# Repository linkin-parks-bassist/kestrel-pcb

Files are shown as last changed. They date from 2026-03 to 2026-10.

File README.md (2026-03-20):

# Kestrel PCB
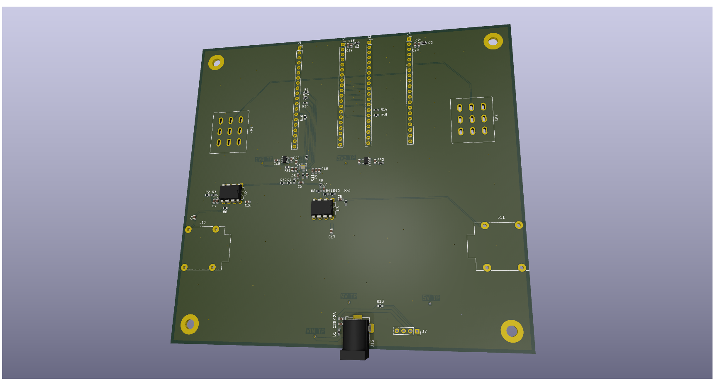
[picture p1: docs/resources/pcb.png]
KiCad


## Overview

This repository contains the KiCad design files for the main PCB used in Kestrel. The board integrates power distribution, audio I/O, and connectors for the Kestrel Core DSP module, Kestrel Interface control module, and a 5" LCD interface.

The PCB serves as the main carrier board for the system, providing regulated power rails, audio input/output stages, and interconnects between the DSP core, UI processor, and display.

## Dependencies

The board is designed to be used with the following additional components:

- Sipeed Tang Nano 20K (FPGA DSP core)
- Waveshare ESP32-P4-Pico (UI / control processor)
- Waveshare DSI-TOUCH-5A (5" MIPI-DSI display, connected to the ESP32-P4)
- Adafruit MPM3610 5V buck converter breakout

Note: the 5 V rail is currently generated using an external MPM3610 buck module. The PCB is designed so this can be replaced by an integrated regulator in a future revision.

## Power

The board is powered from a standard ***Center negative*** **9 V pedal supply**. The external buck module generates a 5V rail, from which the remaining rails are derived:

- 5 V (buck converter)
- 3.3 V 
- 1.8 V

## Project status

Prototype / Rev A. The design has not yet been manufactured and may change significantly.

## Files

This repository contains:

- KiCad schematic and PCB layout
- fabrication outputs (Gerbers, drill files) *to be added*
- board renders and screenshots

## Related projects

This board is part of Kestrel. Other repos in this project include

- [Main repo](https://github.com/linkin-parks-bassist/kestrel)
- [MCU repo](https://github.com/linkin-parks-bassist/kestrel-interface)
- [FPGA repo](https://github.com/linkin-parks-bassist/kestrel-core)

## License

GNU GPL 3.0

## Contact

I'd love to hear from you.  
email: davidjfarrell96@gmail.com

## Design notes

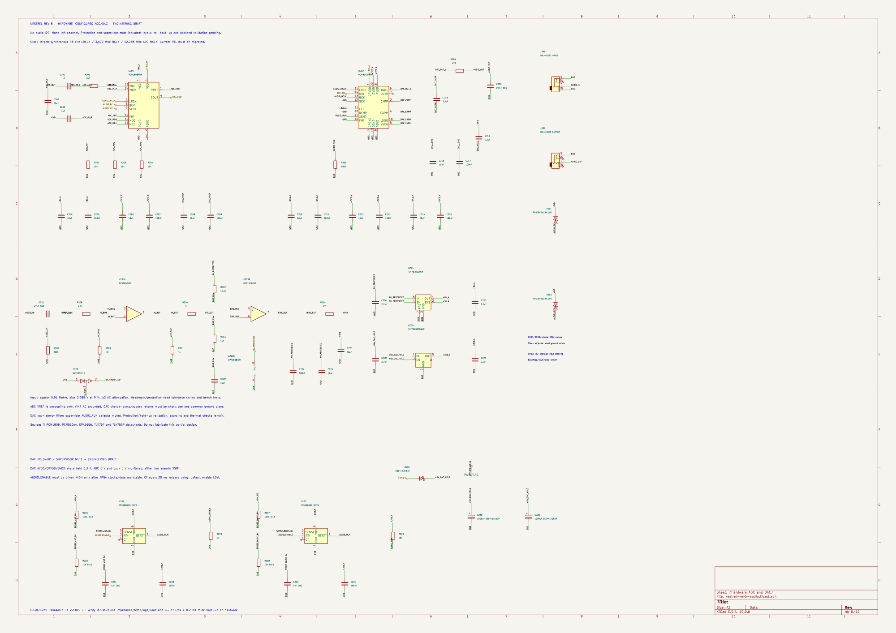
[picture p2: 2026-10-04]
rev-b/generated/review/kestrel-revb-Hardware ADC and DAC.png

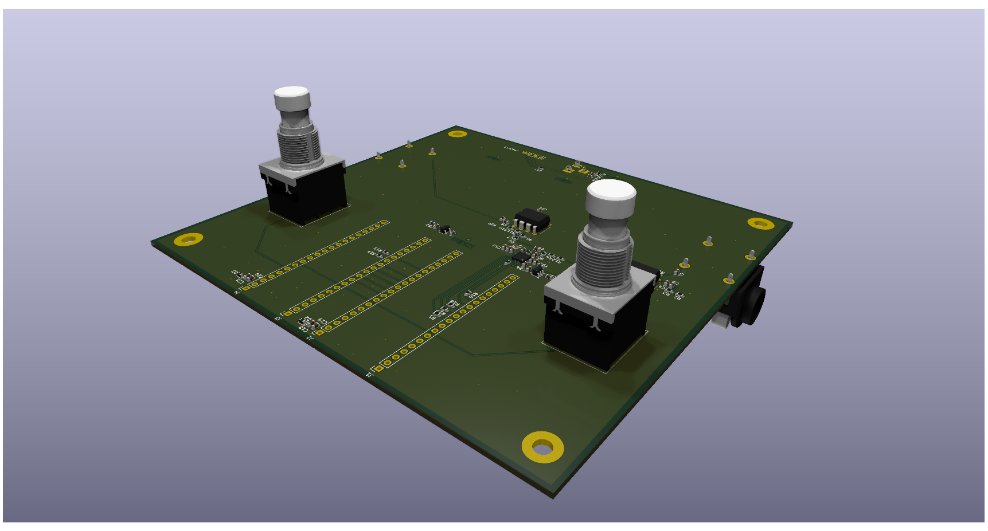
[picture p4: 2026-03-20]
docs/resources/kestrel_pcb_top.png

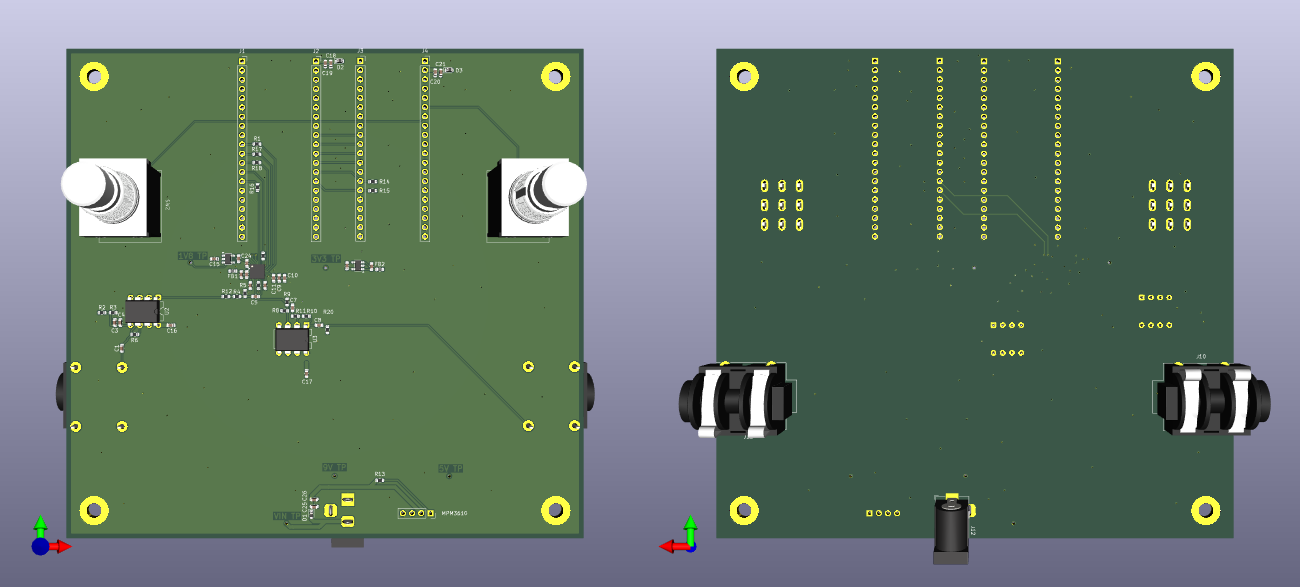
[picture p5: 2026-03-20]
docs/resources/kestrel_pcb_direct.png

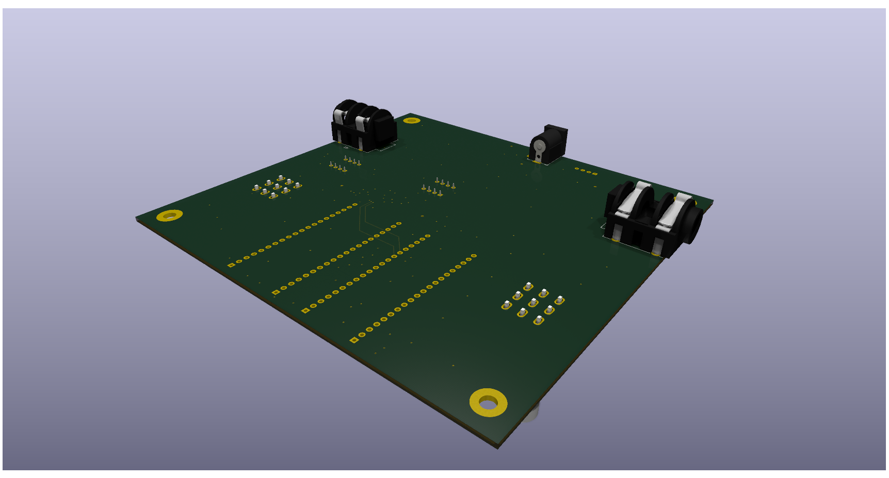
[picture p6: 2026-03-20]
docs/resources/kestrel_pcb_bot.png

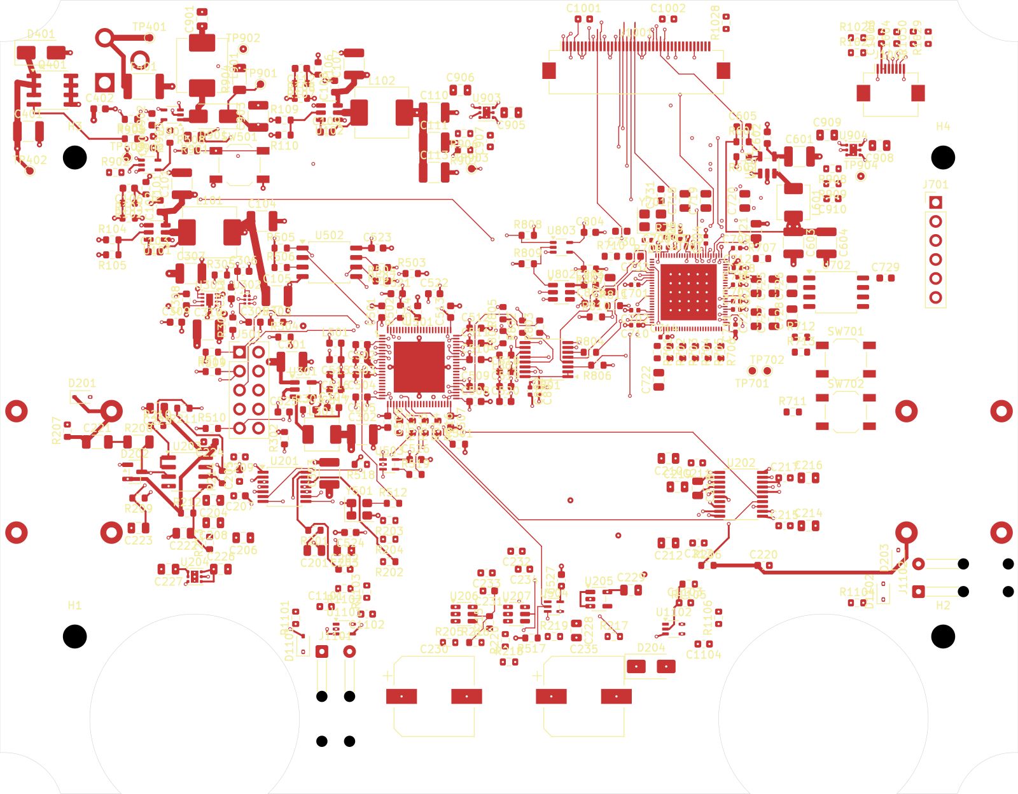
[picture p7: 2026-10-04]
rev-b/generated/pcb-hp-controls.png

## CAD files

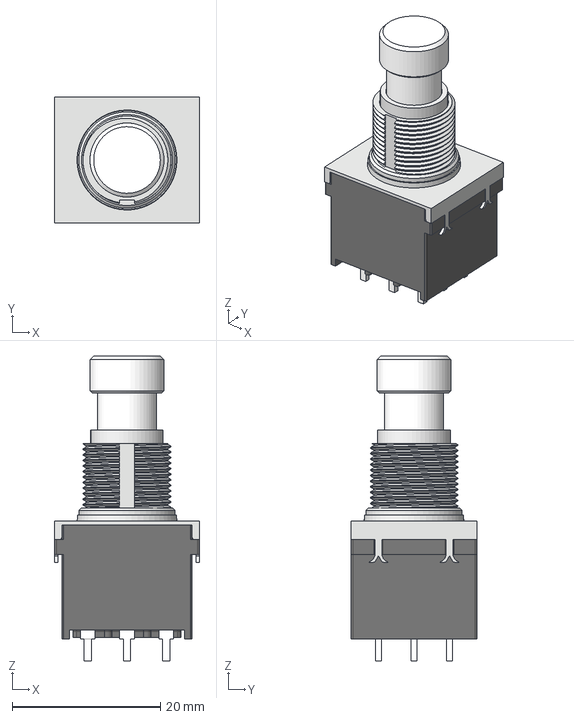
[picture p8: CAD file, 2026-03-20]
3dmodels/3pdt-footswitch/3PDT_Footswitch.step
19.6 x 17.0 x 41.2 mm

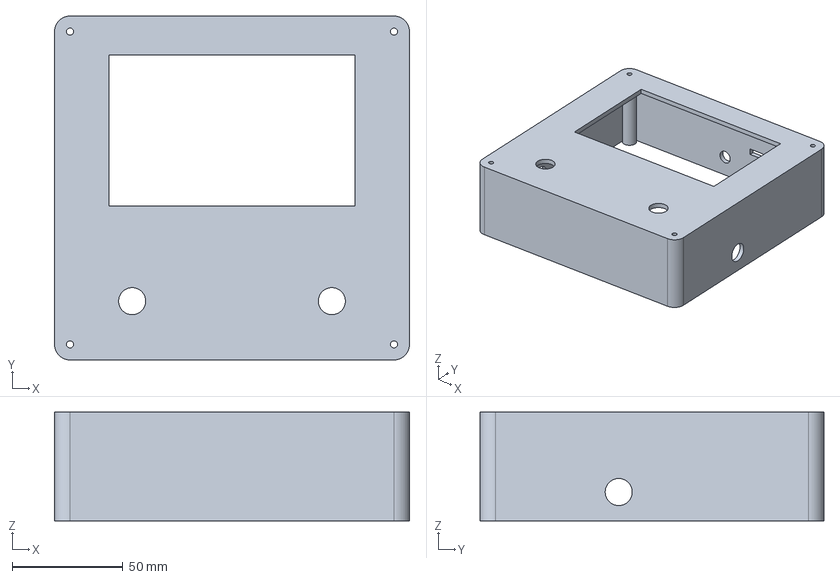
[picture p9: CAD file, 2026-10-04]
rev-b/generated/upper-shell.step
160.0 x 155.0 x 49.0 mm

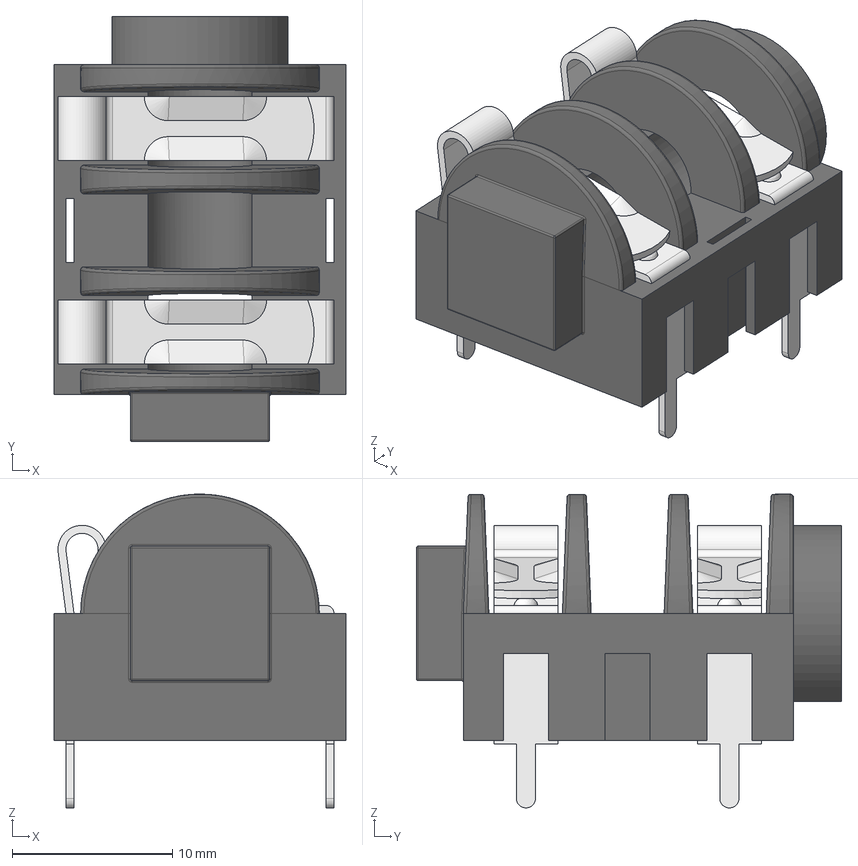
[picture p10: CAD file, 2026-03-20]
3dmodels/neutrik-nmj4hcd2/NMJ4HCD2.step
18.2 x 26.5 x 19.6 mm

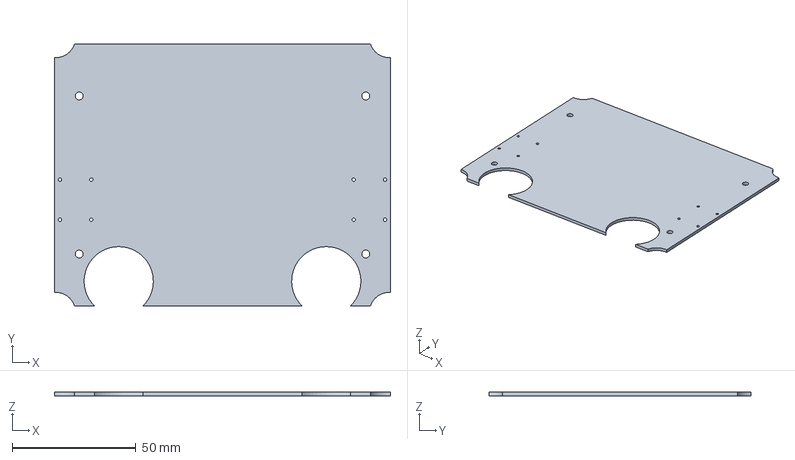
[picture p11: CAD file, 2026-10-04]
rev-b/generated/1590xx-pcb-candidate.step
136.0 x 106.0 x 1.60 mm

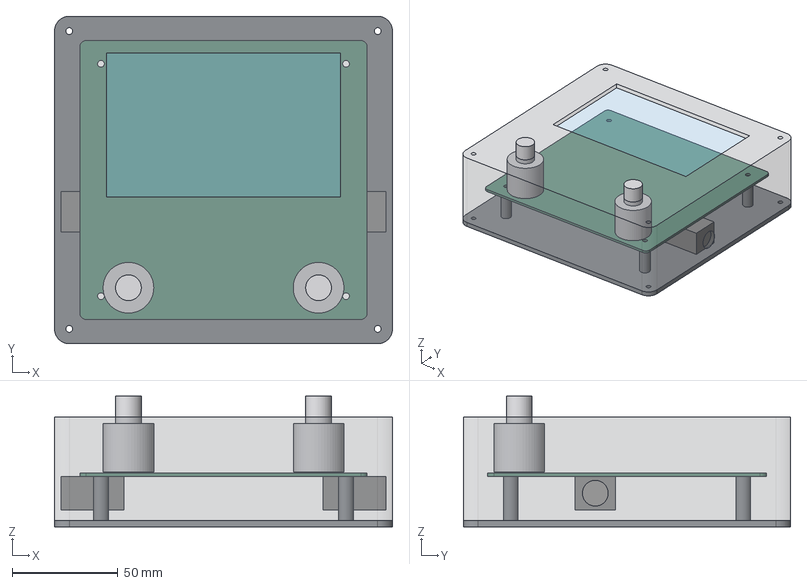
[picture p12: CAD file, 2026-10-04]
rev-b/generated/packaging-study.step
160.0 x 155.0 x 62.0 mm
upper_shell
removable_base
PCB_boundary_only
display_envelope_REFERENCE
switch_1_envelope_UNSELECTED
switch_2_envelope_UNSELECTED
input_jack_envelope_UNVERIFIED
output_jack_envelope_UNVERIFIED

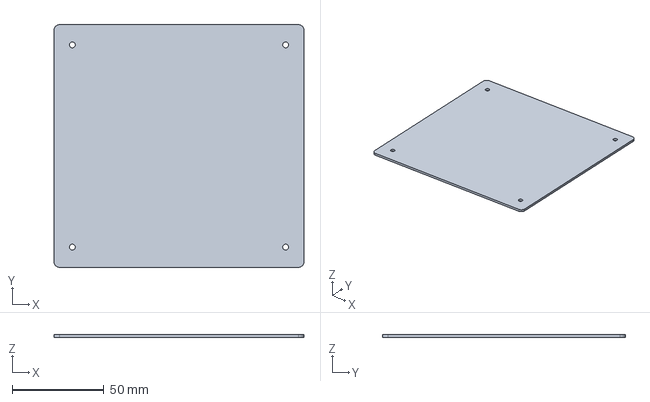
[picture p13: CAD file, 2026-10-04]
rev-b/generated/pcb-boundary.step
136.0 x 132.0 x 1.60 mm

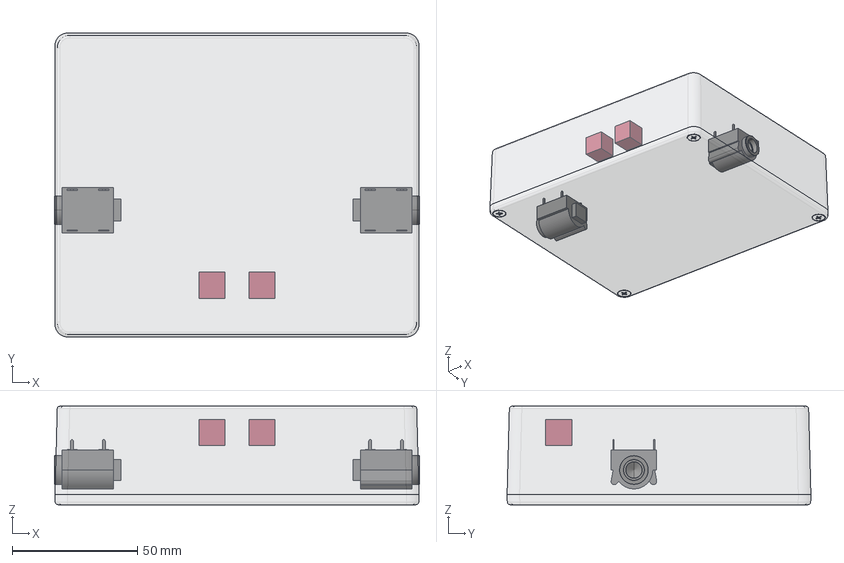
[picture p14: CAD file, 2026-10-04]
rev-b/generated/1590xx-reference-fit.step
145.6 x 121.2 x 39.3 mm
casting
lid
screw_1
screw_2
screw_3
screw_4
reference_display
switch_1_conservative_envelope
switch_2_conservative_envelope
candidate_notched_pcb
input_vendor_jack_body
output_vendor_jack_body
C230_maximum_body_envelope
C235_maximum_body_envelope

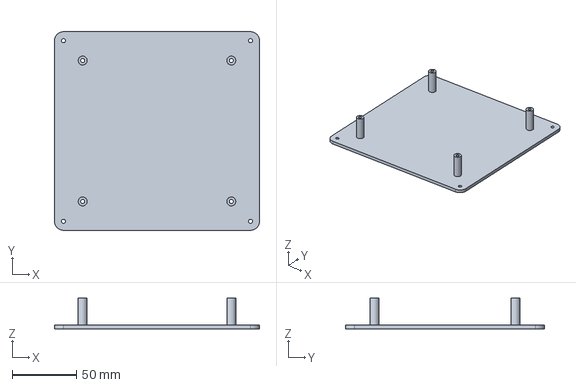
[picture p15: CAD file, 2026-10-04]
rev-b/generated/base.step
160.0 x 155.0 x 24.0 mm

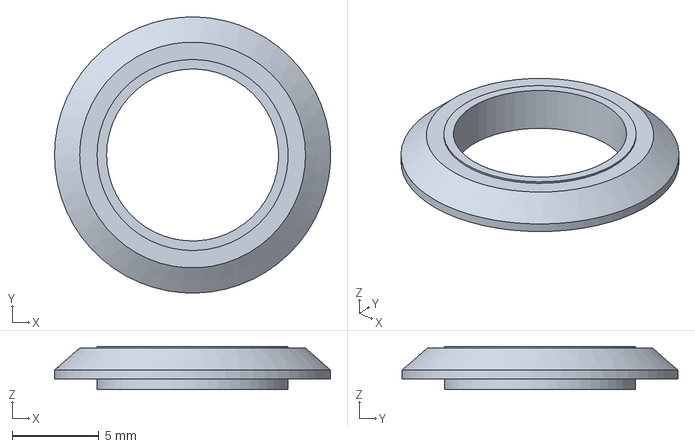
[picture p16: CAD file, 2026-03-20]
3dmodels/neutrik-nmj4hcd2/NMJ nut washer.step
15.9 x 15.9 x 2.50 mm

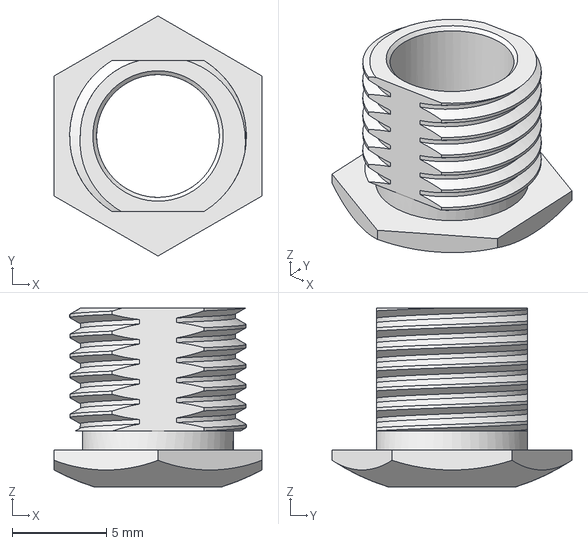
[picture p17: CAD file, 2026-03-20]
3dmodels/neutrik-nmj4hcd2/NMJ nut.step
11.0 x 12.7 x 9.45 mm

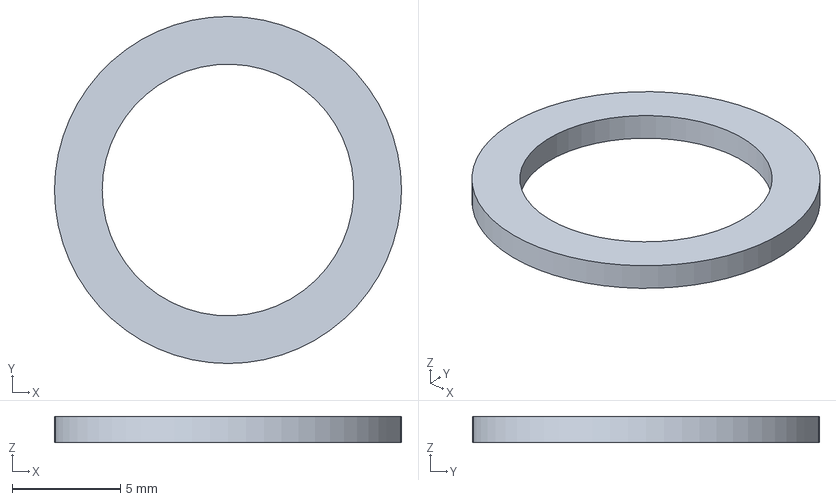
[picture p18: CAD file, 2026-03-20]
3dmodels/neutrik-nmj4hcd2/NMJ washer.step
16.0 x 16.0 x 1.20 mm

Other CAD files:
3dmodels/neutrik-nmj4hcd2/NMJ nut washer.f3d
3dmodels/neutrik-nmj4hcd2/NMJ nut.f3d
3dmodels/neutrik-nmj4hcd2/NMJ washer.f3d
3dmodels/neutrik-nmj4hcd2/NMJ4HCD2.f3d
rev-b/generated/base.stl
rev-b/generated/pcb-boundary.stl
rev-b/generated/upper-shell.stl

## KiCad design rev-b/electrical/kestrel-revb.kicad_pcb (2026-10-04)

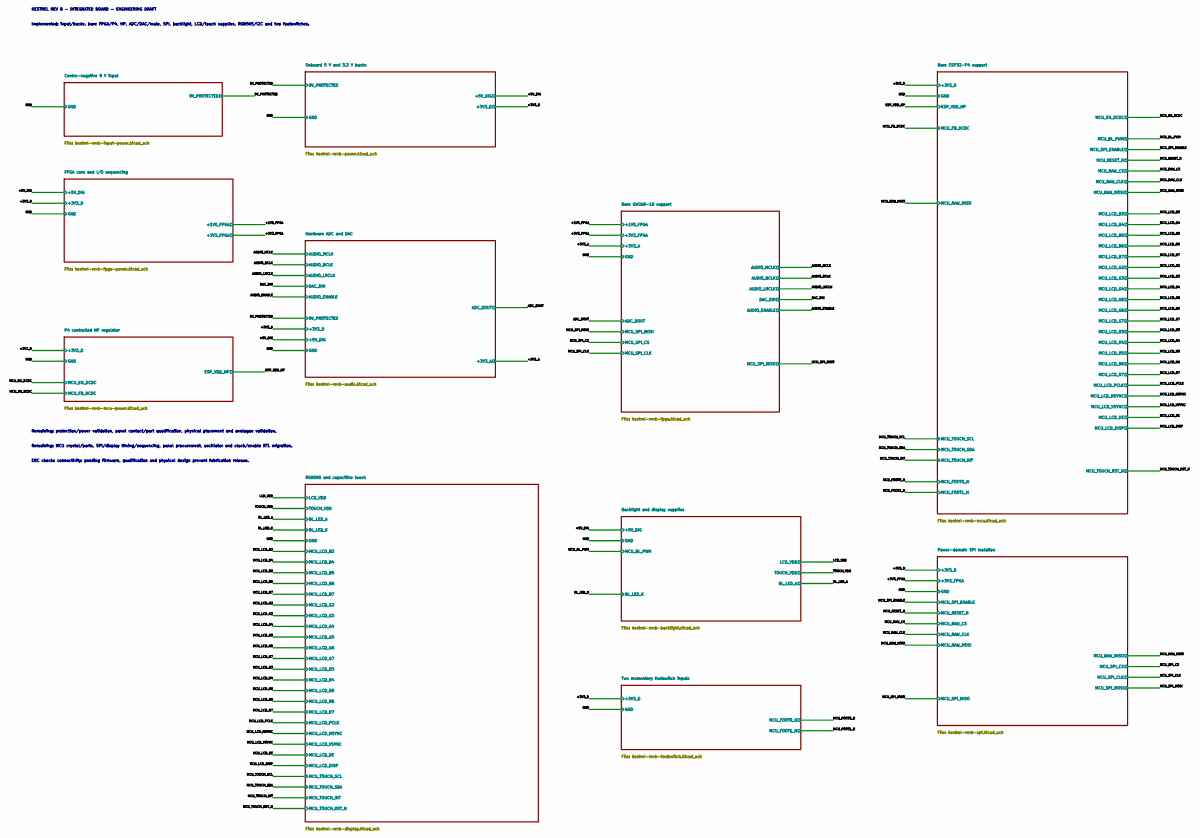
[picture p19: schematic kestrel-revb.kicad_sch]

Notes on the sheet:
KESTREL REV B - INTEGRATED BOARD - ENGINEERING DRAFT
Implemented: input/bucks, bare FPGA/P4, HP, ADC/DAC/mute, SPI, backlight, LCD/touch supplies, RGB565/I2C and two footswitches.
Remaining: protection/power validation, panel contact/part qualification, physical placement and analogue validation.
Remaining: MCU crystal/parts, SPI/display timing/sequencing, panel procurement, oscillator and clock/enable RTL migration.
ERC checks connectivity; pending firmware, qualification and physical design prevent fabrication release.

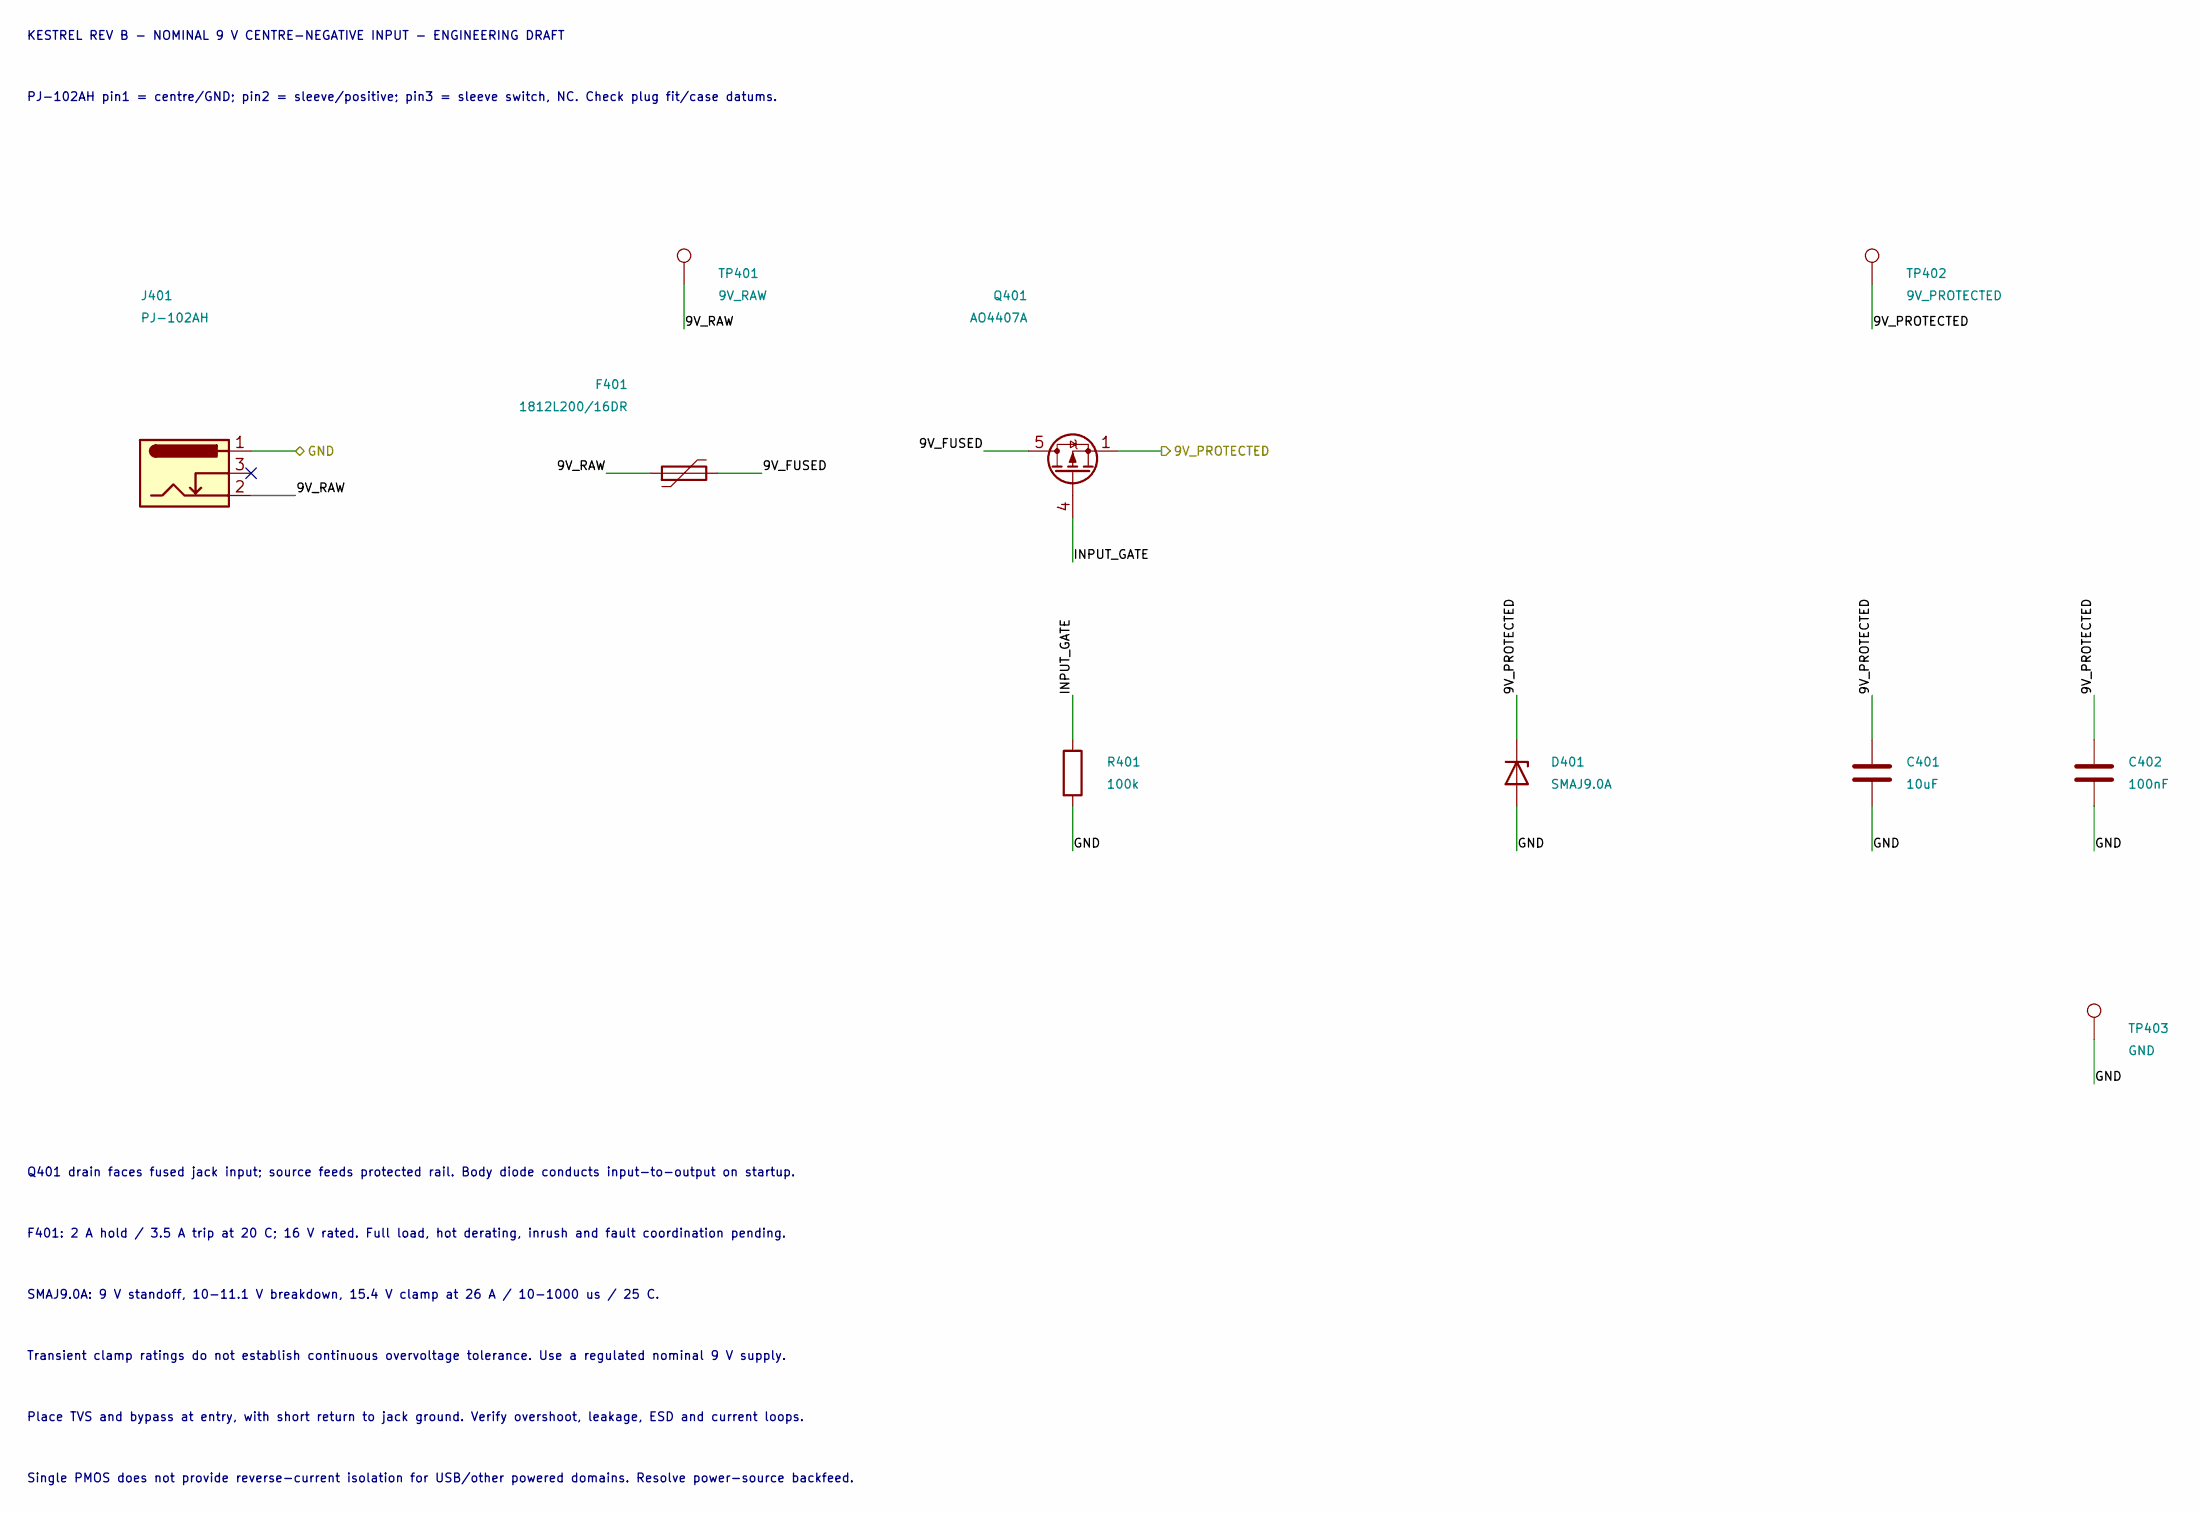
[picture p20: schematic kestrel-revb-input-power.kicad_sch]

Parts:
C401: 10uF; C_1210_3225Metric; Rating 10uF / 35V X7R
C402: 100nF; C_0603_1608Metric; Rating 100nF / 50V X7R
D401: SMAJ9.0A; D_SMA
F401: 1812L200/16DR; Fuse_1812_4532Metric
J401: PJ-102AH; BarrelJack_CUI_PJ-102AH_Horizontal
Q401: AO4407A; SOIC-8_3.9x4.9mm_P1.27mm
R401: 100k; R_0603_1608Metric; Rating 100k / 1%
TP401: 9V_RAW; TestPoint_Pad_D1.0mm
TP402: 9V_PROTECTED; TestPoint_Pad_D1.0mm
TP403: GND; TestPoint_Pad_D1.0mm

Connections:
/9V_PROTECTED: C401.1, C402.1, D401.1 (K), Q401.1 (S), Q401.2 (S), Q401.3 (S), TP402.1; also elsewhere on the board
/Centre-negative 9 V input/9V_FUSED: F401.2, Q401.5 (D), Q401.6 (D), Q401.7 (D), Q401.8 (D)
/Centre-negative 9 V input/9V_RAW: F401.1, J401.2, TP401.1
/Centre-negative 9 V input/INPUT_GATE: Q401.4 (G), R401.1
/GND: C401.2, C402.2, D401.2 (A), J401.1, R401.2, TP403.1; also elsewhere on the board

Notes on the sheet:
KESTREL REV B - NOMINAL 9 V CENTRE-NEGATIVE INPUT - ENGINEERING DRAFT
PJ-102AH pin1 = centre/GND; pin2 = sleeve/positive; pin3 = sleeve switch, NC. Check plug fit/case datums.
Q401 drain faces fused jack input; source feeds protected rail. Body diode conducts input-to-output on startup.
F401: 2 A hold / 3.5 A trip at 20 C; 16 V rated. Full load, hot derating, inrush and fault coordination pending.
SMAJ9.0A: 9 V standoff, 10-11.1 V breakdown, 15.4 V clamp at 26 A / 10-1000 us / 25 C.
Transient clamp ratings do not establish continuous overvoltage tolerance. Use a regulated nominal 9 V supply.
Place TVS and bypass at entry, with short return to jack ground. Verify overshoot, leakage, ESD and current loops.
Single PMOS does not provide reverse-current isolation for USB/other powered domains. Resolve power-source backfeed.

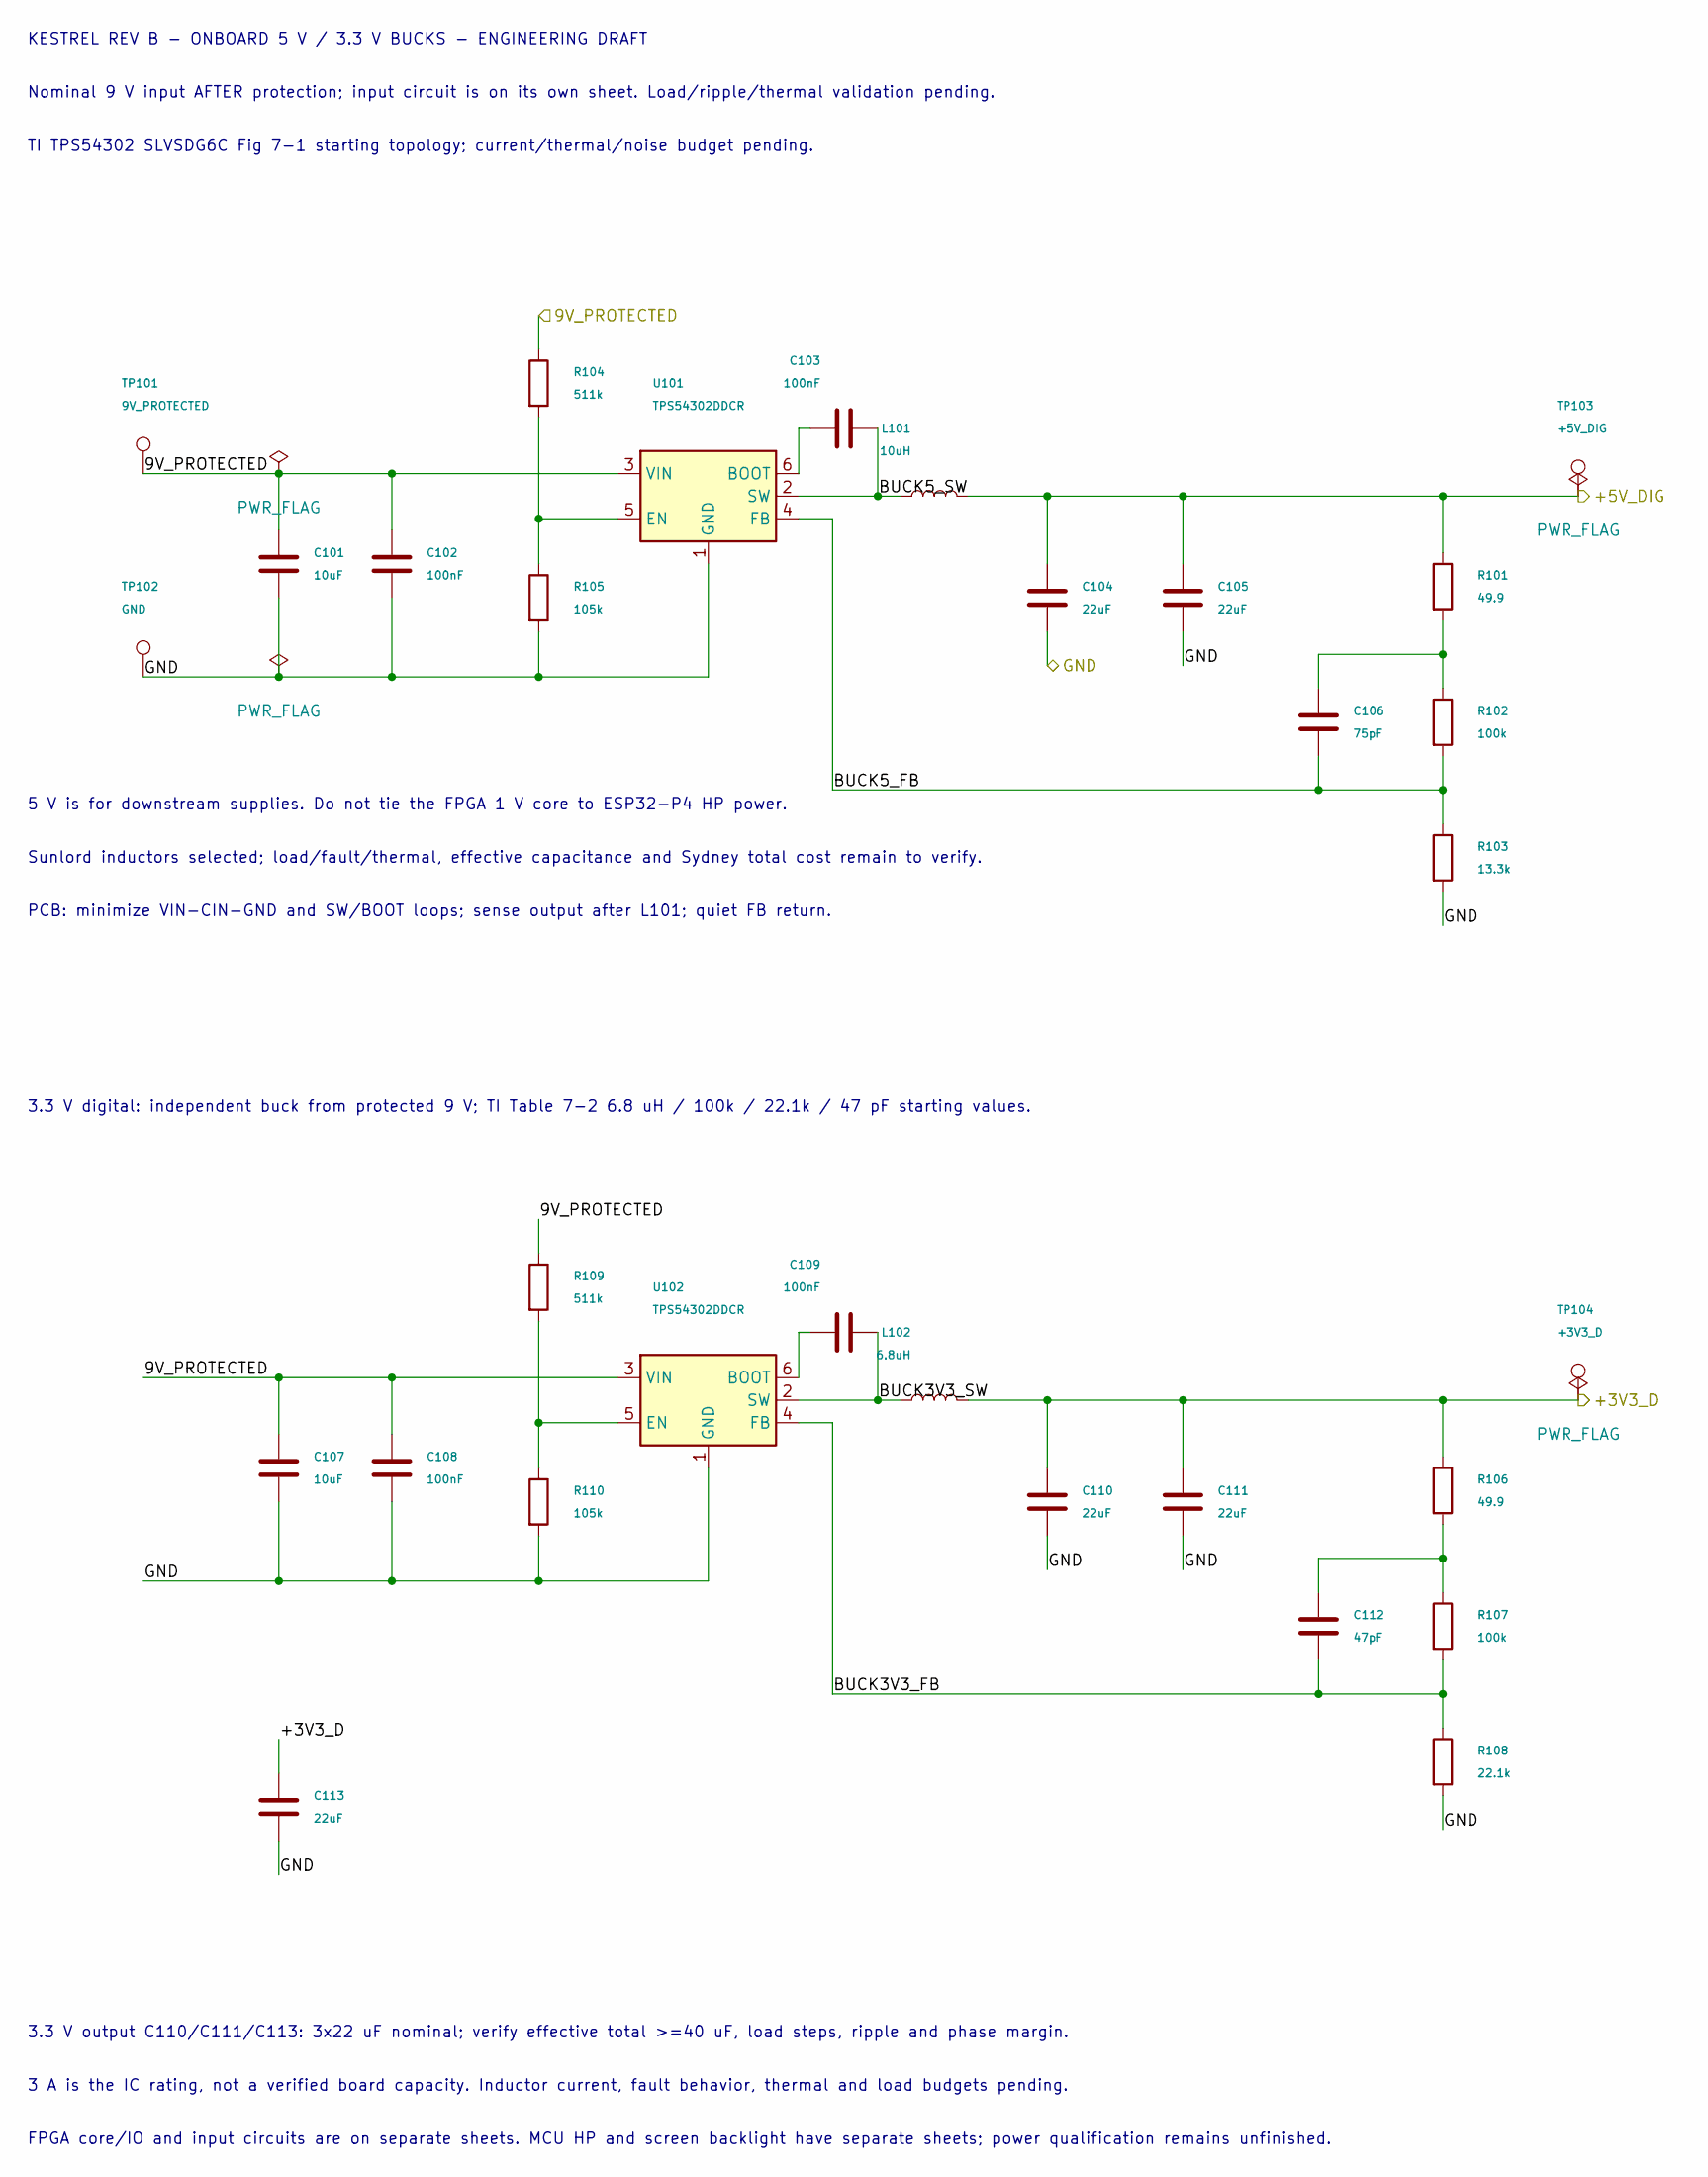
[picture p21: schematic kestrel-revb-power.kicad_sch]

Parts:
C101, C107: 10uF; C_1210_3225Metric; Rating 10uF / 35V X7R
C102, C103, C108, C109: 100nF; C_0603_1608Metric; Rating 100nF / 25V
C104, C105, C110, C111, C113: 22uF; C_1210_3225Metric; Rating 22uF / 25V X7R
C106: 75pF; C_0603_1608Metric; Rating 75pF / C0G
C112: 47pF; C_0603_1608Metric; Rating 47pF / C0G
L101: 10uH; L_Sunlord_MWSA0603S; Rating 10uH / Isat >= 4.3A / shielded; MPN MWSA0603S-100MT; LCSC C132141
L102: 6.8uH; L_Sunlord_MWSA0603S; Rating 6.8uH / Isat >= 4.3A / shielded; MPN MWSA0603S-6R8MT; LCSC C408449
R101, R106: 49.9; R_0603_1608Metric; Rating 49.9 / 1%
R102: 100k; R_0603_1608Metric; Rating 100k / 1%
R103: 13.3k; R_0603_1608Metric; Rating 13.3k / 1%
R104, R109: 511k; R_0603_1608Metric; Rating 511k / 1%
R105, R110: 105k; R_0603_1608Metric; Rating 105k / 1%
R107: 100k; R_0603_1608Metric; Rating 100k / 0.1%
R108: 22.1k; R_0603_1608Metric; Rating 22.1k / 0.1%
TP101: 9V_PROTECTED; TestPoint_Pad_D1.0mm
TP102: GND; TestPoint_Pad_D1.0mm
TP103: +5V_DIG; TestPoint_Pad_D1.0mm
TP104: +3V3_D; TestPoint_Pad_D1.0mm
U101, U102: TPS54302DDCR; SOT-23-6

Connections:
/9V_PROTECTED: C101.1, C102.1, C107.1, C108.1, R104.1, R109.1, TP101.1, U101.3 (VIN), U102.3 (VIN); also elsewhere on the board
/+3V3_D: C110.1, C111.1, C113.1, L102.2, R106.1, TP104.1; also elsewhere on the board
/+5V_DIG: C104.1, C105.1, L101.2, R101.1, TP103.1; also elsewhere on the board
/GND: C101.2, C102.2, C104.2, C105.2, C107.2, C108.2, C110.2, C111.2, C113.2, R103.2, R105.2, R108.2, R110.2, TP102.1, U101.1 (GND), U102.1 (GND); also elsewhere on the board
/Onboard 5 V and 3.3 V bucks/BUCK3V3_FB: C112.2, R107.2, R108.1, U102.4 (FB)
/Onboard 5 V and 3.3 V bucks/BUCK3V3_SW: C109.2, L102.1, U102.2 (SW)
/Onboard 5 V and 3.3 V bucks/BUCK5_FB: C106.2, R102.2, R103.1, U101.4 (FB)
/Onboard 5 V and 3.3 V bucks/BUCK5_SW: C103.2, L101.1, U101.2 (SW)
unnamed: C106.1, R101.2, R102.1
unnamed: C112.1, R106.2, R107.1
unnamed: C103.1, U101.6 (BOOT)
unnamed: R104.2, R105.1, U101.5 (EN)
unnamed: C109.1, U102.6 (BOOT)
unnamed: R109.2, R110.1, U102.5 (EN)

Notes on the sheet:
KESTREL REV B - ONBOARD 5 V / 3.3 V BUCKS - ENGINEERING DRAFT
Nominal 9 V input AFTER protection; input circuit is on its own sheet. Load/ripple/thermal validation pending.
TI TPS54302 SLVSDG6C Fig 7-1 starting topology; current/thermal/noise budget pending.
5 V is for downstream supplies. Do not tie the FPGA 1 V core to ESP32-P4 HP power.
Sunlord inductors selected; load/fault/thermal, effective capacitance and Sydney total cost remain to verify.
PCB: minimize VIN-CIN-GND and SW/BOOT loops; sense output after L101; quiet FB return.
3.3 V digital: independent buck from protected 9 V; TI Table 7-2 6.8 uH / 100k / 22.1k / 47 pF starting values.
3.3 V output C110/C111/C113: 3x22 uF nominal; verify effective total >=40 uF, load steps, ripple and phase margin.
3 A is the IC rating, not a verified board capacity. Inductor current, fault behavior, thermal and load budgets pending.
FPGA core/IO and input circuits are on separate sheets. MCU HP and screen backlight have separate sheets; power qualification remains unfinished.

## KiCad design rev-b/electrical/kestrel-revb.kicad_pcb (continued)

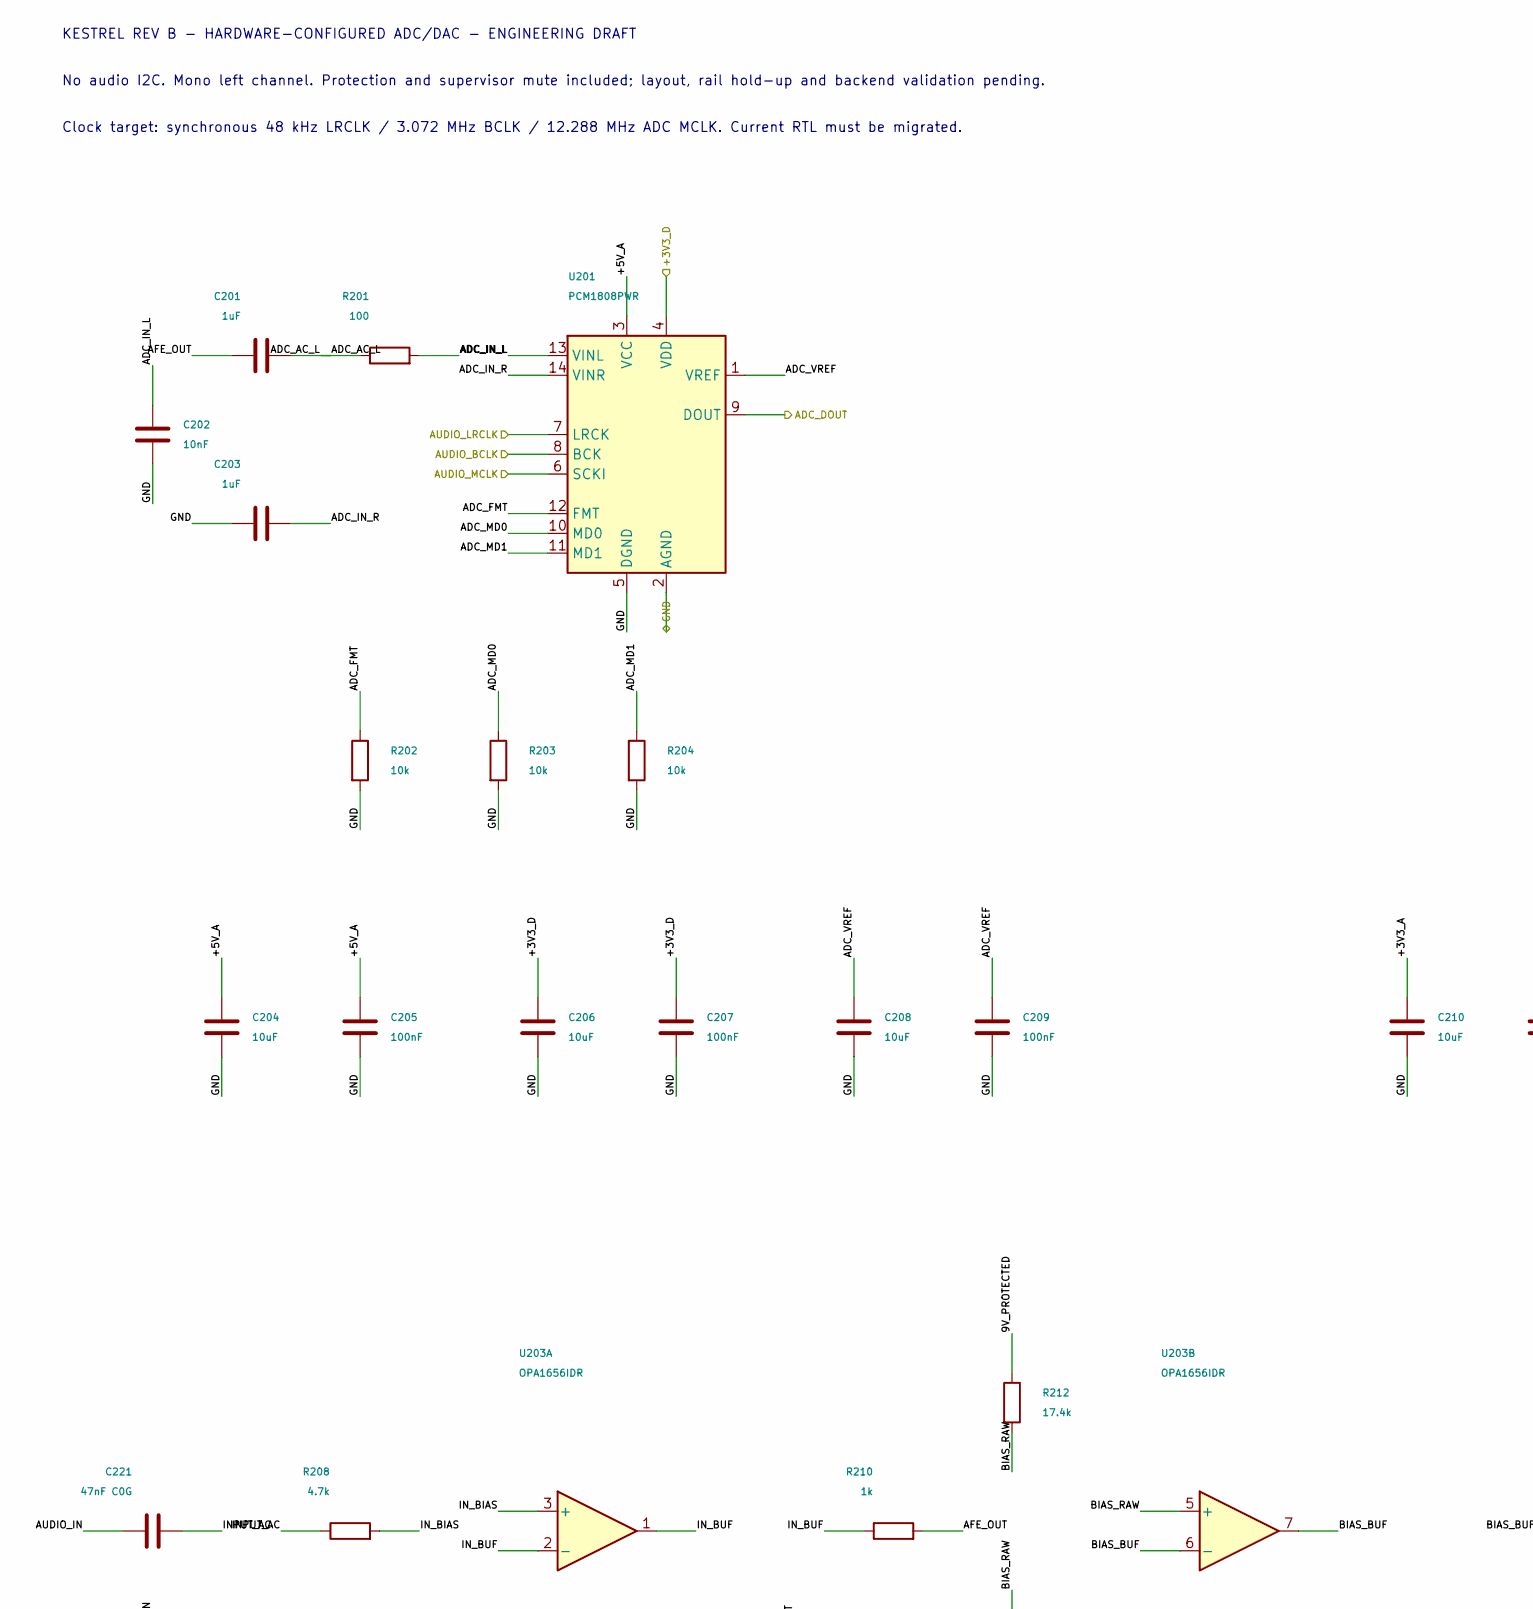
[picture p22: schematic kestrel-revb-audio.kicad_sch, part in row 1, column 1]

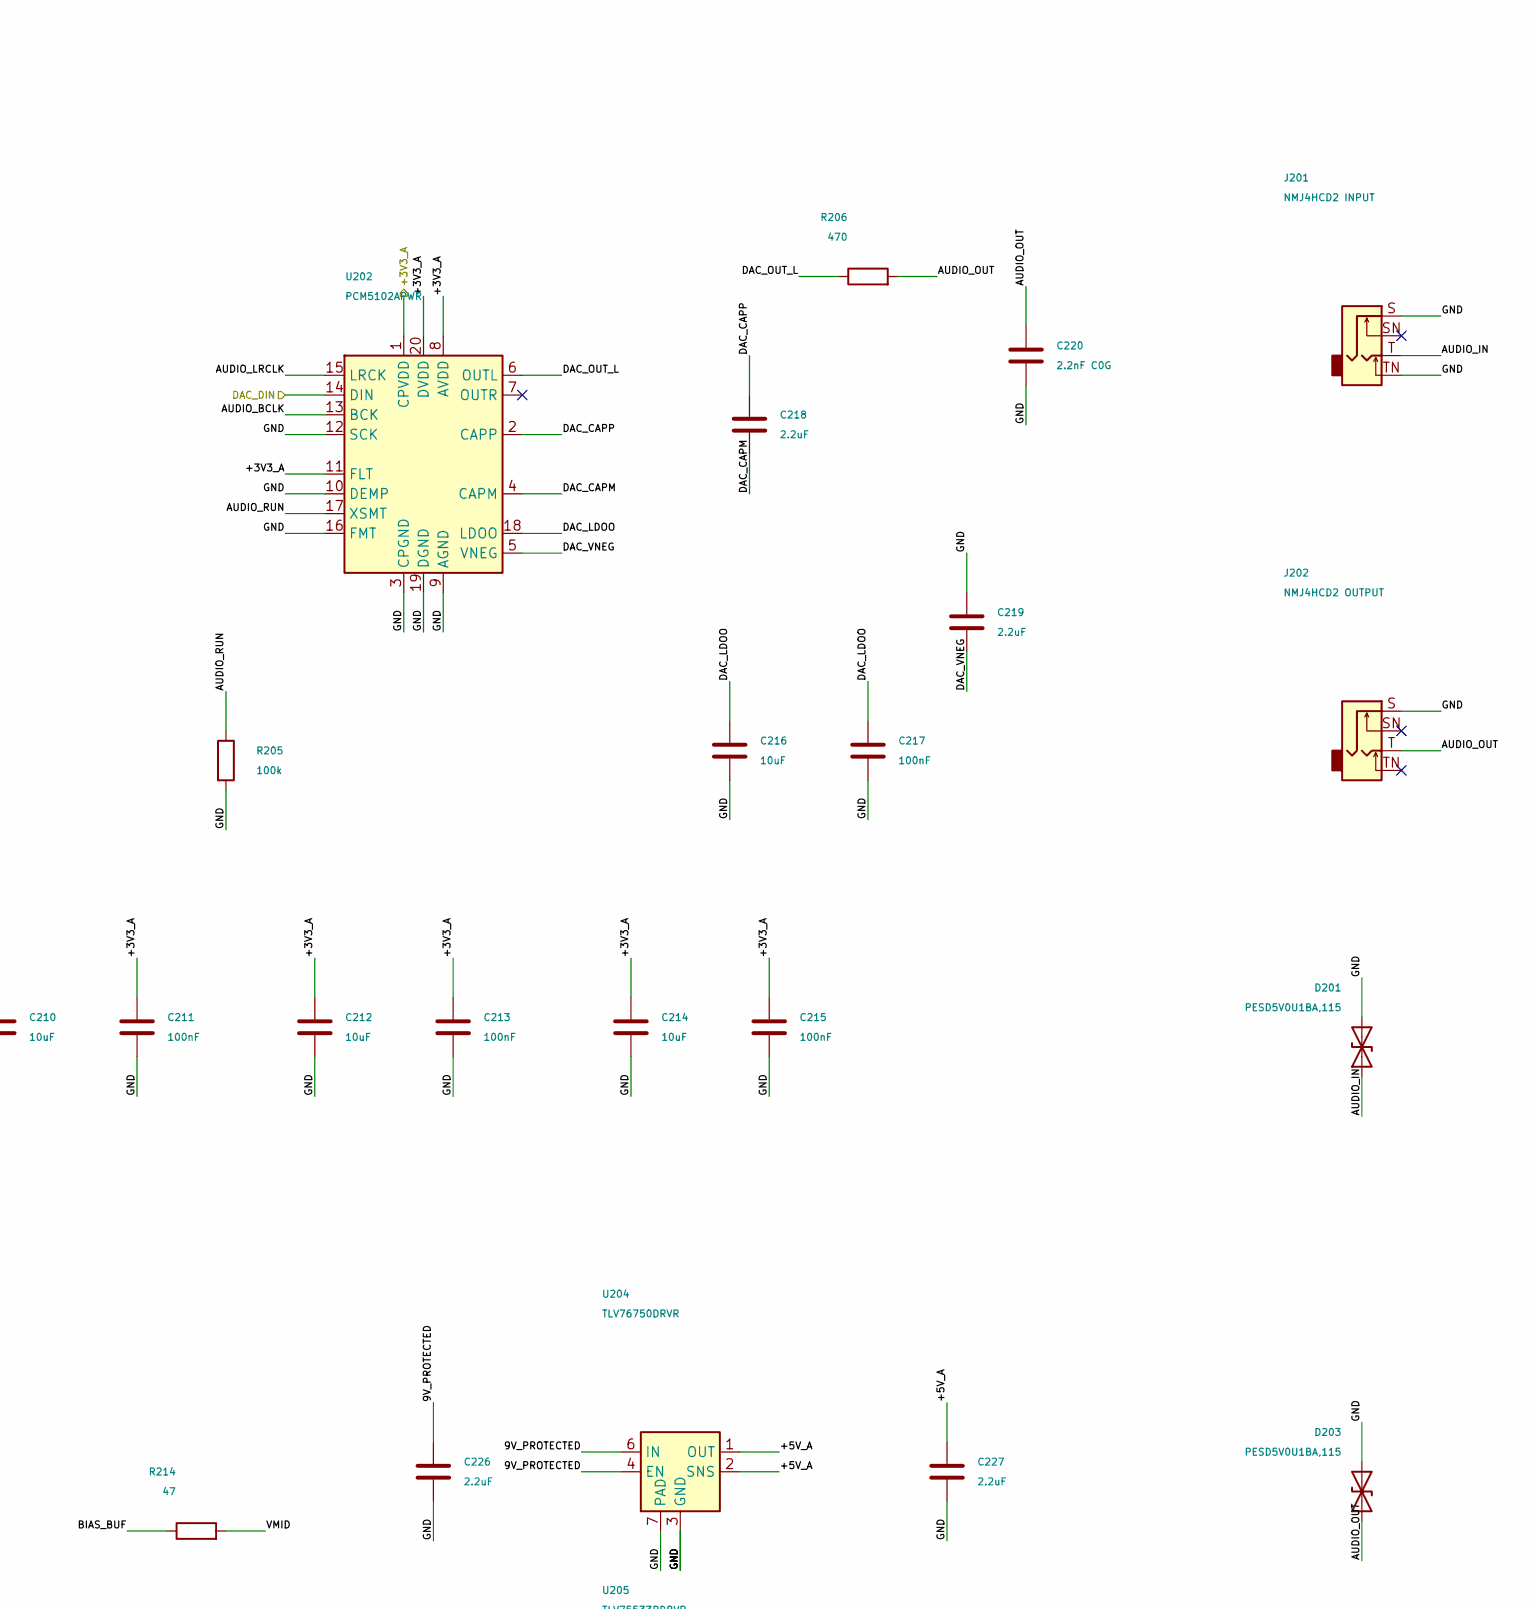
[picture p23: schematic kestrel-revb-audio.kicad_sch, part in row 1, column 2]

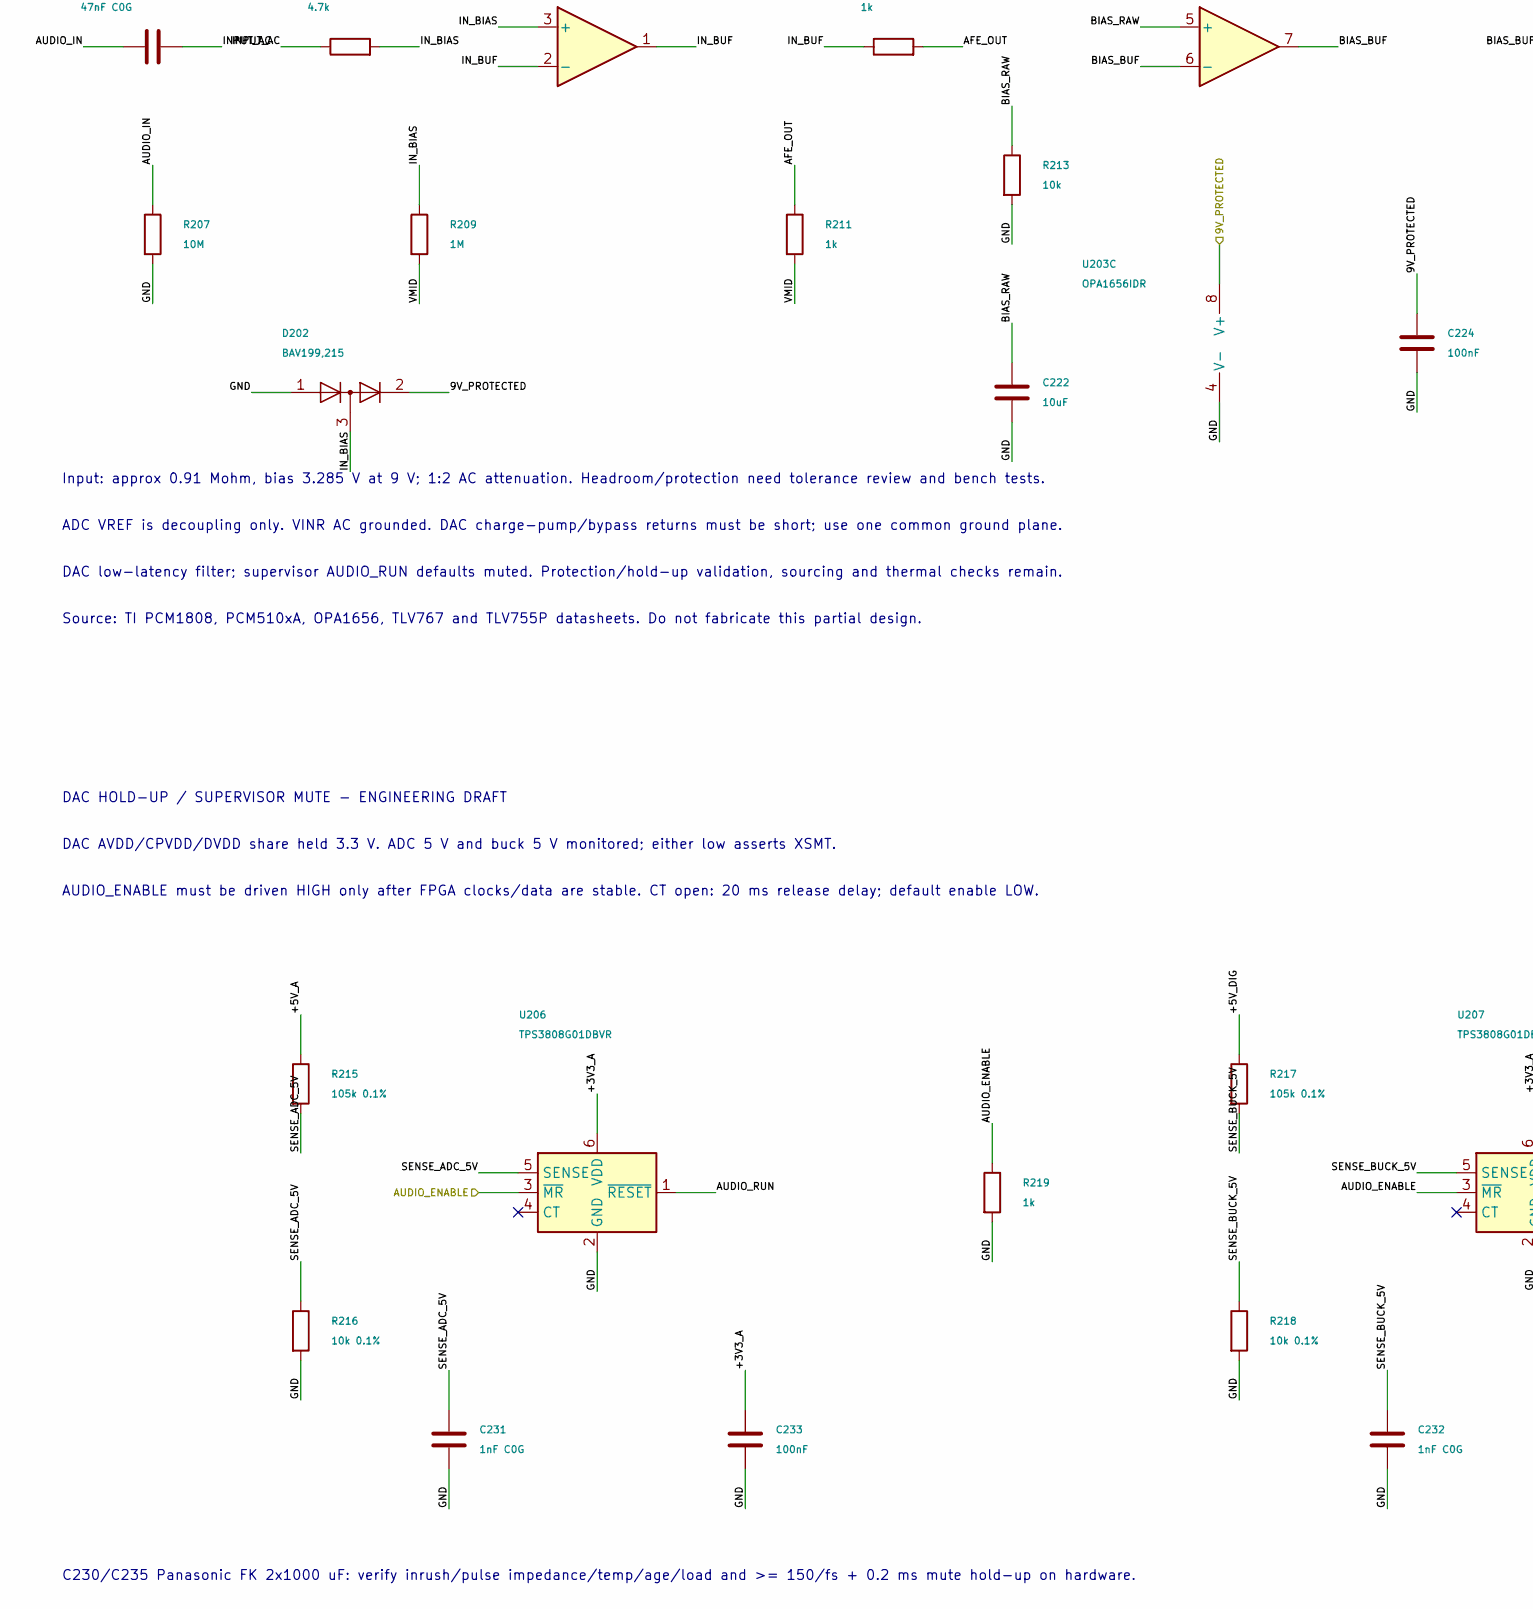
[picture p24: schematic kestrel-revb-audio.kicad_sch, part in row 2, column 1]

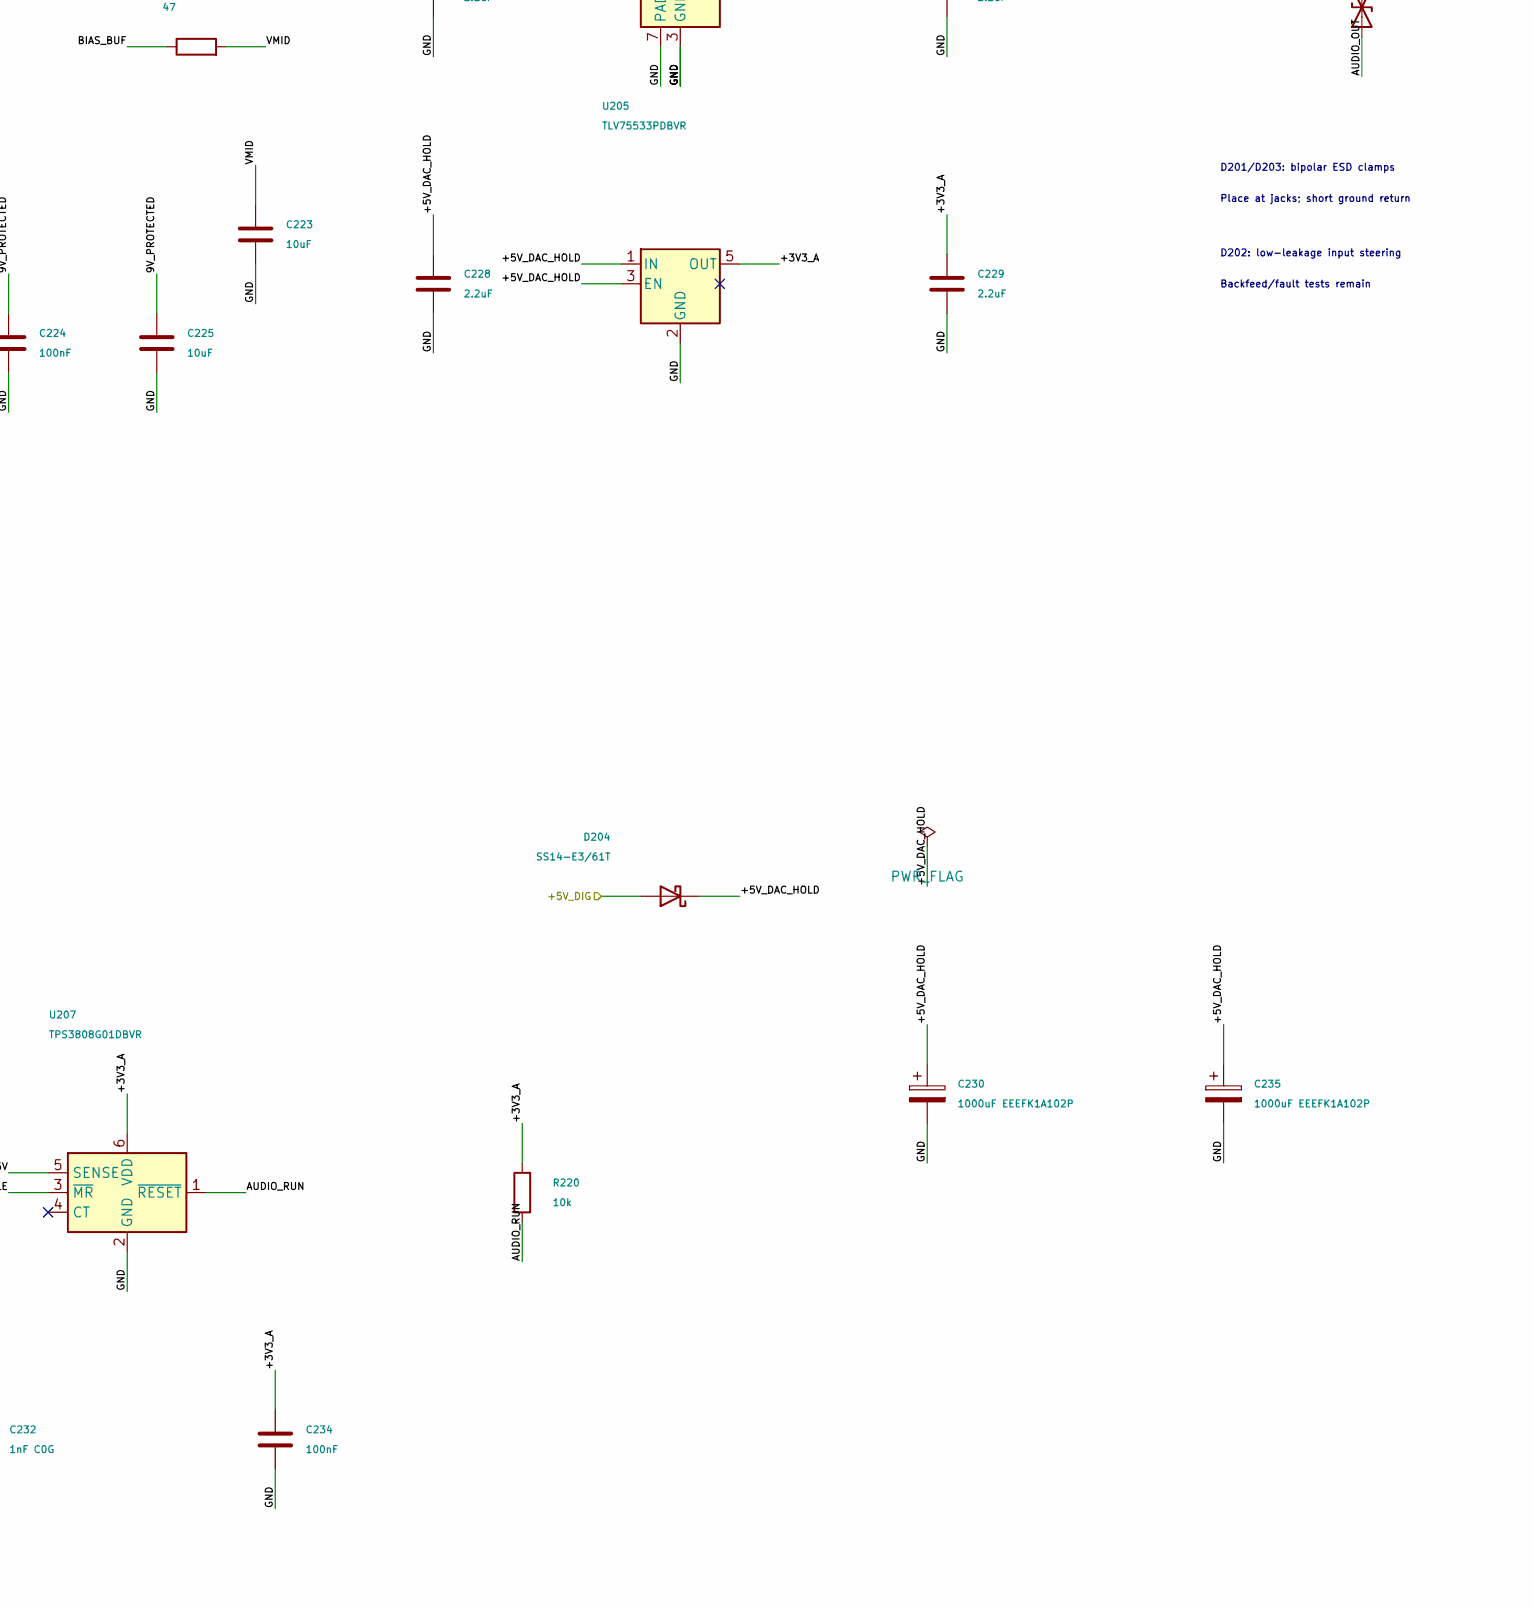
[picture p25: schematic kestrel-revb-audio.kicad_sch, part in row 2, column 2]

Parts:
C201, C203: 1uF; C_0805_2012Metric; Rating 16 V minimum; bulk effective capacitanc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
C202: 10nF; C_0603_1608Metric; Rating 16 V minimum; bulk effective capacitanc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
C204, C206, C208, C210, C212, C214, C216, C222, C223, C225: 10uF; C_0805_2012Metric; Rating 16 V minimum; bulk effective capacitanc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
C205, C207, C209, C211, C213, C215, C217, C224, C233, C234: 100nF; C_0603_1608Metric; Rating 16 V minimum; bulk effective capacitanc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
C218, C219, C226, C227, C228, C229: 2.2uF; C_0805_2012Metric; Rating 16 V minimum; bulk effective capacitanc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
C220: 2.2nF C0G; C_0603_1608Metric; Rating 16 V minimum; bulk effective capacitanc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
C221: 47nF C0G; C_1206_3216Metric; Rating 50 V C0G; input transient barrier
C230, C235: 1000uF EEEFK1A102P; CP_Elec_Panasonic_FK_G_10x10.2; Rating 10 V; +/-20 percent at 20 C; 2000 h at 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; MPN EEEFK1A102P; LCSC C278397
C231, C232: 1nF C0G; C_0603_1608Metric; Rating 16 V minimum; bulk effective capacitanc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
D201, D203: PESD5V0U1BA,115; D_SOD-323
D202: BAV199,215; SOT-23
D204: SS14-E3/61T; D_SMA
J201: NMJ4HCD2 INPUT; Jack_6.35mm_Neutrik_NMJ4HCD2_Horizontal
J202: NMJ4HCD2 OUTPUT; Jack_6.35mm_Neutrik_NMJ4HCD2_Horizontal
R201: 100; R_0603_1608Metric
R202, R203, R204, R213, R220: 10k; R_0603_1608Metric
R205: 100k; R_0603_1608Metric
R206: 470; R_0603_1608Metric
R207: 10M; R_0603_1608Metric
R208: 4.7k; R_1206_3216Metric; Rating 1 percent; 0.25 W minimum; pulse rating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
R209: 1M; R_0603_1608Metric
R210, R211, R219: 1k; R_0603_1608Metric
R212: 17.4k; R_0603_1608Metric
R214: 47; R_0603_1608Metric
R215, R217: 105k 0.1%; R_0603_1608Metric
R216, R218: 10k 0.1%; R_0603_1608Metric
U201: PCM1808PWR; TSSOP-14_4.4x5mm_P0.65mm
U202: PCM5102APWR; TSSOP-20_4.4x6.5mm_P0.65mm
U203: OPA1656IDR; SOIC-8_3.9x4.9mm_P1.27mm
U204: TLV76750DRVR; WSON-6-1EP_2x2mm_P0.65mm_EP1x1.6mm_ThermalVias
U205: TLV75533PDBVR; SOT-23-5
U206, U207: TPS3808G01DBVR; SOT-23-6

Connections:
/9V_PROTECTED: C224.1, C225.1, C226.1, D202.2 (K2), R212.1, U203.8 (V+), U204.4 (EN), U204.6 (IN); also elsewhere on the board
/+3V3_A: C210.1, C211.1, C212.1, C213.1, C214.1, C215.1, C229.1, C233.1, C234.1, R220.1, U202.1 (CPVDD), U202.8 (AVDD), U202.11 (FLT), U202.20 (DVDD), U205.5 (OUT), U206.6 (VDD), U207.6 (VDD); also elsewhere on the board
/+3V3_D: C206.1, C207.1, U201.4 (VDD); also elsewhere on the board
/+5V_DIG: D204.2 (A), R217.1; also elsewhere on the board
/ADC_DOUT: U201.9 (DOUT); also elsewhere on the board
/AUDIO_BCLK: U201.8 (BCK), U202.13 (BCK); also elsewhere on the board
/AUDIO_ENABLE: R219.1, U206.3 (~MR), U207.3 (~MR); also elsewhere on the board
/AUDIO_LRCLK: U201.7 (LRCK), U202.15 (LRCK); also elsewhere on the board
/AUDIO_MCLK: U201.6 (SCKI); also elsewhere on the board
/DAC_DIN: U202.14 (DIN); also elsewhere on the board
/GND: C202.2, C203.1, C204.2, C205.2, C206.2, C207.2, C208.2, C209.2, C210.2, C211.2, C212.2, C213.2, C214.2, C215.2, C216.2, C217.2, C219.1, C220.2, C222.2, C223.2, C224.2, C225.2, C226.2, C227.2, C228.2, C229.2, C230.2, C231.2, C232.2, C233.2, C234.2, C235.2, D201.2 (A2), D202.1 (A1), D203.2 (A2), J201.S, J201.TN, J202.S, R202.2, R203.2, R204.2, R205.2, R207.2, R213.2, R216.2, R218.2, R219.2, U201.2 (AGND), U201.5 (DGND), U202.3 (CPGND), U202.9 (AGND), U202.10 (DEMP), U202.12 (SCK), U202.16 (FMT), U202.19 (DGND), U203.4 (V-), U204.3 (GND), U204.5 (GND), U204.7 (PAD), U205.2 (GND), U206.2 (GND), U207.2 (GND); also elsewhere on the board
/Hardware ADC and DAC/+5V_A: C204.1, C205.1, C227.1, R215.1, U201.3 (VCC), U204.1 (OUT), U204.2 (SNS)
/Hardware ADC and DAC/+5V_DAC_HOLD: C228.1, C230.1, C235.1, D204.1 (K), U205.1 (IN), U205.3 (EN)
/Hardware ADC and DAC/ADC_AC_L: C201.2, R201.1
/Hardware ADC and DAC/ADC_FMT: R202.1, U201.12 (FMT)
/Hardware ADC and DAC/ADC_IN_L: C202.1, R201.2, U201.13 (VINL)
/Hardware ADC and DAC/ADC_IN_R: C203.2, U201.14 (VINR)
/Hardware ADC and DAC/ADC_MD0: R203.1, U201.10 (MD0)
/Hardware ADC and DAC/ADC_MD1: R204.1, U201.11 (MD1)
/Hardware ADC and DAC/ADC_VREF: C208.1, C209.1, U201.1 (VREF)
/Hardware ADC and DAC/AFE_OUT: C201.1, R210.2, R211.1
/Hardware ADC and DAC/AUDIO_IN: C221.1, D201.1 (A1), J201.T, R207.1
/Hardware ADC and DAC/AUDIO_OUT: C220.1, D203.1 (A1), J202.T, R206.2
/Hardware ADC and DAC/AUDIO_RUN: R205.1, R220.2, U202.17 (XSMT), U206.1 (~RESET), U207.1 (~RESET)
/Hardware ADC and DAC/BIAS_BUF: R214.1, U203.6 (-), U203.7
/Hardware ADC and DAC/BIAS_RAW: C222.1, R212.2, R213.1, U203.5 (+)
/Hardware ADC and DAC/DAC_CAPM: C218.2, U202.4 (CAPM)
/Hardware ADC and DAC/DAC_CAPP: C218.1, U202.2 (CAPP)
/Hardware ADC and DAC/DAC_LDOO: C216.1, C217.1, U202.18 (LDOO)
/Hardware ADC and DAC/DAC_OUT_L: R206.1, U202.6 (OUTL)
/Hardware ADC and DAC/DAC_VNEG: C219.2, U202.5 (VNEG)
/Hardware ADC and DAC/INPUT_AC: C221.2, R208.1
/Hardware ADC and DAC/IN_BIAS: D202.3 (K1/A2), R208.2, R209.1, U203.3 (+)
/Hardware ADC and DAC/IN_BUF: R210.1, U203.1, U203.2 (-)
/Hardware ADC and DAC/SENSE_ADC_5V: C231.1, R215.2, R216.1, U206.5 (SENSE)
/Hardware ADC and DAC/SENSE_BUCK_5V: C232.1, R217.2, R218.1, U207.5 (SENSE)
/Hardware ADC and DAC/VMID: C223.1, R209.2, R211.2, R214.2

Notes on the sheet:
KESTREL REV B - HARDWARE-CONFIGURED ADC/DAC - ENGINEERING DRAFT
No audio I2C. Mono left channel. Protection and supervisor mute included; layout, rail hold-up and backend validation pending.
Clock target: synchronous 48 kHz LRCLK / 3.072 MHz BCLK / 12.288 MHz ADC MCLK. Current RTL must be migrated.
Input: approx 0.91 Mohm, bias 3.285 V at 9 V; 1:2 AC attenuation. Headroom/protection need tolerance review and bench tests.
ADC VREF is decoupling only. VINR AC grounded. DAC charge-pump/bypass returns must be short; use one common ground plane.
DAC low-latency filter; supervisor AUDIO_RUN defaults muted. Protection/hold-up validation, sourcing and thermal checks remain.
Source: TI PCM1808, PCM510xA, OPA1656, TLV767 and TLV755P datasheets. Do not fabricate this partial design.
D201/D203: bipolar ESD clamps
Place at jacks; short ground return
D202: low-leakage input steering
Backfeed/fault tests remain
DAC HOLD-UP / SUPERVISOR MUTE - ENGINEERING DRAFT
DAC AVDD/CPVDD/DVDD share held 3.3 V. ADC 5 V and buck 5 V monitored; either low asserts XSMT.
AUDIO_ENABLE must be driven HIGH only after FPGA clocks/data are stable. CT open: 20 ms release delay; default enable LOW.
C230/C235 Panasonic FK 2x1000 uF: verify inrush/pulse impedance/temp/age/load and >= 150/fs + 0.2 ms mute hold-up on hardware.

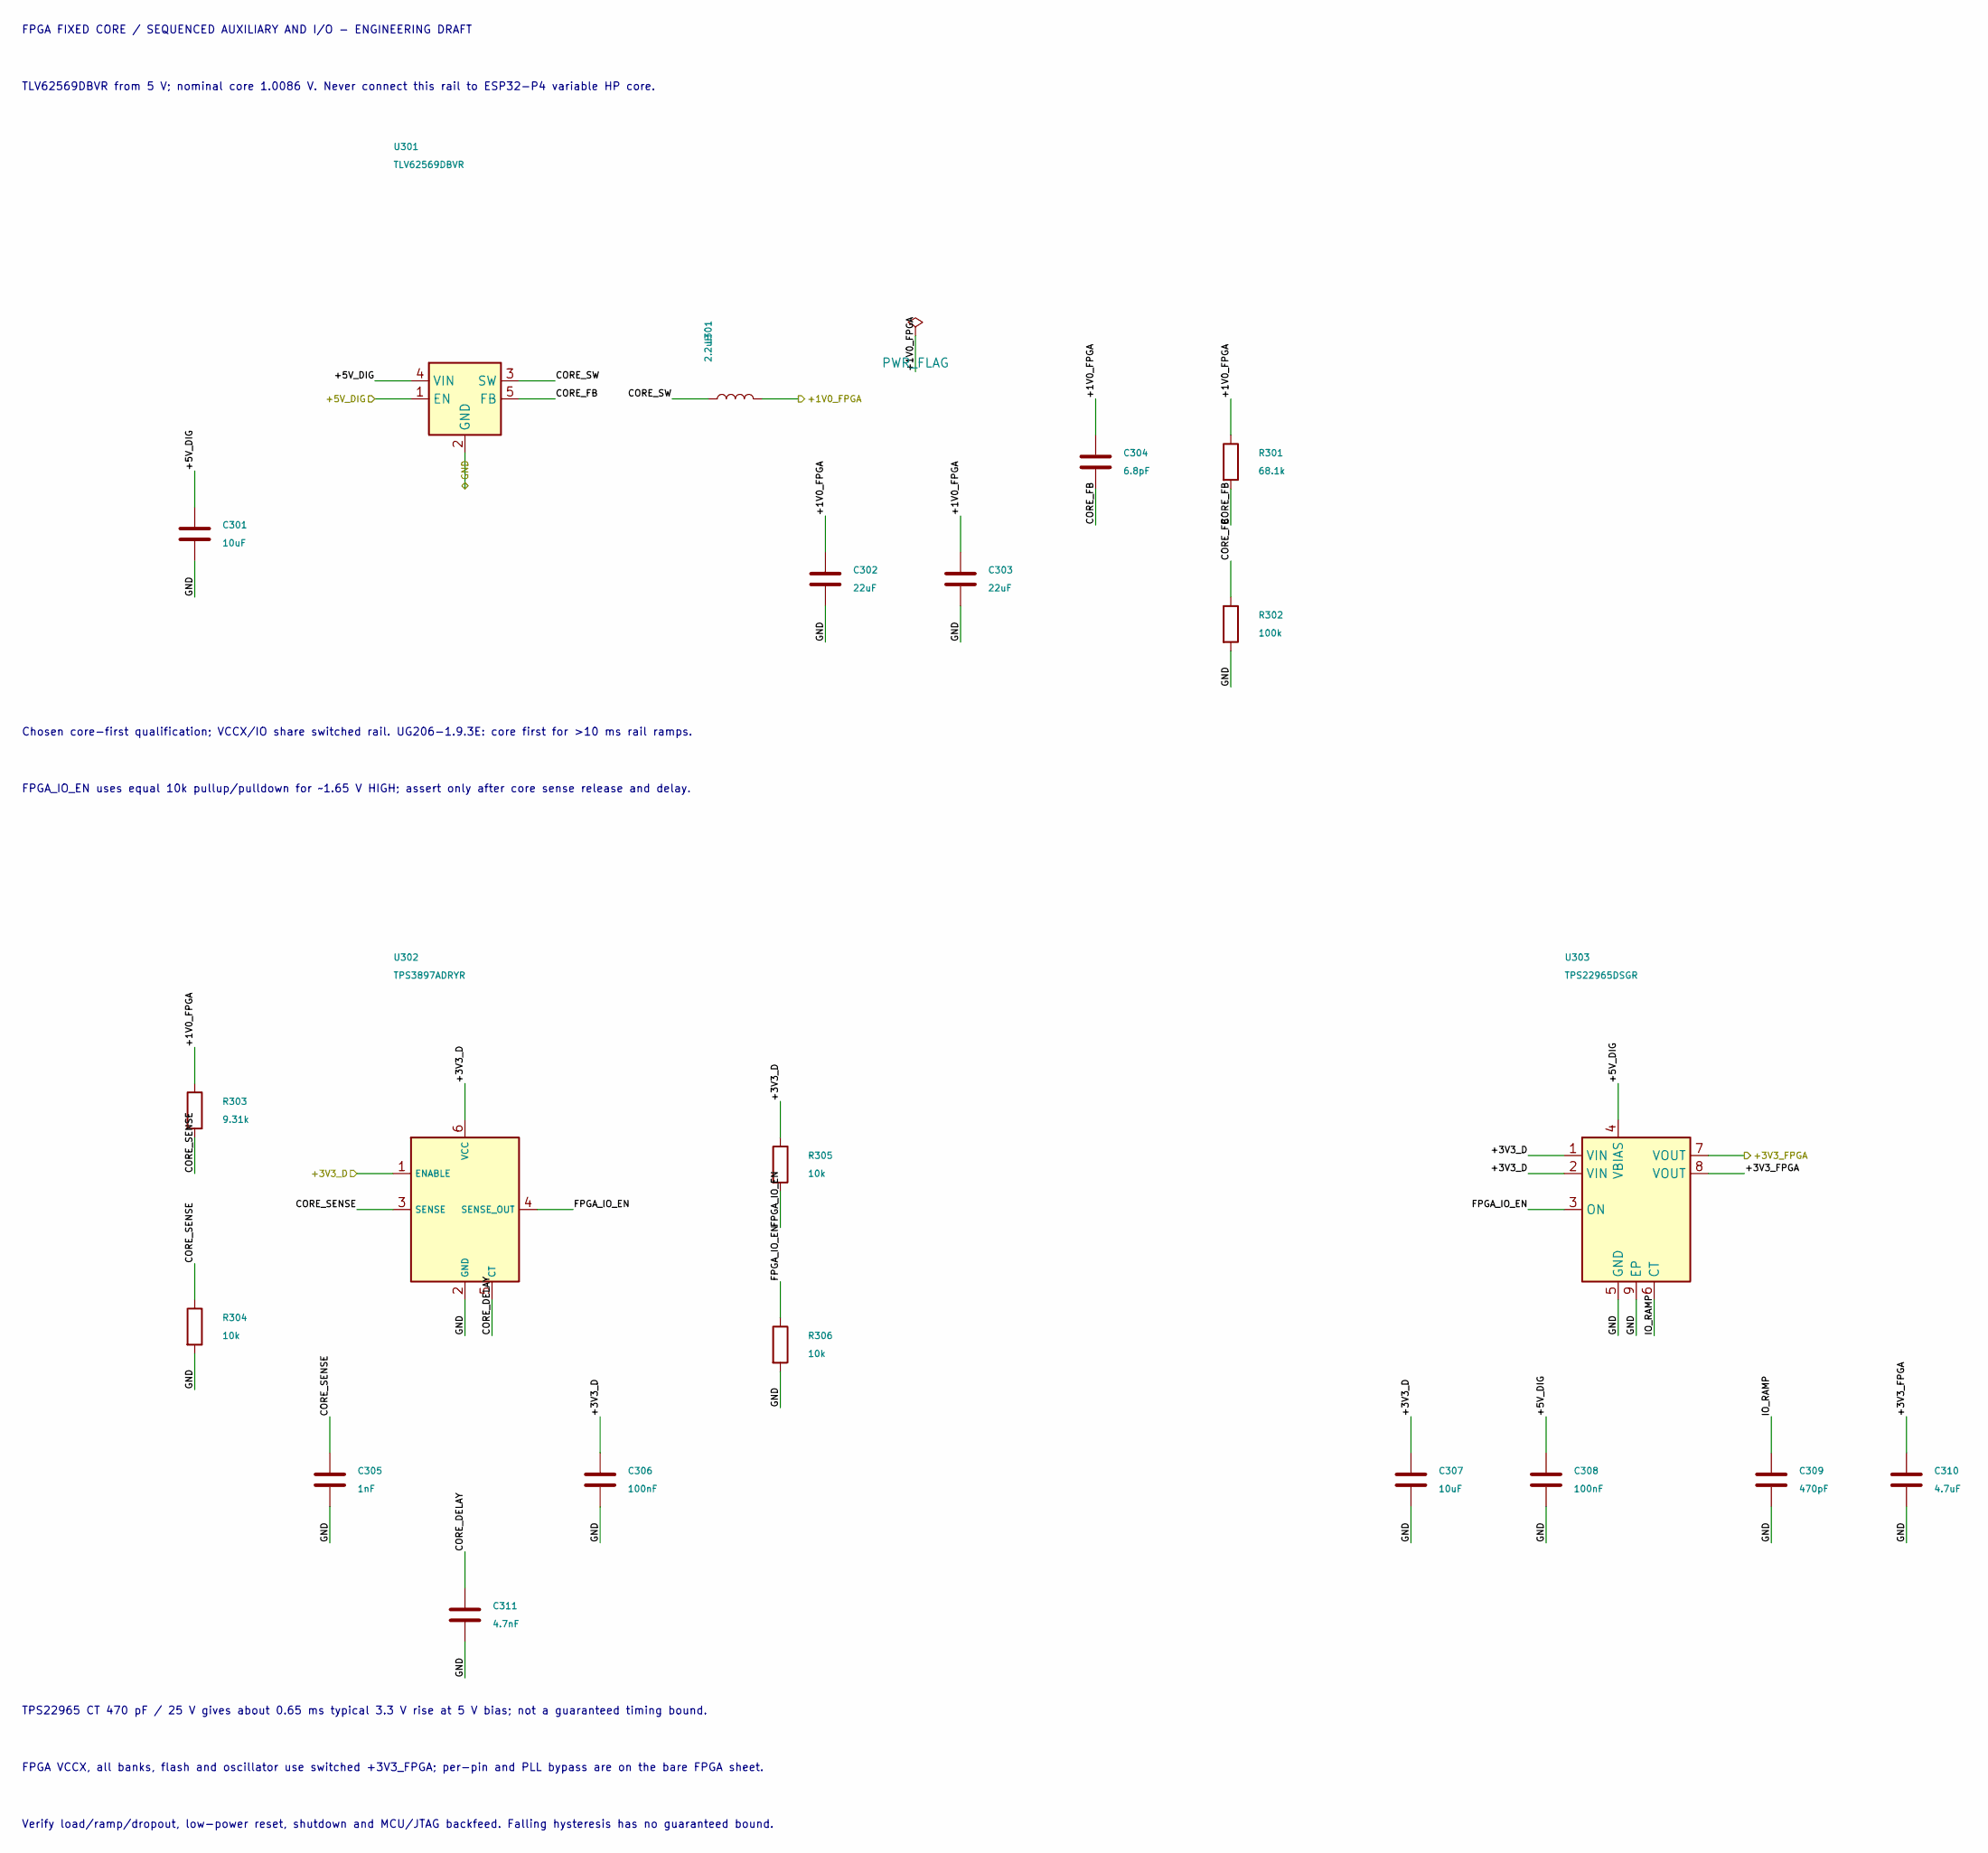
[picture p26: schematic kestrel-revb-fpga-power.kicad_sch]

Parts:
C301, C307: 10uF; C_1210_3225Metric; Rating 10uF / 16V X7R
C302, C303: 22uF; C_1210_3225Metric; Rating 22uF / 16V X7R
C304: 6.8pF; C_0603_1608Metric; Rating 6.8pF / C0G
C305: 1nF; C_0603_1608Metric; Rating 1nF / C0G
C306, C308: 100nF; C_0603_1608Metric; Rating 100nF / 16V
C309: 470pF; C_0603_1608Metric; Rating 470pF / 25V C0G
C310: 4.7uF; C_1210_3225Metric; Rating 4.7uF / 16V X7R
C311: 4.7nF; C_0603_1608Metric; Rating 4.7nF / 5% / 25V C0G
L301: 2.2uH; L_Sunlord_MWSA0402S; Rating 2.2uH / shielded / Isat >=3.5A; MPN MWSA0402S-2R2MT; LCSC C408335
R301: 68.1k; R_0603_1608Metric; Rating 68.1k / 0.1%
R302: 100k; R_0603_1608Metric; Rating 100k / 0.1%
R303: 9.31k; R_0603_1608Metric; Rating 9.31k / 0.1%
R304: 10k; R_0603_1608Metric; Rating 10k / 0.1%
R305, R306: 10k; R_0603_1608Metric; Rating 10k / 1%
U301: TLV62569DBVR; SOT-23-5
U302: TPS3897ADRYR; Texas_USON-6_1x1.45mm_P0.5mm_SMD
U303: TPS22965DSGR; TPS22965_DSG8_2x2

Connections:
/+1V0_FPGA: C302.1, C303.1, C304.1, L301.2, R301.1, R303.1; also elsewhere on the board
/+3V3_D: C306.1, C307.1, R305.1, U302.1 (ENABLE), U302.6 (VCC), U303.1 (VIN), U303.2 (VIN); also elsewhere on the board
/+3V3_FPGA: C310.1, U303.7 (VOUT), U303.8 (VOUT); also elsewhere on the board
/+5V_DIG: C301.1, C308.1, U301.1 (EN), U301.4 (VIN), U303.4 (VBIAS); also elsewhere on the board
/FPGA core and I/O sequencing/CORE_DELAY: C311.1, U302.5 (CT)
/FPGA core and I/O sequencing/CORE_FB: C304.2, R301.2, R302.1, U301.5 (FB)
/FPGA core and I/O sequencing/CORE_SENSE: C305.1, R303.2, R304.1, U302.3 (SENSE)
/FPGA core and I/O sequencing/CORE_SW: L301.1, U301.3 (SW)
/FPGA core and I/O sequencing/FPGA_IO_EN: R305.2, R306.1, U302.4 (SENSE_OUT), U303.3 (ON)
/FPGA core and I/O sequencing/IO_RAMP: C309.1, U303.6 (CT)
/GND: C301.2, C302.2, C303.2, C305.2, C306.2, C307.2, C308.2, C309.2, C310.2, C311.2, R302.2, R304.2, R306.2, U301.2 (GND), U302.2 (GND), U303.5 (GND), U303.9 (EP); also elsewhere on the board

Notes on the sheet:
FPGA FIXED CORE / SEQUENCED AUXILIARY AND I/O - ENGINEERING DRAFT
TLV62569DBVR from 5 V; nominal core 1.0086 V. Never connect this rail to ESP32-P4 variable HP core.
Chosen core-first qualification; VCCX/IO share switched rail. UG206-1.9.3E: core first for >10 ms rail ramps.
FPGA_IO_EN uses equal 10k pullup/pulldown for ~1.65 V HIGH; assert only after core sense release and delay.
TPS22965 CT 470 pF / 25 V gives about 0.65 ms typical 3.3 V rise at 5 V bias; not a guaranteed timing bound.
FPGA VCCX, all banks, flash and oscillator use switched +3V3_FPGA; per-pin and PLL bypass are on the bare FPGA sheet.
Verify load/ramp/dropout, low-power reset, shutdown and MCU/JTAG backfeed. Falling hysteresis has no guaranteed bound.

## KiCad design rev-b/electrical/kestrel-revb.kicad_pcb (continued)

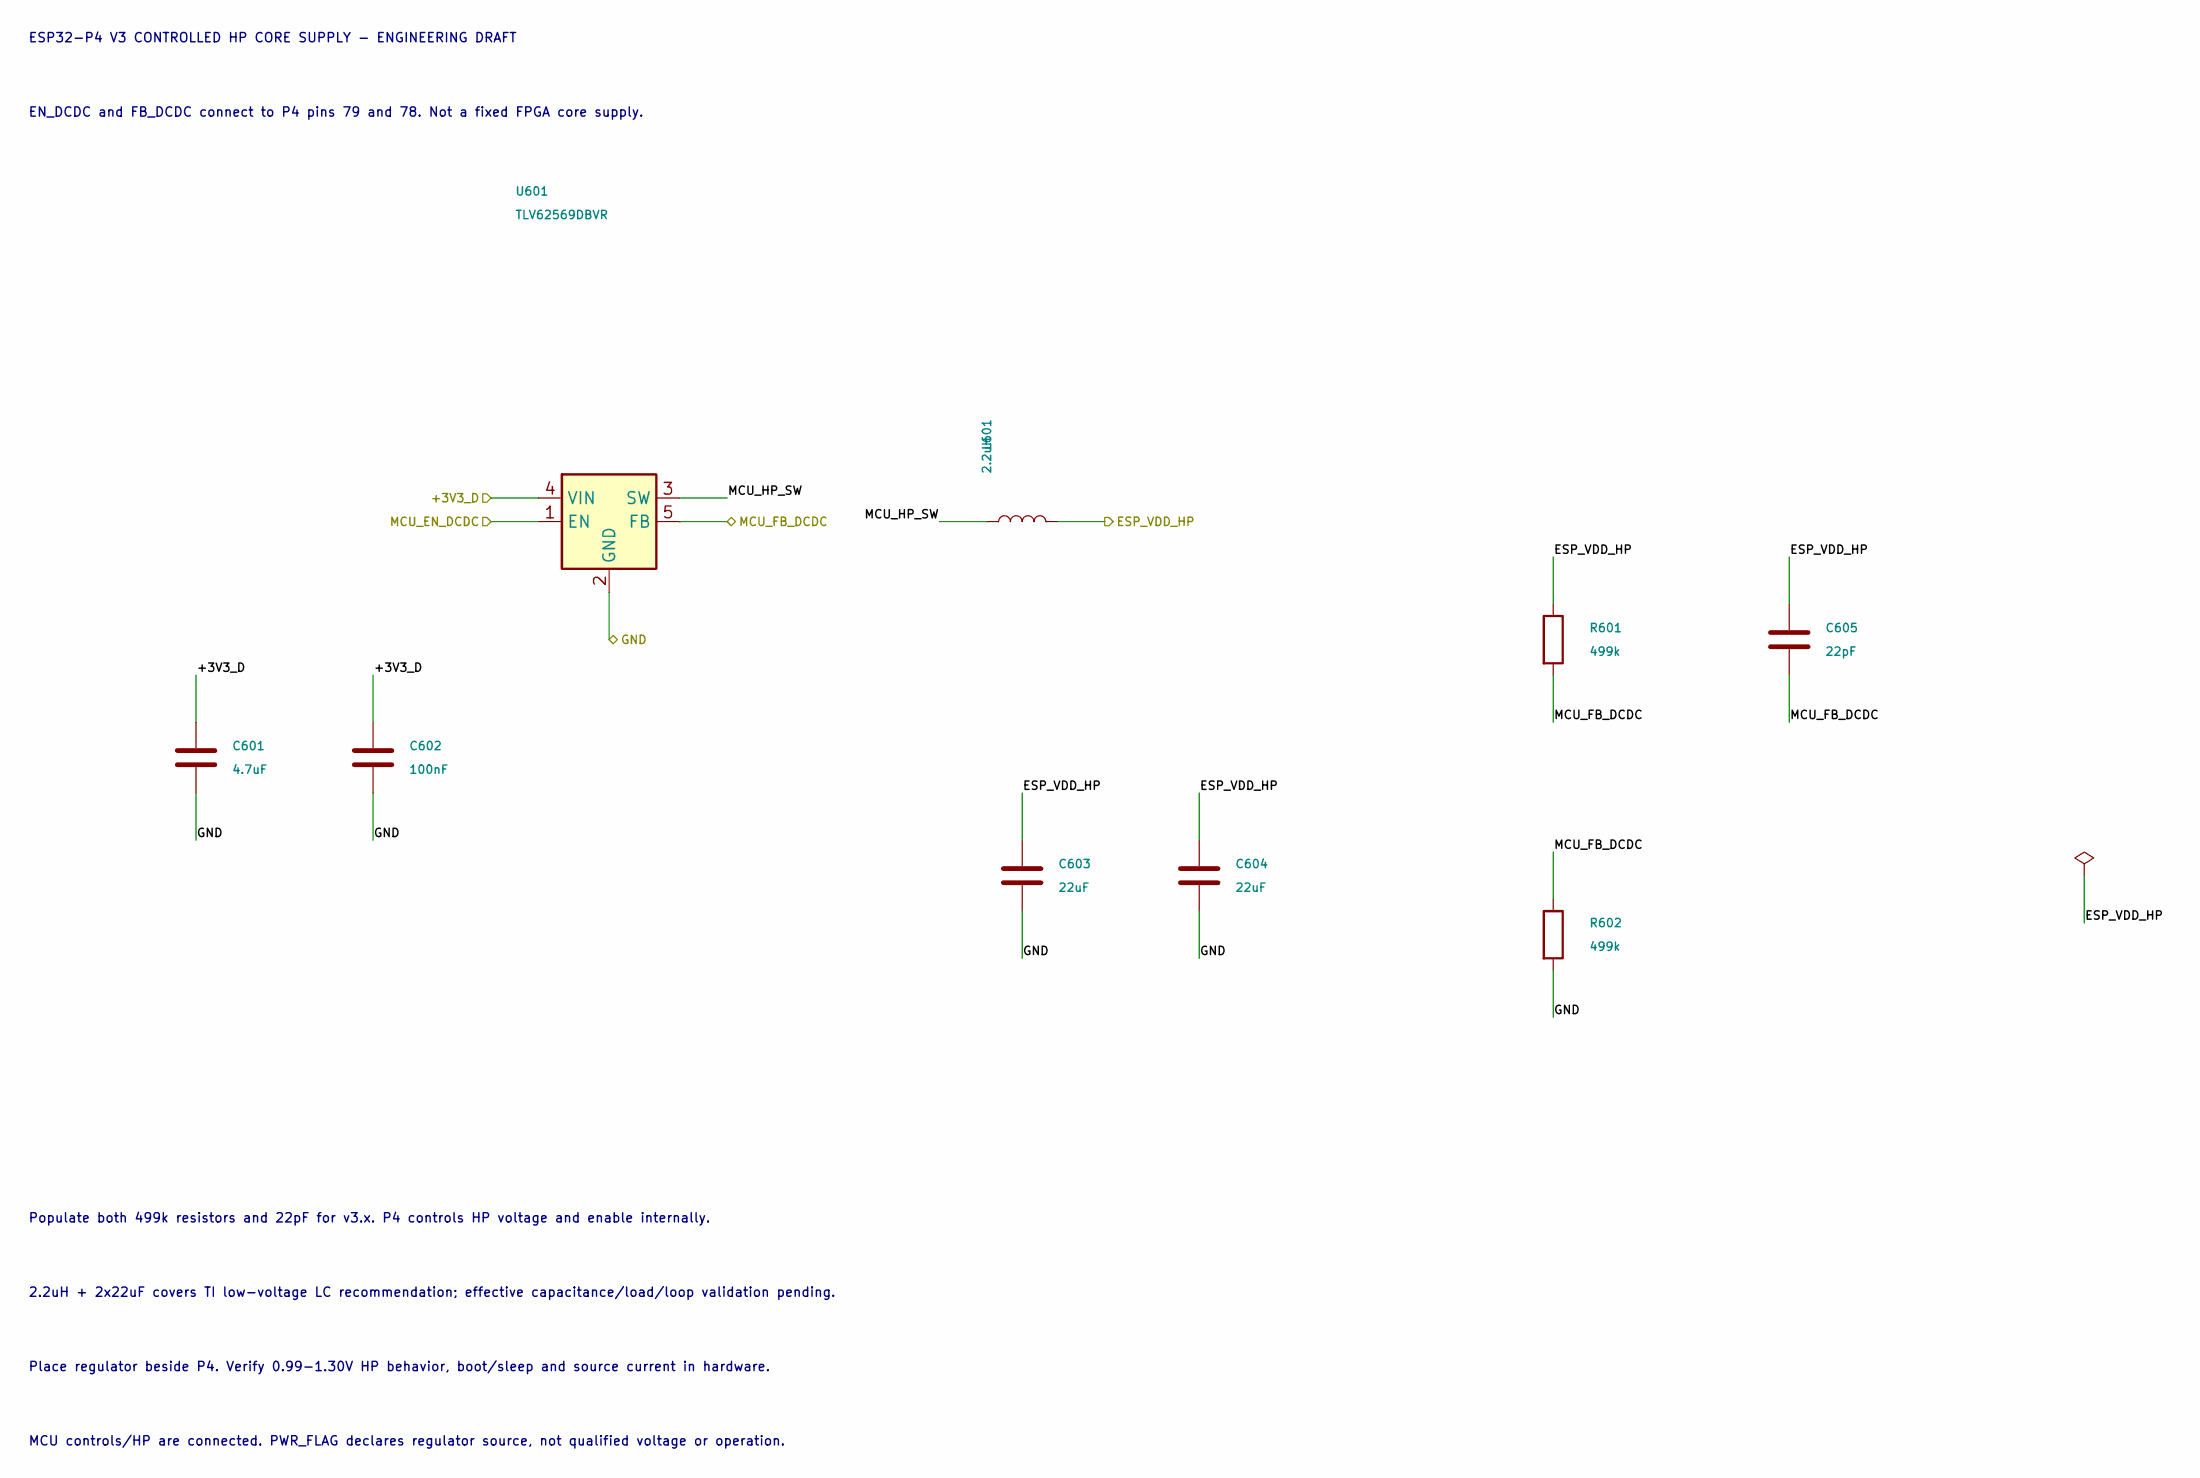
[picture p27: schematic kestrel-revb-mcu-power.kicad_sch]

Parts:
C601: 4.7uF; C_1210_3225Metric; Rating 4.7uF / 16V X7R
C602: 100nF; C_0603_1608Metric; Rating 100nF / 16V X7R
C603, C604: 22uF; C_1210_3225Metric; Rating 22uF / 16V X7R
C605: 22pF; C_0603_1608Metric; Rating 22pF / 25V C0G
L601: 2.2uH; L_Sunlord_MWSA0402S; Rating 2.2uH / shielded / Isat >=3.5A; MPN MWSA0402S-2R2MT; LCSC C408335
R601, R602: 499k; R_0603_1608Metric; Rating 499k / 1%
U601: TLV62569DBVR; SOT-23-5

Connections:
/+3V3_D: C601.1, C602.1, U601.4 (VIN); also elsewhere on the board
/ESP_VDD_HP: C603.1, C604.1, C605.1, L601.2, R601.1; also elsewhere on the board
/GND: C601.2, C602.2, C603.2, C604.2, R602.2, U601.2 (GND); also elsewhere on the board
/MCU_EN_DCDC: U601.1 (EN); also elsewhere on the board
/MCU_FB_DCDC: C605.2, R601.2, R602.1, U601.5 (FB); also elsewhere on the board
/P4 controlled HP regulator/MCU_HP_SW: L601.1, U601.3 (SW)

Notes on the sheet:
ESP32-P4 V3 CONTROLLED HP CORE SUPPLY - ENGINEERING DRAFT
EN_DCDC and FB_DCDC connect to P4 pins 79 and 78. Not a fixed FPGA core supply.
Populate both 499k resistors and 22pF for v3.x. P4 controls HP voltage and enable internally.
2.2uH + 2x22uF covers TI low-voltage LC recommendation; effective capacitance/load/loop validation pending.
Place regulator beside P4. Verify 0.99-1.30V HP behavior, boot/sleep and source current in hardware.
MCU controls/HP are connected. PWR_FLAG declares regulator source, not qualified voltage or operation.

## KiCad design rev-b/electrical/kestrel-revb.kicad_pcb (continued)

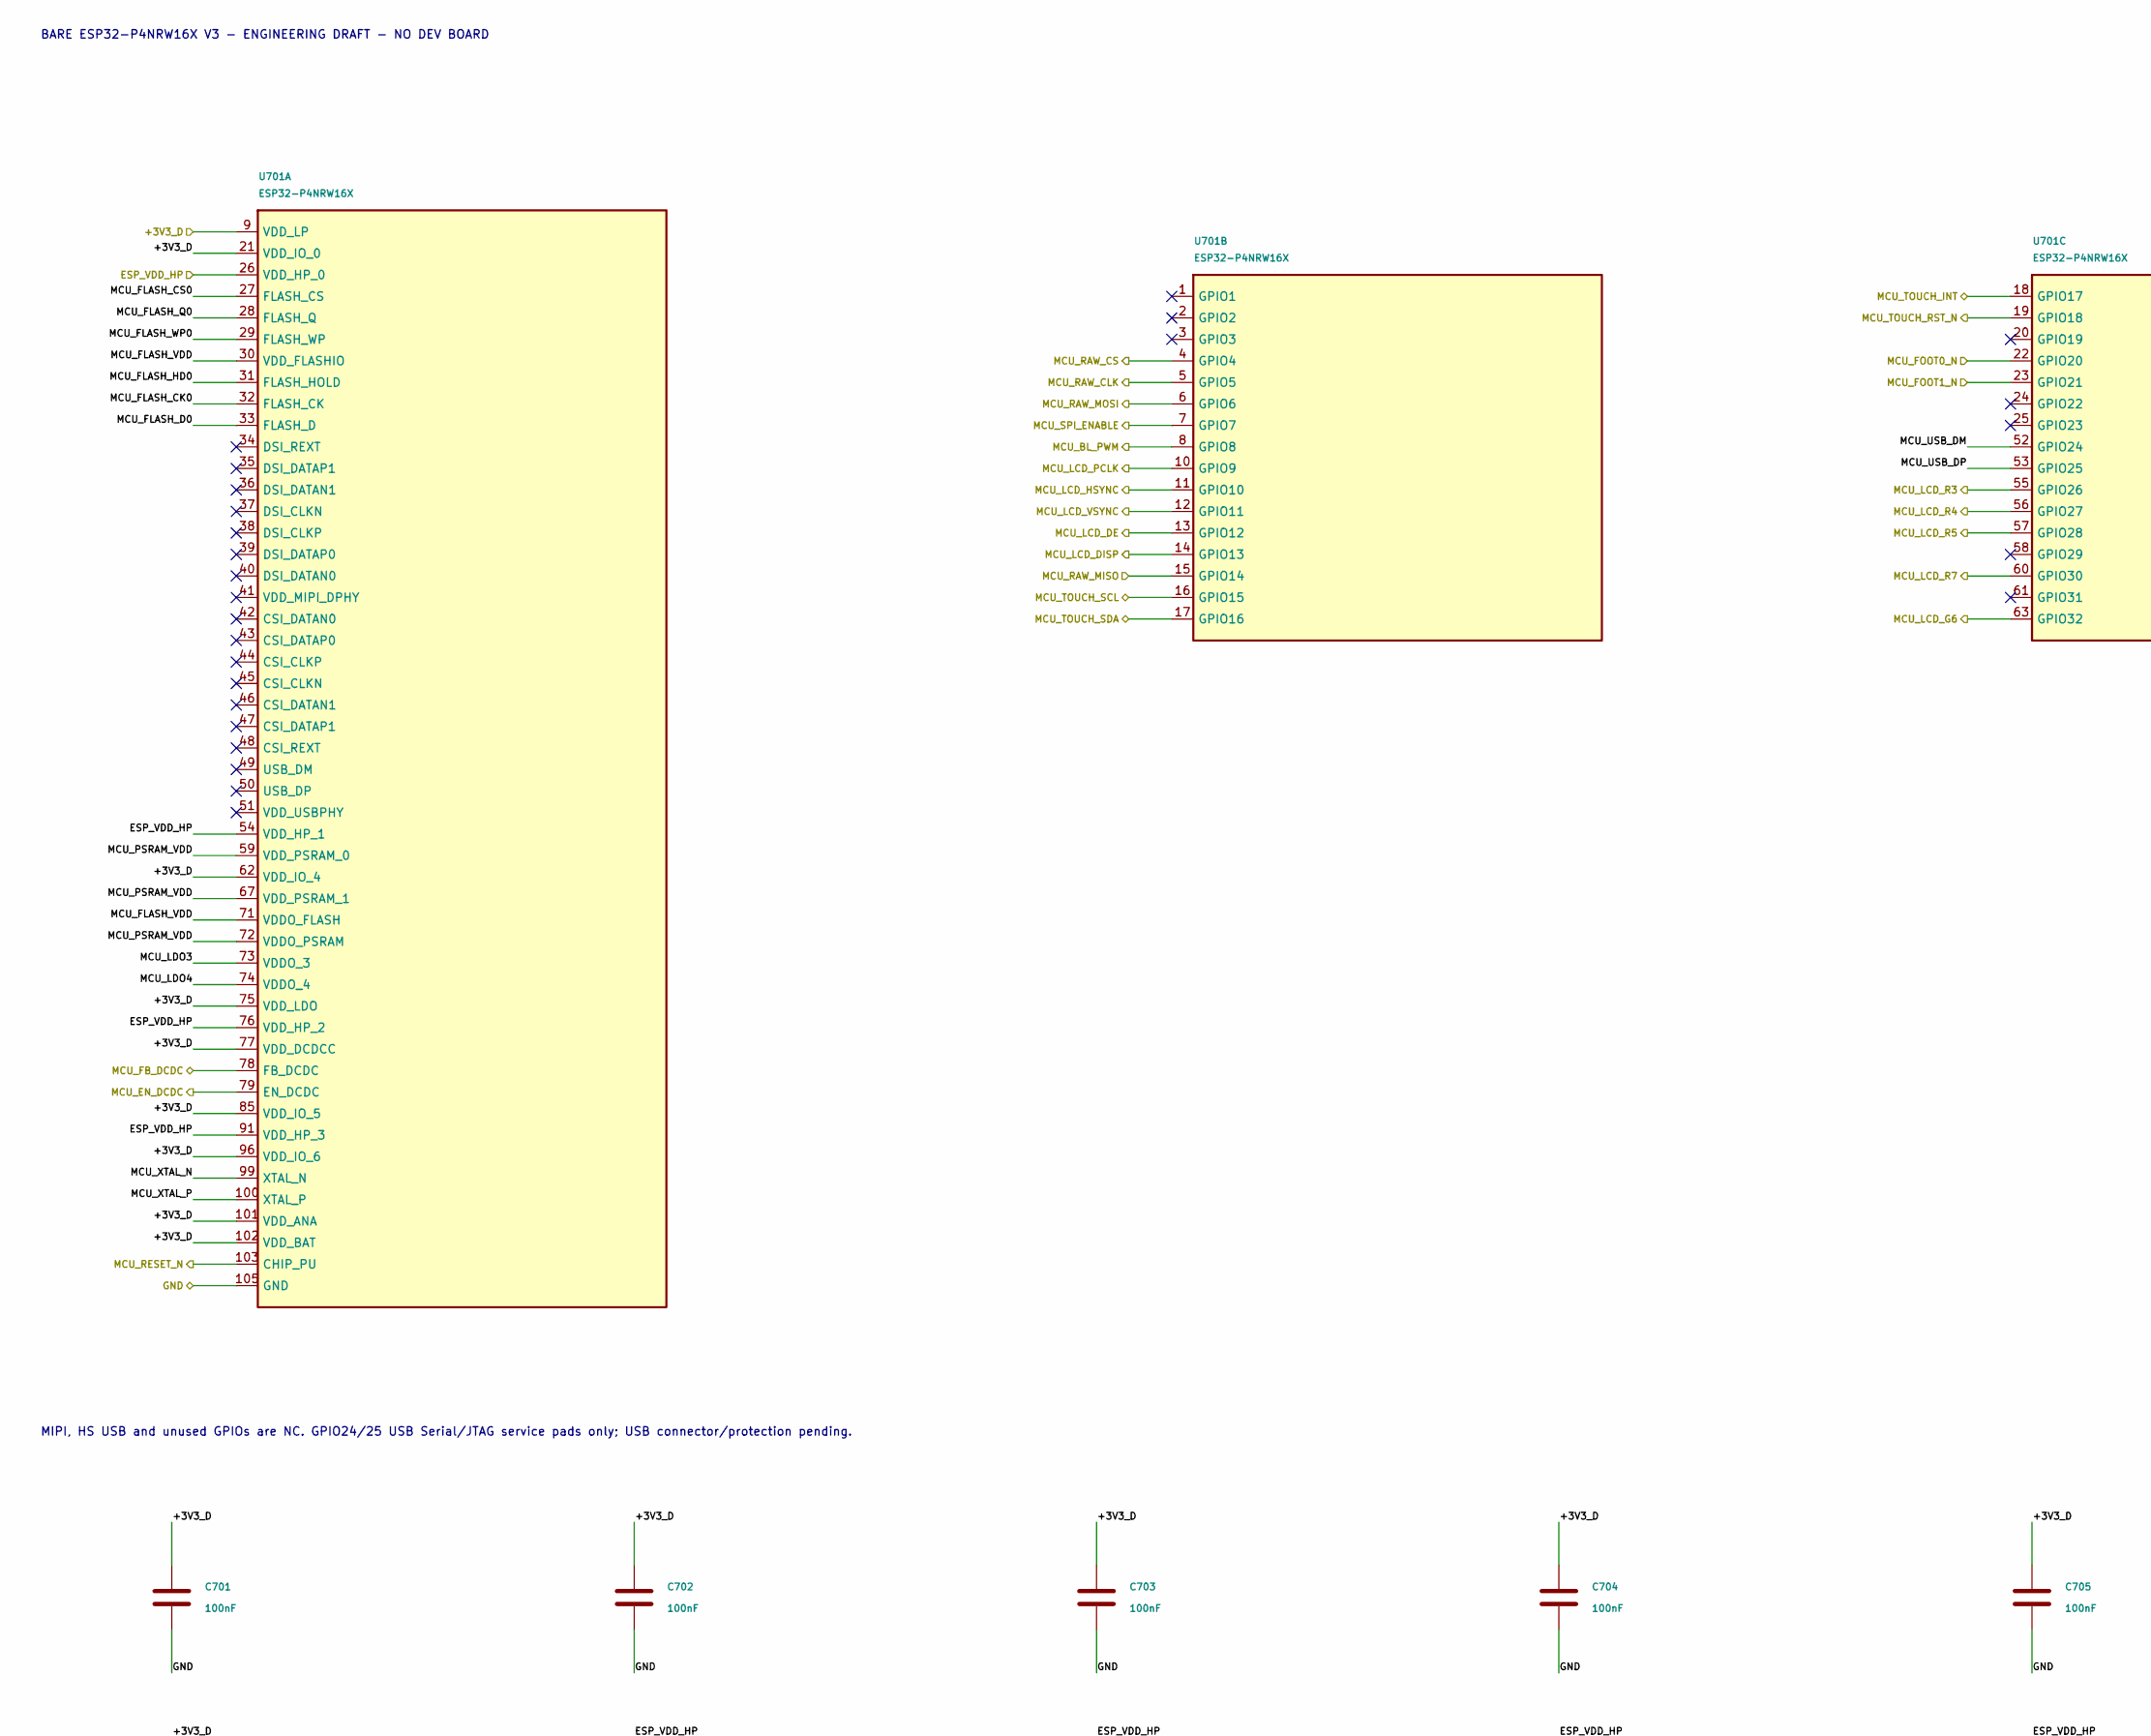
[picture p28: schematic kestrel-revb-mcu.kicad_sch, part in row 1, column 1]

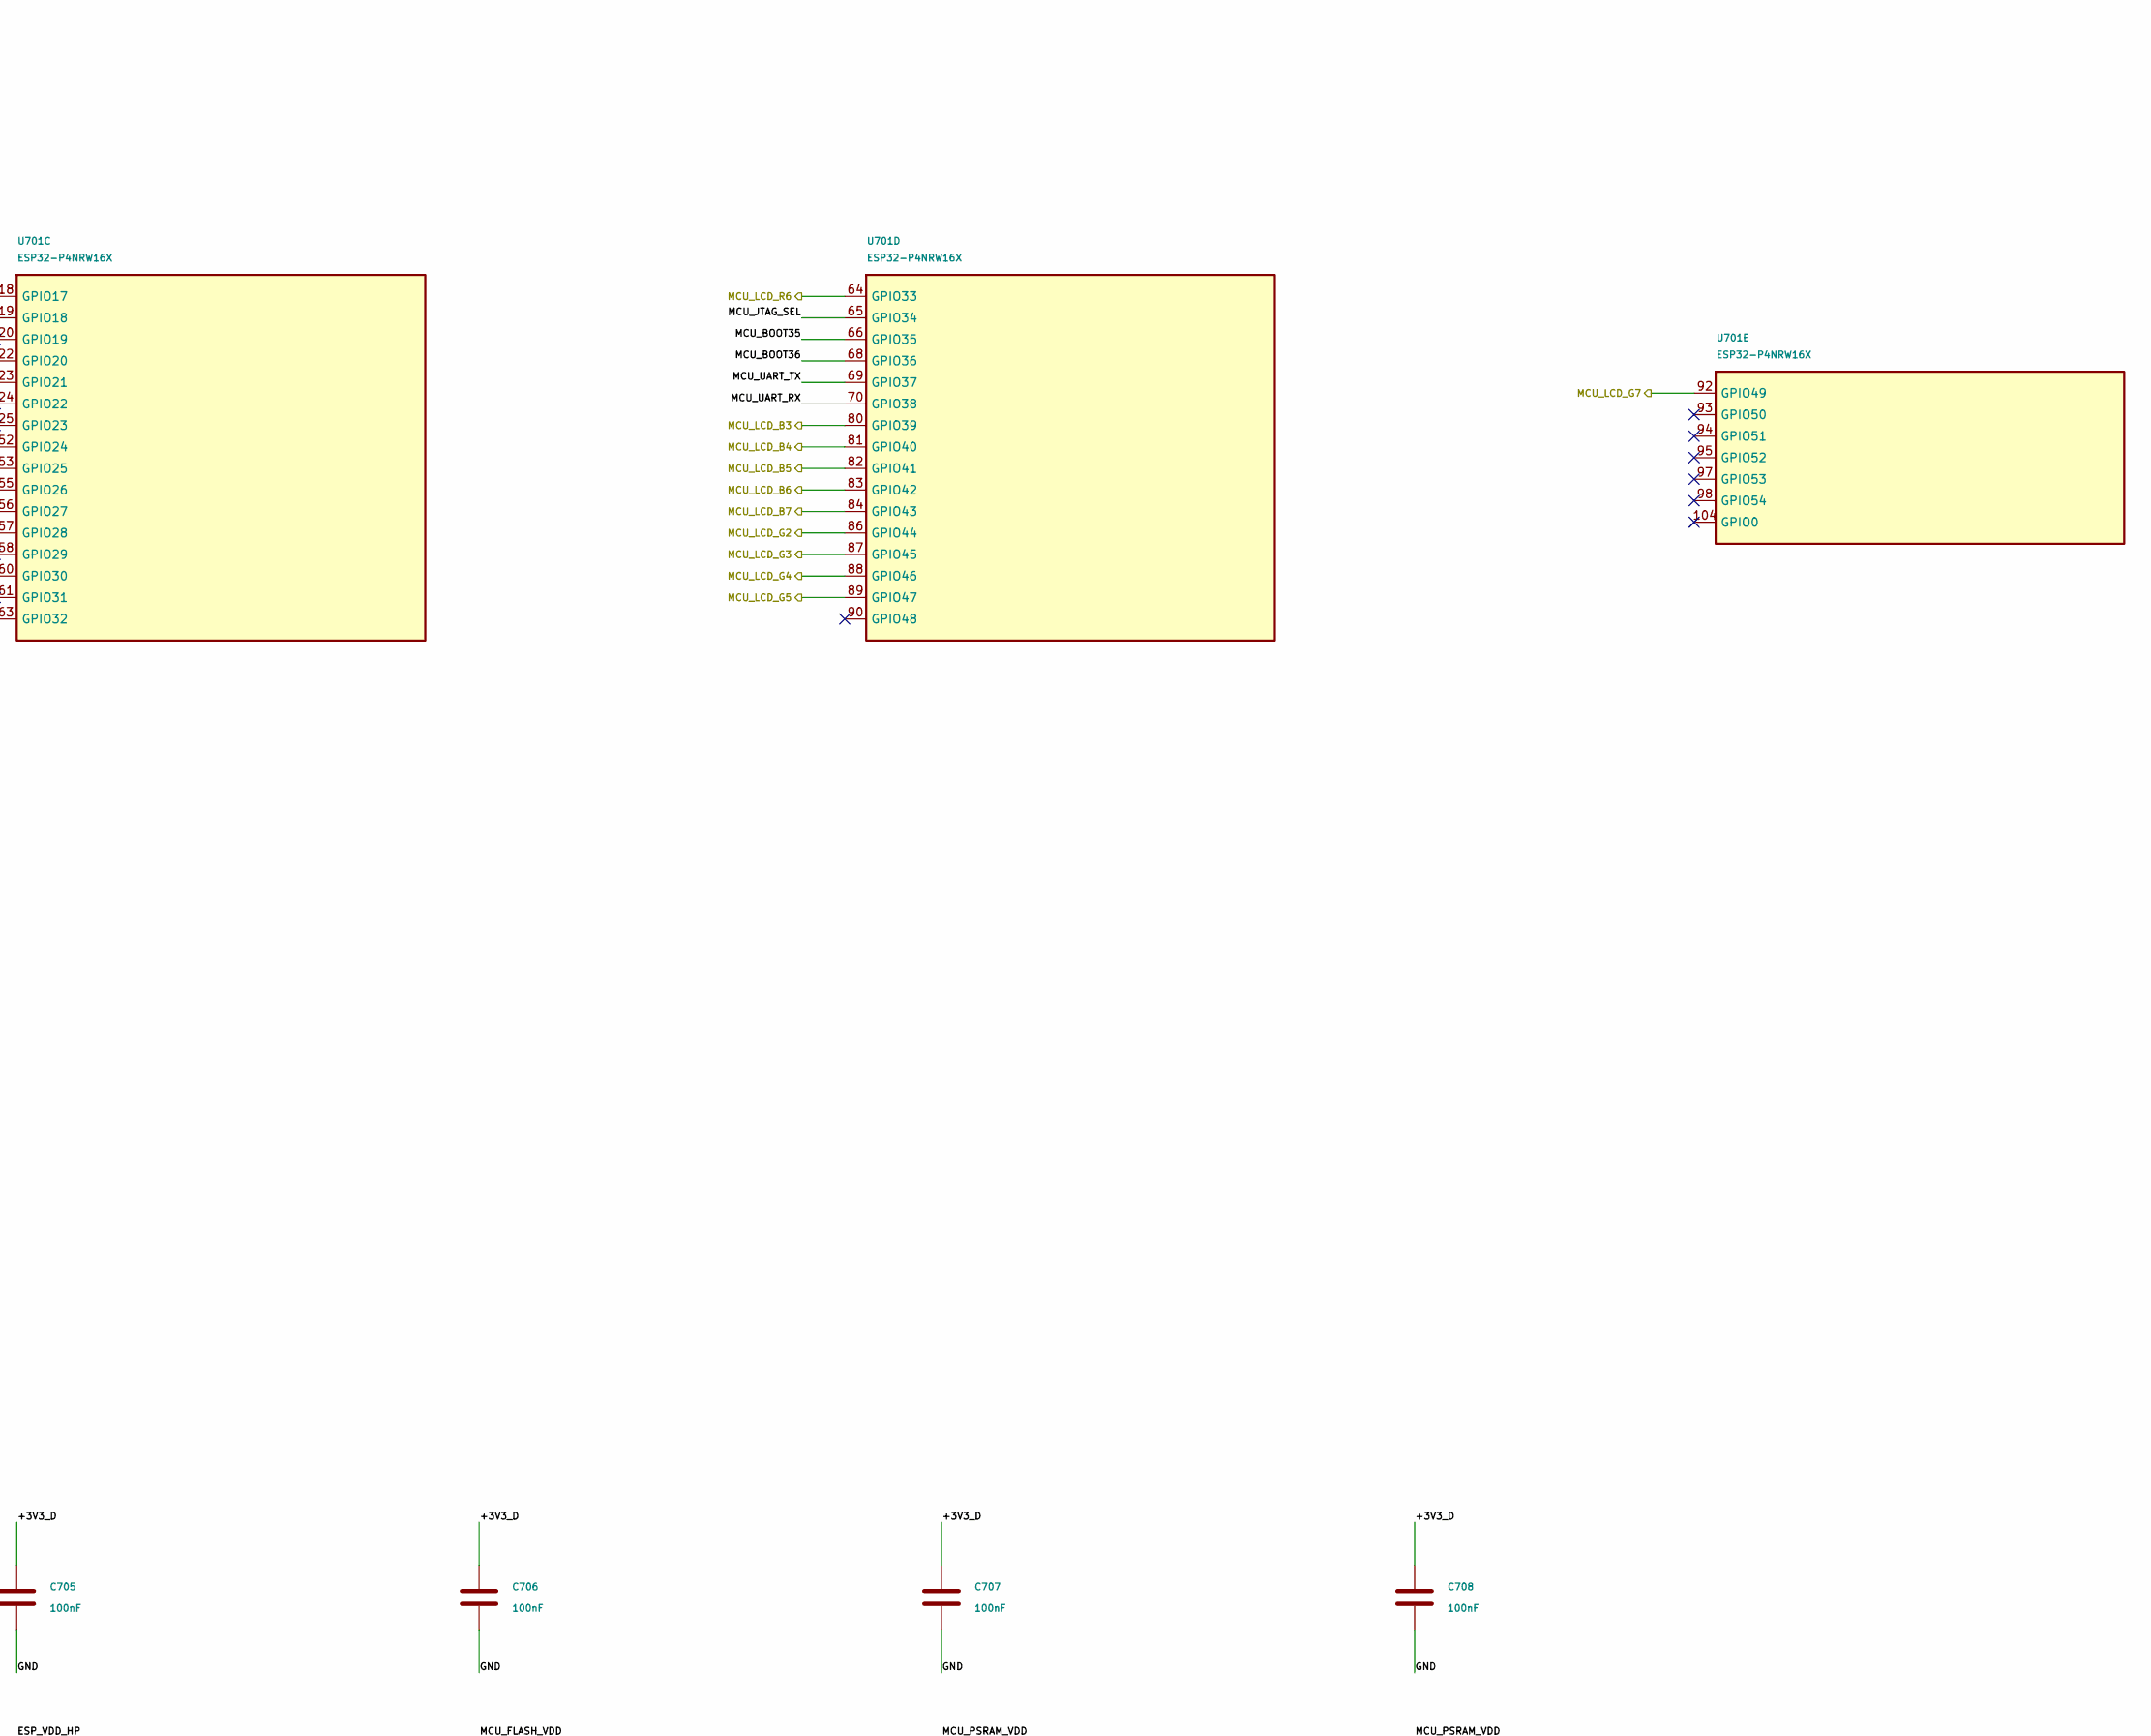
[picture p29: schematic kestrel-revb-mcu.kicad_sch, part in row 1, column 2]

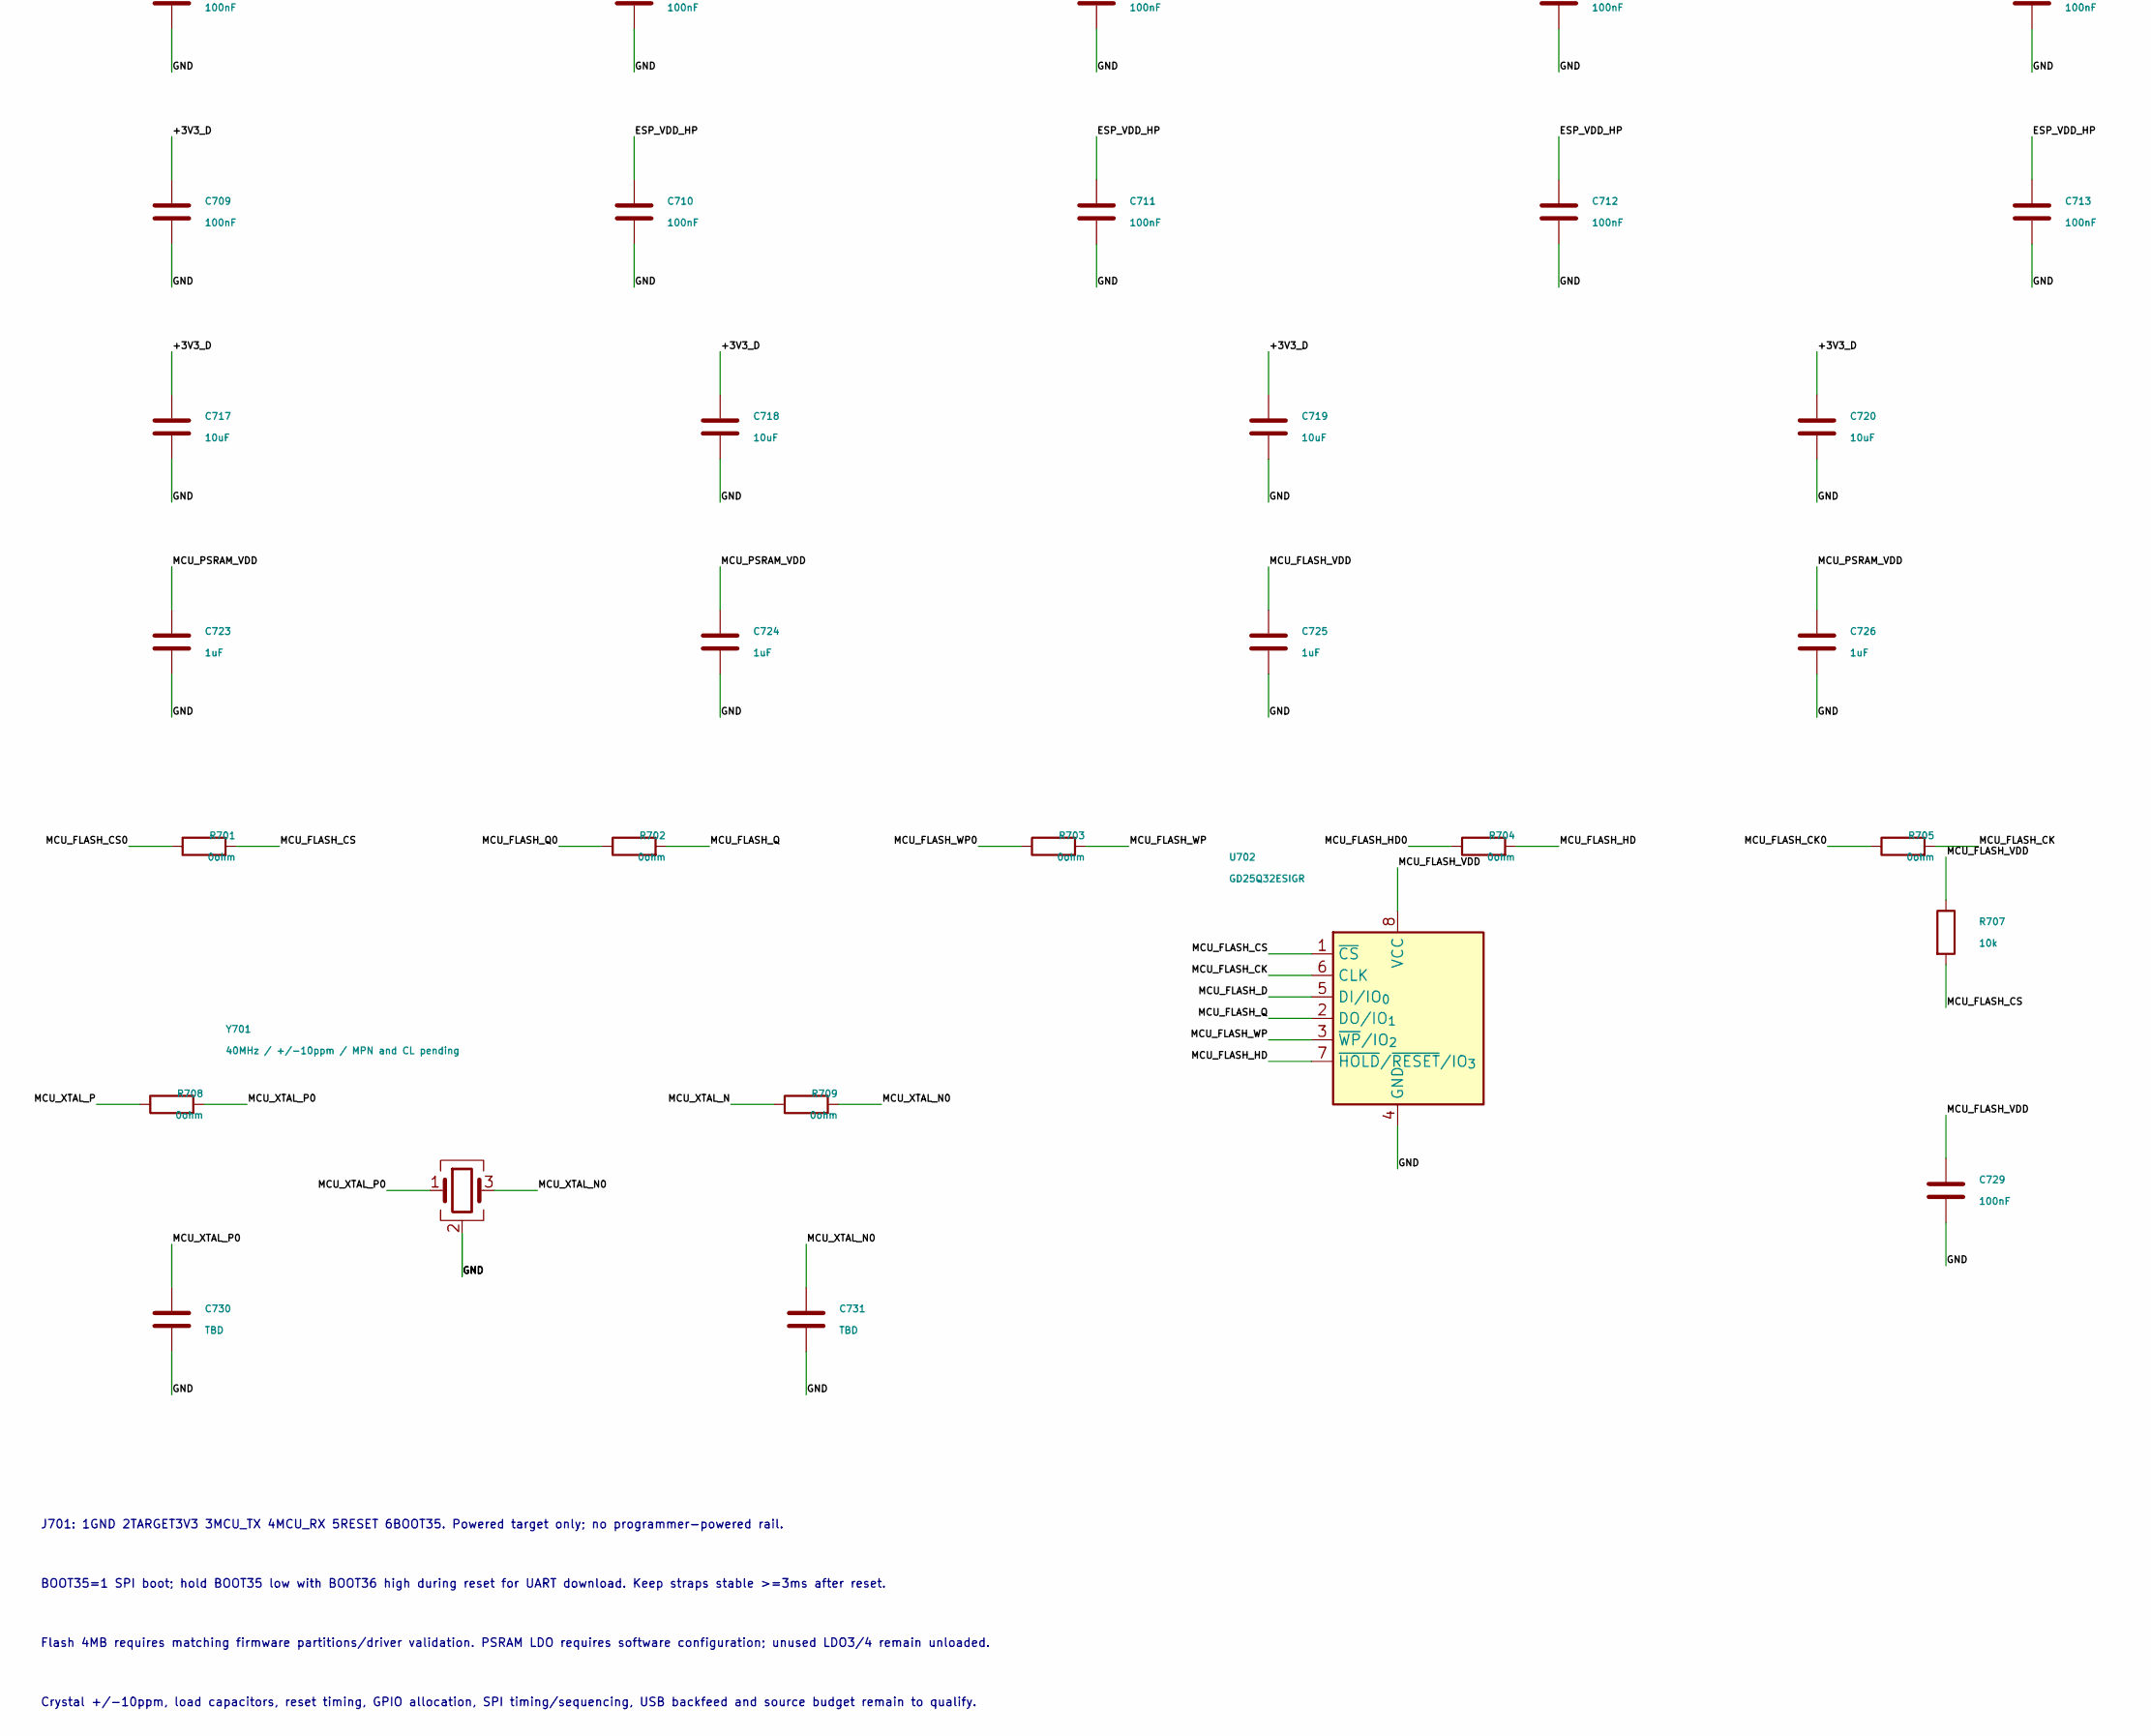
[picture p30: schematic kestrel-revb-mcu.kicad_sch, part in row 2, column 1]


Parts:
C701: 100nF; C_0402_1005Metric; Rating 100nF / 16V X7R +/-10% / at U701 pin 9; MPN CL05B104KO5NNNC; LCSC C1525
C702: 100nF; C_0402_1005Metric; Rating 100nF / 16V X7R +/-10% / at U701 pin 21; MPN CL05B104KO5NNNC; LCSC C1525
C703: 100nF; C_0402_1005Metric; Rating 100nF / 16V X7R +/-10% / at U701 pin 62; MPN CL05B104KO5NNNC; LCSC C1525
C704: 100nF; C_0402_1005Metric; Rating 100nF / 16V X7R +/-10% / at U701 pin 85; MPN CL05B104KO5NNNC; LCSC C1525
C705: 100nF; C_0402_1005Metric; Rating 100nF / 16V X7R +/-10% / at U701 pin 96; MPN CL05B104KO5NNNC; LCSC C1525
C706: 100nF; C_0402_1005Metric; Rating 100nF / 16V X7R +/-10% / at U701 pin 101; MPN CL05B104KO5NNNC; LCSC C1525
C707: 100nF; C_0402_1005Metric; Rating 100nF / 16V X7R +/-10% / at U701 pin 102; MPN CL05B104KO5NNNC; LCSC C1525
C708: 100nF; C_0402_1005Metric; Rating 100nF / 16V X7R +/-10% / at U701 pin 75; MPN CL05B104KO5NNNC; LCSC C1525
C709: 100nF; C_0402_1005Metric; Rating 100nF / 16V X7R +/-10% / at U701 pin 77; MPN CL05B104KO5NNNC; LCSC C1525
C710: 100nF; C_0402_1005Metric; Rating 100nF / 16V X7R +/-10% / at U701 pin 26; MPN CL05B104KO5NNNC; LCSC C1525
C711: 100nF; C_0402_1005Metric; Rating 100nF / 16V X7R +/-10% / at U701 pin 54; MPN CL05B104KO5NNNC; LCSC C1525
C712: 100nF; C_0402_1005Metric; Rating 100nF / 16V X7R +/-10% / at U701 pin 76; MPN CL05B104KO5NNNC; LCSC C1525
C713: 100nF; C_0402_1005Metric; Rating 100nF / 16V X7R +/-10% / at U701 pin 91; MPN CL05B104KO5NNNC; LCSC C1525
C714: 100nF; C_0402_1005Metric; Rating 100nF / 16V X7R +/-10% / at U701 pin 30; MPN CL05B104KO5NNNC; LCSC C1525
C715: 100nF; C_0402_1005Metric; Rating 100nF / 16V X7R +/-10% / at U701 pin 59; MPN CL05B104KO5NNNC; LCSC C1525
C716: 100nF; C_0402_1005Metric; Rating 100nF / 16V X7R +/-10% / at U701 pin 67; MPN CL05B104KO5NNNC; LCSC C1525
C717: 10uF; C_0805_2012Metric; Rating 10uF / 16V X7R
C718: 10uF; C_0805_2012Metric; Rating 10uF / 16V X7R / near VDD_BAT102
C719: 10uF; C_0805_2012Metric; Rating 10uF / 16V X7R / near VDD_LDO75
C720: 10uF; C_0805_2012Metric; Rating 10uF / 16V X7R / near VDD_DCDCC77
C721: 10uF; C_0805_2012Metric; Rating 10uF / 16V X7R / local HP bulk
C722: 1uF; C_0805_2012Metric; Rating 1uF / 16V X7R / at FLASHIO30
C723: 1uF; C_0805_2012Metric; Rating 1uF / 16V X7R / at PSRAM59
C724: 1uF; C_0805_2012Metric; Rating 1uF / 16V X7R / at PSRAM67
C725: 1uF; C_0805_2012Metric; Rating 1uF / 16V X7R / at VDDO_FLASH71
C726: 1uF; C_0805_2012Metric; Rating 1uF / 16V X7R / at VDDO_PSRAM72
C727: 1uF; C_0805_2012Metric; Rating 1uF / 16V X7R / at VDDO3_73
C728: 1uF; C_0805_2012Metric; Rating 1uF / 16V X7R / at VDDO4_74
C729: 100nF; C_0603_1608Metric; Rating 100nF / 16V X7R / at flash VCC
C730, C731: TBD; C_0603_1608Metric; Rating TBD / crystal CL and stray / C0G
C732: 1uF; C_0603_1608Metric; Rating 1uF / 16V X7R / reset RC starting point
J701: UART / POWERED TARGET ONLY; PinHeader_1x06_P2.54mm_Vertical
R701, R702, R703, R704, R705, R706: 0ohm; R_0603_1608Metric; Rating 0ohm / flash tuning footprint
R707: 10k; R_0603_1608Metric; Rating 10k / 1% / flash CS pullup
R708, R709: 0ohm; R_0402_1005Metric; Rating 0ohm / crystal tuning
R710, R711, R712, R713: 10k; R_0603_1608Metric; Rating 10k / 1%
SW701: RESET / SMD button MPN pending; SW_SPST_TL3342
SW702: BOOT / SMD button MPN pending; SW_SPST_TL3342
TP701: MCU_USB_DM; TestPoint_Pad_D1.0mm
TP702: MCU_USB_DP; TestPoint_Pad_D1.0mm
U701: ESP32-P4NRW16X; ESP32_P4_QFN104_10x10_P0.35_EP7.5
U702: GD25Q32ESIGR; SOIC-8_5.3x5.3mm_P1.27mm
Y701: 40MHz / +/-10ppm / MPN and CL pending; Crystal_SMD_3225-4Pin_3.2x2.5mm

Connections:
/+3V3_D: C701.1, C702.1, C703.1, C704.1, C705.1, C706.1, C707.1, C708.1, C709.1, C717.1, C718.1, C719.1, C720.1, J701.2, R710.1, R711.1, R712.1, R713.1, U701.9 (VDD_LP), U701.21 (VDD_IO_0), U701.62 (VDD_IO_4), U701.75 (VDD_LDO), U701.77 (VDD_DCDCC), U701.85 (VDD_IO_5), U701.96 (VDD_IO_6), U701.101 (VDD_ANA), U701.102 (VDD_BAT); also elsewhere on the board
/Bare ESP32-P4 support/MCU_BOOT35: J701.6, R711.2, SW702.1, U701.66 (GPIO35)
/Bare ESP32-P4 support/MCU_BOOT36: R712.2, U701.68 (GPIO36)
/Bare ESP32-P4 support/MCU_FLASH_CK: R705.2, U702.6 (CLK)
/Bare ESP32-P4 support/MCU_FLASH_CK0: R705.1, U701.32 (FLASH_CK)
/Bare ESP32-P4 support/MCU_FLASH_CS: R701.2, R707.2, U702.1 (~CS)
/Bare ESP32-P4 support/MCU_FLASH_CS0: R701.1, U701.27 (FLASH_CS)
/Bare ESP32-P4 support/MCU_FLASH_D: R706.2, U702.5 (DI/IO_{0})
/Bare ESP32-P4 support/MCU_FLASH_D0: R706.1, U701.33 (FLASH_D)
/Bare ESP32-P4 support/MCU_FLASH_HD: R704.2, U702.7 (~HOLD/~RESET/IO_{3})
/Bare ESP32-P4 support/MCU_FLASH_HD0: R704.1, U701.31 (FLASH_HOLD)
/Bare ESP32-P4 support/MCU_FLASH_Q: R702.2, U702.2 (DO/IO_{1})
/Bare ESP32-P4 support/MCU_FLASH_Q0: R702.1, U701.28 (FLASH_Q)
/Bare ESP32-P4 support/MCU_FLASH_VDD: C714.1, C722.1, C725.1, C729.1, R707.1, U701.30 (VDD_FLASHIO), U701.71 (VDDO_FLASH), U702.8 (VCC)
/Bare ESP32-P4 support/MCU_FLASH_WP: R703.2, U702.3 (~WP/IO_{2})
/Bare ESP32-P4 support/MCU_FLASH_WP0: R703.1, U701.29 (FLASH_WP)
/Bare ESP32-P4 support/MCU_JTAG_SEL: R713.2, U701.65 (GPIO34)
/Bare ESP32-P4 support/MCU_LDO3: C727.1, U701.73 (VDDO_3)
/Bare ESP32-P4 support/MCU_LDO4: C728.1, U701.74 (VDDO_4)
/Bare ESP32-P4 support/MCU_PSRAM_VDD: C715.1, C716.1, C723.1, C724.1, C726.1, U701.59 (VDD_PSRAM_0), U701.67 (VDD_PSRAM_1), U701.72 (VDDO_PSRAM)
/Bare ESP32-P4 support/MCU_UART_RX: J701.4, U701.70 (GPIO38)
/Bare ESP32-P4 support/MCU_UART_TX: J701.3, U701.69 (GPIO37)
/Bare ESP32-P4 support/MCU_USB_DM: TP701.1, U701.52 (GPIO24)
/Bare ESP32-P4 support/MCU_USB_DP: TP702.1, U701.53 (GPIO25)
/Bare ESP32-P4 support/MCU_XTAL_N: R709.1, U701.99 (XTAL_N)
/Bare ESP32-P4 support/MCU_XTAL_N0: C731.1, R709.2, Y701.3
/Bare ESP32-P4 support/MCU_XTAL_P: R708.1, U701.100 (XTAL_P)
/Bare ESP32-P4 support/MCU_XTAL_P0: C730.1, R708.2, Y701.1
/ESP_VDD_HP: C710.1, C711.1, C712.1, C713.1, C721.1, U701.26 (VDD_HP_0), U701.54 (VDD_HP_1), U701.76 (VDD_HP_2), U701.91 (VDD_HP_3); also elsewhere on the board
/GND: C701.2, C702.2, C703.2, C704.2, C705.2, C706.2, C707.2, C708.2, C709.2, C710.2, C711.2, C712.2, C713.2, C714.2, C715.2, C716.2, C717.2, C718.2, C719.2, C720.2, C721.2, C722.2, C723.2, C724.2, C725.2, C726.2, C727.2, C728.2, C729.2, C730.2, C731.2, C732.2, J701.1, SW701.2, SW702.2, U701.105 (GND), U702.4 (GND), Y701.2 (G), Y701.4 (G); also elsewhere on the board
/MCU_BL_PWM: U701.8 (GPIO8); also elsewhere on the board
/MCU_EN_DCDC: U701.79 (EN_DCDC); also elsewhere on the board
/MCU_FB_DCDC: U701.78 (FB_DCDC); also elsewhere on the board
/MCU_FOOT0_N: U701.22 (GPIO20); also elsewhere on the board
/MCU_FOOT1_N: U701.23 (GPIO21); also elsewhere on the board
/MCU_LCD_B3: U701.80 (GPIO39); also elsewhere on the board
/MCU_LCD_B4: U701.81 (GPIO40); also elsewhere on the board
/MCU_LCD_B5: U701.82 (GPIO41); also elsewhere on the board
/MCU_LCD_B6: U701.83 (GPIO42); also elsewhere on the board
/MCU_LCD_B7: U701.84 (GPIO43); also elsewhere on the board
/MCU_LCD_DE: U701.13 (GPIO12); also elsewhere on the board
/MCU_LCD_DISP: U701.14 (GPIO13); also elsewhere on the board
/MCU_LCD_G2: U701.86 (GPIO44); also elsewhere on the board
/MCU_LCD_G3: U701.87 (GPIO45); also elsewhere on the board
/MCU_LCD_G4: U701.88 (GPIO46); also elsewhere on the board
/MCU_LCD_G5: U701.89 (GPIO47); also elsewhere on the board
/MCU_LCD_G6: U701.63 (GPIO32); also elsewhere on the board
/MCU_LCD_G7: U701.92 (GPIO49); also elsewhere on the board
/MCU_LCD_HSYNC: U701.11 (GPIO10); also elsewhere on the board
/MCU_LCD_PCLK: U701.10 (GPIO9); also elsewhere on the board
/MCU_LCD_R3: U701.55 (GPIO26); also elsewhere on the board
/MCU_LCD_R4: U701.56 (GPIO27); also elsewhere on the board
/MCU_LCD_R5: U701.57 (GPIO28); also elsewhere on the board
/MCU_LCD_R6: U701.64 (GPIO33); also elsewhere on the board
/MCU_LCD_R7: U701.60 (GPIO30); also elsewhere on the board
/MCU_LCD_VSYNC: U701.12 (GPIO11); also elsewhere on the board
/MCU_RAW_CLK: U701.5 (GPIO5); also elsewhere on the board
/MCU_RAW_CS: U701.4 (GPIO4); also elsewhere on the board
/MCU_RAW_MISO: U701.15 (GPIO14); also elsewhere on the board
/MCU_RAW_MOSI: U701.6 (GPIO6); also elsewhere on the board
/MCU_RESET_N: C732.1, J701.5, R710.2, SW701.1, U701.103 (CHIP_PU); also elsewhere on the board
/MCU_SPI_ENABLE: U701.7 (GPIO7); also elsewhere on the board
/MCU_TOUCH_INT: U701.18 (GPIO17); also elsewhere on the board
/MCU_TOUCH_RST_N: U701.19 (GPIO18); also elsewhere on the board
/MCU_TOUCH_SCL: U701.16 (GPIO15); also elsewhere on the board
/MCU_TOUCH_SDA: U701.17 (GPIO16); also elsewhere on the board

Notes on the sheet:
BARE ESP32-P4NRW16X V3 - ENGINEERING DRAFT - NO DEV BOARD
MIPI, HS USB and unused GPIOs are NC. GPIO24/25 USB Serial/JTAG service pads only; USB connector/protection pending.
J701: 1GND 2TARGET3V3 3MCU_TX 4MCU_RX 5RESET 6BOOT35. Powered target only; no programmer-powered rail.
BOOT35=1 SPI boot; hold BOOT35 low with BOOT36 high during reset for UART download. Keep straps stable >=3ms after reset.
Flash 4MB requires matching firmware partitions/driver validation. PSRAM LDO requires software configuration; unused LDO3/4 remain unloaded.
Crystal +/-10ppm, load capacitors, reset timing, GPIO allocation, SPI timing/sequencing, USB backfeed and source budget remain to qualify.

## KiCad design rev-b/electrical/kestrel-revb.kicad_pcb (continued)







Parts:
C501: 100nF; C_0603_1608Metric; Rating 100nF / 16V X7R / at U501 pin 1
C502: 100nF; C_0603_1608Metric; Rating 100nF / 16V X7R / at U501 pin 3
C503: 100nF; C_0603_1608Metric; Rating 100nF / 16V X7R / at U501 pin 12
C504: 100nF; C_0603_1608Metric; Rating 100nF / 16V X7R / at U501 pin 14
C505: 100nF; C_0603_1608Metric; Rating 100nF / 16V X7R / at U501 pin 22
C506: 100nF; C_0603_1608Metric; Rating 100nF / 16V X7R / at U501 pin 23
C507: 100nF; C_0603_1608Metric; Rating 100nF / 16V X7R / at U501 pin 44
C508: 100nF; C_0603_1608Metric; Rating 100nF / 16V X7R / at U501 pin 45
C509: 100nF; C_0603_1608Metric; Rating 100nF / 16V X7R / at U501 pin 50
C510: 100nF; C_0603_1608Metric; Rating 100nF / 16V X7R / at U501 pin 58
C511: 100nF; C_0603_1608Metric; Rating 100nF / 16V X7R / at U501 pin 64
C512: 100nF; C_0603_1608Metric; Rating 100nF / 16V X7R / at U501 pin 66
C513: 100nF; C_0603_1608Metric; Rating 100nF / 16V X7R / at U501 pin 67
C514: 100nF; C_0603_1608Metric; Rating 100nF / 16V X7R / at U501 pin 78
C515, C518: 4.7uF; C_0603_1608Metric; Rating 4.7uF / 16V X7R
C516, C519, C523, C524, C526, C527: 100nF; C_0603_1608Metric; Rating 100nF / 16V X7R
C517, C520: 10nF; C_0603_1608Metric; Rating 10nF / 16V X7R
C521: 4.7uF; C_0603_1608Metric; Rating 4.7uF / 16V X7R / local core bulk
C522: 4.7uF; C_0603_1608Metric; Rating 4.7uF / 16V X7R / local IO bulk
C525: 100nF; C_0603_1608Metric; Rating 100nF / 16V X7R / JTAG VREF
J501: GOWIN JTAG / target VREF only; PinHeader_2x05_P2.54mm_Vertical
L501, L502: 220ohm@100MHz; L_0603_1608Metric; Rating 220ohm@100MHz / DCR <=0.1ohm / MPN pend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
R501, R510, R511, R517: 10k; R_0603_1608Metric; Rating 10k / 1%
R502, R503, R504: 1k; R_0603_1608Metric; Rating 1k / 1%
R505, R506, R507, R508, R509: 4.7k; R_0603_1608Metric; Rating 4.7k / 1%
R512, R513, R514, R515, R516, R519: 33ohm; R_0603_1608Metric; Rating 33ohm / 1%
R518: 100k; R_0603_1608Metric; Rating 100k / 1%
SW501: RECONFIG / MPN pending; SW_SPST_TL3342
U501: GW2AR-LV18QN88C8/I7; GW2AR_QN88_10x10_P0.4_EP6.8
U502: GD25Q32ESIGR; SOIC-8_5.3x5.3mm_P1.27mm
U503: SN74LVC1G125DCKR; SOT-353_SC-70-5
U504: SN74LVC1G17DCKR; SOT-353_SC-70-5
Y501: 24.576MHz / 3.3V CMOS XO / MPN pending; Oscillator_SMD_Abracon_ASE-4Pin_3.2x2.5mm

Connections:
/+1V0_FPGA: C501.1, C505.1, C508.1, C512.1, C521.1, L501.1, L502.1, U501.1 (VCC), U501.22 (VCC), U501.45 (VCC), U501.66 (VCC); also elsewhere on the board
/+3V3_A: C527.1, U504.5 (VCC); also elsewhere on the board
/+3V3_FPGA: C502.1, C503.1, C506.1, C507.1, C510.1, C511.1, C513.1, C514.1, C522.1, C523.1, C524.1, C525.1, C526.1, J501.6, R505.1, R506.1, R507.1, R508.1, R510.1, R511.1, U501.3 (VCCX/VCCIO2/VCCIO6/VCCIO7), U501.12 (VCCX/VCCIO2/VCCIO6/VCCIO7), U501.23 (VCCIO5), U501.44 (VCCIO4), U501.58 (VCCIO3), U501.64 (VCCX/VCCIO2/VCCIO6/VCCIO7), U501.67 (VCCIO1), U501.78 (VCCIO0), U502.8 (VCC), U503.5 (VCC), Y501.1 (EN), Y501.4 (Vdd); also elsewhere on the board
/ADC_DOUT: R518.1, U503.2; also elsewhere on the board
/AUDIO_BCLK: R514.2; also elsewhere on the board
/AUDIO_ENABLE: U504.4; also elsewhere on the board
/AUDIO_LRCLK: R515.2; also elsewhere on the board
/AUDIO_MCLK: R513.2; also elsewhere on the board
/Bare GW2AR-18 support/ADC_BUF: R519.2, U501.30 (IOB14B)
/Bare GW2AR-18 support/ADC_BUF_RAW: R519.1, U503.4
/Bare GW2AR-18 support/BCLK_FPGA: R514.1, U501.29 (IOB14A)
/Bare GW2AR-18 support/CONFIG_CLK: R504.1, U501.59 (IOR34B/MCLK/D4), U502.6 (CLK)
/Bare GW2AR-18 support/DAC_FPGA: R516.1, U501.31 (IOB18A)
/Bare GW2AR-18 support/ENABLE_FPGA: R517.1, U501.20 (IOL51B), U504.2
/Bare GW2AR-18 support/EXTR: R501.1, U501.47 (EXTR)
/Bare GW2AR-18 support/FLASH_CS: R505.2, U501.60 (IOR34A/MCS_N/D5), U502.1 (~CS)
/Bare GW2AR-18 support/FLASH_DI: U501.61 (IOR33B/MO/D6), U502.5 (DI/IO_{0})
/Bare GW2AR-18 support/FLASH_DO: U501.62 (IOR33A/MI/D7), U502.2 (DO/IO_{1})
/Bare GW2AR-18 support/FLASH_HOLD: R507.2, U502.7 (~HOLD/~RESET/IO_{3})
/Bare GW2AR-18 support/FLASH_WP: R506.2, U502.3 (~WP/IO_{2})
/Bare GW2AR-18 support/FPGA_CLK: R512.2, U501.4 (IOL7A/LPLL1_T_in)
/Bare GW2AR-18 support/JTAG_TCK: J501.1, R509.1, U501.6 (IOR26A/TCK)
/Bare GW2AR-18 support/JTAG_TDI: J501.3, R511.2, U501.7 (IOR26B/TDI)
/Bare GW2AR-18 support/JTAG_TDO: J501.5, U501.8 (IOR25A/TDO)
/Bare GW2AR-18 support/JTAG_TMS: J501.9, R510.2, U501.5 (IOR25B/TMS)
/Bare GW2AR-18 support/LRCLK_FPGA: R515.1, U501.26 (IOB6B)
/Bare GW2AR-18 support/MCLK_FPGA: R513.1, U501.25 (IOB6A)
/Bare GW2AR-18 support/MODE0: R502.1, U501.88 (IOR30A/MODE0)
/Bare GW2AR-18 support/MODE1: R503.1, U501.87 (IOR30B/MODE1)
/Bare GW2AR-18 support/PLL_L_1V0: C504.1, C515.1, C516.1, C517.1, L501.2, U501.14 (VCCPLLL1)
/Bare GW2AR-18 support/PLL_R_1V0: C509.1, C518.1, C519.1, C520.1, L502.2, U501.50 (VCCPLLR1)
/Bare GW2AR-18 support/RECONFIG_N: R508.2, SW501.1, U501.9 (IOR31B/RECONFIG_N)
/Bare GW2AR-18 support/XO_CLK: R512.1, Y501.3 (OUT)
/DAC_DIN: R516.2; also elsewhere on the board
/GND: C501.2, C502.2, C503.2, C504.2, C505.2, C506.2, C507.2, C508.2, C509.2, C510.2, C511.2, C512.2, C513.2, C514.2, C515.2, C516.2, C517.2, C518.2, C519.2, C520.2, C521.2, C522.2, C523.2, C524.2, C525.2, C526.2, C527.2, J501.2, J501.10, R501.2, R502.2, R503.2, R504.2, R509.2, R517.2, R518.2, SW501.2, U501.2 (VSS), U501.21 (VSS), U501.24 (VSS), U501.43 (VSS), U501.46 (VSS), U501.65 (VSS), U501.68 (VSS), U501.89 (EPAD), U502.4 (GND), U503.1, U503.3 (GND), U504.3 (GND), Y501.2 (GND); also elsewhere on the board
/MCU_SPI_CLK: U501.55 (IOR36B/SSPI_CS_N/D0); also elsewhere on the board
/MCU_SPI_CS: U501.49 (IOR49A); also elsewhere on the board
/MCU_SPI_MISO: U501.51 (IOR45A/RPLL2_T_in); also elsewhere on the board
/MCU_SPI_MOSI: U501.48 (IOR49B); also elsewhere on the board

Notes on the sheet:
BARE GW2AR-18 SDRAM QN88 - ENGINEERING DRAFT - NO DEV BOARD
U501: primary UG115-1.7.2E pinout; all VCCX and IO banks use switched +3V3_FPGA. Ground EP89.
PER-PIN BYPASS: place each C501-C514 adjacent to the U501 supply pin named in its Rating field.
PLL beads: 220ohm@100MHz, DCR <=0.1ohm; exact MPN/load/ripple review required. Core supply directly from regulator.
MODE0/1 1k low + internal MODE2 low = MSPI 000. FASTRD_N57 floats for normal read <30MHz; set bitstream config clock accordingly.
J501: 1TCK 2GND 3TDI 4NC 5TDO 6TARGET VREF 7NC 8NC 9TMS 10GND; powered target only. Reserve JTAG in bitstream.
24.576MHz oscillator candidate needs exact MPN/lands/supply review; requires PLL/RTL migration for 48kHz. Current bitstream is not compatible.
U503 isolates ADC output at VCC=0; U504 held-supply Schmitt buffer defaults AUDIO_ENABLE low. Intermediate-rail/backfeed/timing review pending.
MCU SPI boundaries have no buffers yet; complete MCU-domain isolation/boot-state review before layout. No READY/DONE/JTAGSEL_N pins bonded.

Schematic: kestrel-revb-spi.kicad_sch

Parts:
C801, C802: 100nF; C_0402_1005Metric; Rating 100nF / 16V X7R / local bypass; MPN CL05B104KO5NNNC; LCSC C1525
C803, C804: 100nF; C_0603_1608Metric; Rating 100nF / 16V X7R / local bypass
C805: 1nF; C_0603_1608Metric; Rating 1nF / 25V C0G / SENSE filter
R801, R802, R803, R804: 33ohm; R_0603_1608Metric; Rating 33ohm / output damping / tune on PCB
R805: 4.7k; R_0603_1608Metric; Rating 4.7k / 1% / FPGA CS idle
R806: 4.7k; R_0603_1608Metric; Rating 4.7k / 1% / MCU CS idle
R807: 10k; R_0603_1608Metric; Rating 10k / 1% / OE default disabled
R808: 10k; R_0603_1608Metric; Rating 10k / 1% / firmware enable default off
R809: 10k; R_0603_1608Metric; Rating 10k / 1% / open drain release pullup
R810: 63.4k; R_0603_1608Metric; Rating 63.4k / 0.1% / IO monitor high
R811: 10k; R_0603_1608Metric; Rating 10k / 0.1% / IO monitor low
U801: SN74AXC4T774PWR; TSSOP-16_4.4x5mm_P0.65mm
U802: TPS3808G01DBVR; SOT-23-6
U803: SN74LVC1G00DCKR; Texas_R-PDSO-G5_DCK-5

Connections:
/+3V3_D: C801.1, C803.1, C804.1, R806.1, R807.1, R809.1, U801.1 (DIR1), U801.2 (DIR2), U801.7 (DIR3), U801.16 (VCCA), U802.6 (VDD), U803.5 (VCC); also elsewhere on the board
/+3V3_FPGA: C802.1, R805.1, R810.1, U801.15 (VCCB); also elsewhere on the board
/GND: C801.2, C802.2, C803.2, C804.2, C805.2, R808.2, R811.2, U801.8 (DIR4), U801.10 (GND), U802.2 (GND), U803.3 (GND); also elsewhere on the board
/MCU_RAW_CLK: U801.4 (A2_CLK); also elsewhere on the board
/MCU_RAW_CS: R806.2, U801.3 (A1_CS); also elsewhere on the board
/MCU_RAW_MISO: R804.2; also elsewhere on the board
/MCU_RAW_MOSI: U801.5 (A3_MOSI); also elsewhere on the board
/MCU_RESET_N: U802.3 (~MR); also elsewhere on the board
/MCU_SPI_CLK: R802.2; also elsewhere on the board
/MCU_SPI_CS: R801.2, R805.2; also elsewhere on the board
/MCU_SPI_ENABLE: R808.1, U803.1; also elsewhere on the board
/MCU_SPI_MISO: U801.11 (B4_MISO); also elsewhere on the board
/MCU_SPI_MOSI: R803.2; also elsewhere on the board
/Power-domain SPI isolation/SPI_CLK_B: R802.1, U801.13 (B2_CLK)
/Power-domain SPI isolation/SPI_CS_B: R801.1, U801.14 (B1_CS)
/Power-domain SPI isolation/SPI_MISO_A: R804.1, U801.6 (A4_MISO)
/Power-domain SPI isolation/SPI_MOSI_B: R803.1, U801.12 (B3_MOSI)
/Power-domain SPI isolation/SPI_OE_N: R807.2, U801.9 (OE_N), U803.4
/Power-domain SPI isolation/SPI_RAIL_RELEASE: R809.2, U802.1 (~RESET), U803.2
/Power-domain SPI isolation/SPI_SENSE: C805.1, R810.2, R811.1, U802.5 (SENSE)

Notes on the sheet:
SPI POWER-DOMAIN BRIDGE - ENGINEERING DRAFT
GPIO7 enable defaults low. OE = NOT(enable AND rail release). MCU reset restarts supervisor delay.
63.4k/10k divider: nominal falling trip 2.9727V; CT open 12-28ms release. This is an isolation guard, not FPGA-valid proof.
Firmware must set CS high / CLK low before enabling, await FPGA configuration, and disable before controlled shutdown.
Ioff / VCC<100mV isolation; arbitrary ramps, 10MHz timing, pullup margins and Sydney sourcing remain to qualify.

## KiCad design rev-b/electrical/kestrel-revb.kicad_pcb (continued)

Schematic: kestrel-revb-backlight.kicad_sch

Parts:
C901: 4.7uF; C_0805_2012Metric; Rating 4.7uF / 25V X7R / input local
C902: 100nF; C_0603_1608Metric; Rating 100nF / 16V X7R / VIN bypass
C903: 2.2uF; C_1210_3225Metric; Rating 2.2uF / 50V X7R / effective >=1uF at 39V
C904: 100nF; C_0603_1608Metric; Rating 100nF / 16V X7R / buffer bypass
C905, C906: 4.7uF; C_0805_2012Metric; Rating 4.7uF / 16V X7R / effective >=1uF / LCD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
C907: 10pF; C_0603_1608Metric; Rating 10pF / 25V C0G / LCD feedforward
C908, C909: 4.7uF; C_0805_2012Metric; Rating 4.7uF / 16V X7R / effective >=1uF / tou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
C910: 10pF; C_0603_1608Metric; Rating 10pF / 25V C0G / touch feedforward
D901: SS16-E3/61T; D_SMA
L901: 10uH; L_Sunlord_MWSA0603S; Rating 10uH / shielded / Isat >=3A / MPN and l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
R901: 5.62ohm; R_0805_2012Metric; Rating 5.62ohm / 1% / >=0.125W / Kelvin sense
R902: 10k; R_0603_1608Metric; Rating 10k / 1% / MCU PWM default off
R903: 1k; R_0603_1608Metric; Rating 1k / 1% / control series
R904: 1M; R_1206_3216Metric; Rating 1M / 1% / 1206 / output bleed
R905: 100k; R_0603_1608Metric; Rating 100k / 1% / CTRL default off
R906: 33.2k; R_0603_1608Metric; Rating 33.2k / 0.1% / LCD upper feedback
R907: 10k; R_0603_1608Metric; Rating 10k / 0.1% / LCD lower feedback
R908: 30k; R_0603_1608Metric; Rating 30k / 0.1% / touch upper feedback
R909: 10k; R_0603_1608Metric; Rating 10k / 0.1% / touch lower feedback
TP901: BL_LED_A; TestPoint_Pad_D1.0mm
TP902: BL_LED_K; TestPoint_Pad_D1.0mm
TP903: LCD_VDD; TestPoint_Pad_D1.0mm
TP904: TOUCH_VDD; TestPoint_Pad_D1.0mm
U901: TPS61169DCKR; Texas_R-PDSO-G5_DCK-5
U902: SN74LVC1G125DCKR; Texas_R-PDSO-G5_DCK-5
U903, U904: TLV76701DRVR; WSON-6-1EP_2x2mm_P0.65mm_EP1x1.6mm_ThermalVias

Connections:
/+5V_DIG: C901.1, C902.1, C904.1, C905.1, C908.1, L901.1, U901.5 (VIN), U902.5 (VCC), U903.4 (EN), U903.6 (IN), U904.4 (EN), U904.6 (IN); also elsewhere on the board
/BL_LED_A: C903.1, D901.1 (K), R904.1, TP901.1; also elsewhere on the board
/BL_LED_K: R901.1, TP902.1, U901.3 (FB); also elsewhere on the board
/Backlight and display supplies/BL_CTRL: R903.2, R905.1, U901.4 (CTRL)
/Backlight and display supplies/BL_CTRL_BUFFER: R903.1, U902.4
/Backlight and display supplies/BL_SW: D901.2 (A), L901.2, U901.1 (SW)
/Backlight and display supplies/LCD_FB: C907.2, R906.2, R907.1, U903.2 (FB)
/Backlight and display supplies/TOUCH_FB: C910.2, R908.2, R909.1, U904.2 (FB)
/GND: C901.2, C902.2, C903.2, C904.2, C905.2, C906.2, C908.2, C909.2, R901.2, R902.2, R904.2, R905.2, R907.2, R909.2, U901.2 (GND), U902.1, U902.3 (GND), U903.3 (GND), U903.5 (GND), U903.7 (PAD), U904.3 (GND), U904.5 (GND), U904.7 (PAD); also elsewhere on the board
/LCD_VDD: C906.1, C907.1, R906.1, TP903.1, U903.1 (OUT); also elsewhere on the board
/MCU_BL_PWM: R902.1, U902.2; also elsewhere on the board
/TOUCH_VDD: C909.1, C910.1, R908.1, TP904.1, U904.1 (OUT); also elsewhere on the board

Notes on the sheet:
ONBOARD BACKLIGHT BOOST - REFERENCE PANEL - ENGINEERING DRAFT
GPIO8 PWM defaults low. Use 5-100kHz; buffered on 5V domain with Ioff; controlled by firmware.
5.62ohm sets 36.30mA nominal / <=39.55mA conditional TA>=25C limits. Cold-temperature regulation remains to qualify.
J1001: pin2 anode / pin1 cathode. Never ground LED cathode; Kelvin route to FB and R901.
Disabled boost retains VIN-to-output passive path. Panel Vf must exceed VIN; no hard output disconnect or hot-plug claim.
LCD and touch supplies onboard. Panel contact orientation, exact parts/effective capacitance and qualification pending.
LCD LOGIC: TLV76701 / 33.2k:10k 0.1% / 3.456V nominal. Conditional DC corners 3.414..3.498V; not touch VDD.
Panel VDD 3.3..3.6V. 5V source headroom, load/thermal, effective capacitors, bus levels and ramp/backfeed require qualification.
TI adjustable DRV pins: 1 OUT, 2 FB, 3/5/EP GND, 4 EN, 6 IN. TP903 probes LCD power; J1001 is the LCD connector.
TOUCH: 30k:10k 0.1% / 3.2V nominal. GT911 recommended supply max3.3V, absolute max3.47V. Do not use LCD_VDD.
Touch load, exact capacitors, reset/address timing, rail-ramp/backfeed and GPIO/I2C behavior require qualification.

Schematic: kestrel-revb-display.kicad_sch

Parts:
C1001, C1002, C1003, C1004: 100nF; C_0603_1608Metric; Rating 100nF / 16V X7R / FPC supply bypass
J1001: LCD RGB / contact fit pending; Hirose_FH12-40S-0.5SH_1x40-1MP_P0.50mm_Horizontal
J1002: CAP TOUCH / contact fit pending; Hirose_FH12-8S-0.5SH_1x08-1MP_P0.50mm_Horizontal
R1001, R1002, R1003, R1004, R1005, R1006, R1007, R1008, R1009, R1010, R1011, R1012, R1013, R1014, R1015, R1016: 33ohm; R_0402_1005Metric; Rating 33ohm / 1% / 0.063W at 70C / 50V limiti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; MPN RC0402FR-0733RL; LCSC C138002
R1017, R1018, R1019, R1020, R1021, R1022, R1023, R1024, R1025: 33ohm; R_0603_1608Metric; Rating 33ohm / 1% / GPIO source damping starti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
R1026, R1027: 4.7k; R_0603_1608Metric; Rating 4.7k / 1% / I2C pullup to touch rail
R1028, R1029: 10k; R_0603_1608Metric; Rating 10k / 1% / default low
R1030: 100k; R_0603_1608Metric; Rating 100k / 1% / default low

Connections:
/BL_LED_A: J1001.2; also elsewhere on the board
/BL_LED_K: J1001.1; also elsewhere on the board
/GND: C1001.2, C1002.2, C1003.2, C1004.2, J1001.3, J1001.5, J1001.6, J1001.7, J1001.13, J1001.14, J1001.21, J1001.22, J1001.23, J1001.29, J1001.36, J1002.1, J1002.8, R1028.2, R1029.2, R1030.2; also elsewhere on the board
/LCD_VDD: C1001.1, C1002.1, J1001.4; also elsewhere on the board
/MCU_LCD_B3: R1001.1; also elsewhere on the board
/MCU_LCD_B4: R1002.1; also elsewhere on the board
/MCU_LCD_B5: R1003.1; also elsewhere on the board
/MCU_LCD_B6: R1004.1; also elsewhere on the board
/MCU_LCD_B7: R1005.1; also elsewhere on the board
/MCU_LCD_DE: R1020.1; also elsewhere on the board
/MCU_LCD_DISP: R1021.1; also elsewhere on the board
/MCU_LCD_G2: R1006.1; also elsewhere on the board
/MCU_LCD_G3: R1007.1; also elsewhere on the board
/MCU_LCD_G4: R1008.1; also elsewhere on the board
/MCU_LCD_G5: R1009.1; also elsewhere on the board
/MCU_LCD_G6: R1010.1; also elsewhere on the board
/MCU_LCD_G7: R1011.1; also elsewhere on the board
/MCU_LCD_HSYNC: R1018.1; also elsewhere on the board
/MCU_LCD_PCLK: R1017.1; also elsewhere on the board
/MCU_LCD_R3: R1012.1; also elsewhere on the board
/MCU_LCD_R4: R1013.1; also elsewhere on the board
/MCU_LCD_R5: R1014.1; also elsewhere on the board
/MCU_LCD_R6: R1015.1; also elsewhere on the board
/MCU_LCD_R7: R1016.1; also elsewhere on the board
/MCU_LCD_VSYNC: R1019.1; also elsewhere on the board
/MCU_TOUCH_INT: R1024.1; also elsewhere on the board
/MCU_TOUCH_RST_N: R1025.1; also elsewhere on the board
/MCU_TOUCH_SCL: R1022.1; also elsewhere on the board
/MCU_TOUCH_SDA: R1023.1; also elsewhere on the board
/RGB565 and capacitive touch/LCD_B3: J1001.24, R1001.2
/RGB565 and capacitive touch/LCD_B4: J1001.25, R1002.2
/RGB565 and capacitive touch/LCD_B5: J1001.26, R1003.2
/RGB565 and capacitive touch/LCD_B6: J1001.27, R1004.2
/RGB565 and capacitive touch/LCD_B7: J1001.28, R1005.2
/RGB565 and capacitive touch/LCD_DE: J1001.34, R1020.2
/RGB565 and capacitive touch/LCD_DISP: J1001.31, R1021.2, R1028.1
/RGB565 and capacitive touch/LCD_G2: J1001.15, R1006.2
/RGB565 and capacitive touch/LCD_G3: J1001.16, R1007.2
/RGB565 and capacitive touch/LCD_G4: J1001.17, R1008.2
/RGB565 and capacitive touch/LCD_G5: J1001.18, R1009.2
/RGB565 and capacitive touch/LCD_G6: J1001.19, R1010.2
/RGB565 and capacitive touch/LCD_G7: J1001.20, R1011.2
/RGB565 and capacitive touch/LCD_HSYNC: J1001.32, R1018.2
/RGB565 and capacitive touch/LCD_PCLK: J1001.30, R1017.2
/RGB565 and capacitive touch/LCD_R3: J1001.8, R1012.2
/RGB565 and capacitive touch/LCD_R4: J1001.9, R1013.2
/RGB565 and capacitive touch/LCD_R5: J1001.10, R1014.2
/RGB565 and capacitive touch/LCD_R6: J1001.11, R1015.2
/RGB565 and capacitive touch/LCD_R7: J1001.12, R1016.2
/RGB565 and capacitive touch/LCD_VSYNC: J1001.33, R1019.2
/RGB565 and capacitive touch/TOUCH_INT: J1002.6, R1024.2, R1030.1
/RGB565 and capacitive touch/TOUCH_RST_N: J1002.7, R1025.2, R1029.1
/RGB565 and capacitive touch/TOUCH_SCL: J1002.4, R1022.2, R1026.2
/RGB565 and capacitive touch/TOUCH_SDA: J1002.5, R1023.2, R1027.2
/TOUCH_VDD: C1003.1, C1004.1, J1002.2, J1002.3, R1026.1, R1027.1; also elsewhere on the board

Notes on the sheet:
RGB565 / CAPACITIVE TOUCH - DM-TFT50-404 REFERENCE - ENGINEERING DRAFT
RGB565: GPIO39/40/41/42/43 -> B3..7; GPIO44/45/46/47/32/49 -> G2..7; GPIO26/27/28/33/30 -> R3..7. Low panel data bits grounded.
GPIO9 PCLK / 10 HSYNC / 11 VSYNC / 12 DE / 13 DISP. GPIO15 SCL / 16 SDA / 17 INT / 18 RESET.
LCD power 3.456V; GT911 VDD/VDDIO 3.2V. 4.7k I2C pullups to TOUCH_VDD. INT is bidirectional during reset/address selection.
FPC contact side/numbering/thickness, exact parts, loaded signal timing, reset/address sequence and power-off/backfeed pending.
R1001..R1025 are source-damping starting values; place appropriately near drivers. No external hot-plug or EMC rating established.

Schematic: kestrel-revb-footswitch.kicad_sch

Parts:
C1101, C1103: 100nF; C_0603_1608Metric; Rating 100nF / 16V X7R / RC filter / effective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
C1102, C1104: 100nF; C_0603_1608Metric; Rating 100nF / 16V X7R / buffer bypass
D1101, D1102: PESD5V0U1BA,115; D_SOD-323
J1101, J1102: FOOT WIRE: 1SIGNAL 2GND; SolderWire-0.127sqmm_1x02_P3.7mm_D0.48mm_OD1mm_Relief2x
R1101, R1104: 1k; R_0603_1608Metric; Rating 1k / 1% / wire input series
R1102, R1105: 10k; R_0603_1608Metric; Rating 10k / 1% / input pullup
R1103, R1106: 33ohm; R_0603_1608Metric; Rating 33ohm / 1% / GPIO source damping
SW1101, SW1102: SWFS0013 / silent momentary NO / candidate
U1101, U1102: SN74LVC1G17DCKR; Texas_R-PDSO-G5_DCK-5

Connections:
/+3V3_D: C1102.1, C1104.1, R1102.1, R1105.1, U1101.5 (VCC), U1102.5 (VCC); also elsewhere on the board
/GND: C1101.2, C1102.2, C1103.2, C1104.2, D1101.2 (A2), D1102.2 (A2), J1101.2, J1102.2, SW1101.2, SW1102.2, U1101.3 (GND), U1102.3 (GND); also elsewhere on the board
/MCU_FOOT0_N: R1103.2; also elsewhere on the board
/MCU_FOOT1_N: R1106.2; also elsewhere on the board
/Two momentary footswitch inputs/FOOT_BUF_0: R1103.1, U1101.4
/Two momentary footswitch inputs/FOOT_BUF_1: R1106.1, U1102.4
/Two momentary footswitch inputs/FOOT_RAW_0: D1101.1 (A1), J1101.1, R1101.1, SW1101.1
/Two momentary footswitch inputs/FOOT_RAW_1: D1102.1 (A1), J1102.1, R1104.1, SW1102.1
/Two momentary footswitch inputs/FOOT_RC_0: C1101.1, R1101.2, R1102.2, U1101.2
/Two momentary footswitch inputs/FOOT_RC_1: C1103.1, R1104.2, R1105.2, U1102.2

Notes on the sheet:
TWO PANEL-MOUNT MOMENTARY FOOTSWITCHES - ACTIVE LOW - ENGINEERING DRAFT
GPIO20 pad22 = left / GPIO21 pad23 = right. Switches close signal to ground; mount loads on enclosure, not PCB.
10k pullup / 1k series / 100nF RC / Schmitt buffer. Short interference filtering is not complete contact debounce.
SWFS0013 is a local A$5 silent SPST candidate: manufacturer/current rating, dry-contact life and exact geometry unqualified.
PESD wire shunts do not establish system ESD/fault rating. Qualify residual stress, firmware edges, wiring and physical loads.



Board: 4 copper layers, 136.0 x 106.0 mm, 351 parts (19 on the bottom side), 199 nets.

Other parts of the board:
H1, H2, H3, H4: MountingHole_3.2mm_M3

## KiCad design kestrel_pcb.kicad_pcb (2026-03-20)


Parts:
C1, C2, C3, C6, C10, C11, C14, C16, C17, C18, C21, C24, C26: 0.1uF; C_0603_1608Metric; LCSC C14663
C4, C7, C19, C20: 10uF; C_0603_1608Metric; LCSC C19702
C5, C8, C12, C15, C22, C23: 1uF; C_0603_1608Metric; LCSC C15849
C9, C13: 2.2uF; C_0603_1608Metric; LCSC C23630
C25: 47uF; C_0603_1608Metric; LCSC C1622
D1, D2, D3: D_Schottky; D_0603_1608Metric; LCSC C3312582
FB1, FB2: 600; L_0603_1608Metric; LCSC C48543396
J1: tang nano 20k left pins; PinSocket_1x20_P2.54mm_Vertical
J2: tang nano 20k right pins; PinSocket_1x20_P2.54mm_Vertical
J3: esp32-p4-pico left pins; PinSocket_1x20_P2.54mm_Vertical
J4: esp32-p4-pico right pins; PinSocket_1x20_P2.54mm_Vertical
J7: Conn_01x04_Pin; PinSocket_1x04_P2.54mm_Vertical
J10, J11: AudioJack3_Ground; Jack_6.35mm_Neutrik_NMJ4HCD2_Horizontal
J12: Barrel_Jack_MountingPin; BarrelJack_Horizontal
R1, R12: 47; R_0603_1608Metric; LCSC C114623
R2, R3, R13: 47k; R_0603_1608Metric; LCSC C105579
R4, R10: 22K; R_0603_1608Metric; LCSC C114065
R5, R11: 10K; R_0603_1608Metric; LCSC C98220
R6, R20: 1M; R_0603_1608Metric; LCSC C105578
R7: 47K; R_0603_1608Metric; LCSC C105579
R8, R9: 100K; R_0603_1608Metric; LCSC C14675
R14, R15: 4.7K; R_0603_1608Metric; LCSC C99782
R16, R17, R18, R19: 33; R_0603_1608Metric; LCSC C2909394
SW1, SW2: Switch_3PDT
U1: SGTL5000XNLA3; QFN-20-1EP_3x3mm_P0.4mm_EP1.65x1.65mm; LCSC C2802658
U2, U3: TL072; DIP-8_W7.62mm
U4: TLV75518PDBV; SOT-23-5; LCSC C2877863
U5: TLV75533PDBV; SOT-23-5; LCSC C404027

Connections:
+1V8: C12.1, C24.1, U1.20 (VDDD), U4.5 (OUT)
+3V3: C9.1, C10.1, C11.1, C15.1, C23.1, FB1.2, R14.2, R15.2, U1.12 (VDDIO), U4.1 (IN), U4.3 (EN), U5.5 (OUT)
+5V: D2.2 (A), D3.2 (A), FB2.2, J7.3; also elsewhere on the board
+9V: C16.1, C17.1, C25.1, C26.1, D1.1 (K), J7.2, R2.1, R8.1, R13.2, U2.8 (V+), U3.8 (V+); also elsewhere on the board
BCLK: R18.1, U1.15 (I2S_SCLK)
GND: C2.1, C3.2, C4.2, C6.1, C7.2, C9.2, C10.2, C11.2, C12.2, C13.1, C14.2, C15.2, C16.2, C17.2, C18.1, C19.1, C20.1, C21.1, C22.2, C23.2, C24.2, C25.2, C26.2, J2.2, J4.3, J7.4, J10.G, J10.S, J11.G, J11.S, J12.1, R3.2, R5.2, R7.1, R9.2, R20.2, SW1.1, SW1.4, SW2.1, SW2.4, U1.21 (GND), U2.4 (V-), U3.4 (V-), U4.2 (GND), U5.2 (GND); also elsewhere on the board
I2S_DIN: J1.13, R19.1
I2S_DOUT: R16.1, U1.17 (I2S_DIN)
LRCLK: R17.1, U1.14 (I2S_LRCLK)
MLCK: R1.1, U1.13 (SYS_MCLK)
unnamed: C1.1, J10.T
unnamed: C5.1, R4.2, R5.1
unnamed: C7.1, R11.2
unnamed: C8.1, R10.2, U3.1
unnamed: C8.2, J11.T, R20.1
unnamed: D1.2 (A), J12.2
unnamed: C18.2, C19.2, D2.1 (K), J2.1
unnamed: C20.2, C21.2, D3.1 (K), J4.2
unnamed: J1.10, R1.2
unnamed: J1.11, R17.2
unnamed: J1.12, R18.2
unnamed: J1.14, R16.2
unnamed: J2.9, J3.9
unnamed: J2.10, J3.10
unnamed: J2.11, J3.11
unnamed: J2.12, J3.12
unnamed: J4.6, SW1.2, SW1.5
unnamed: J4.7, SW2.2, SW2.5
unnamed 28: J7.1, R13.1; also elsewhere on the board
unnamed: R4.1, R12.2
unnamed: R19.2, U1.16 (I2S_DOUT)
unnamed: C5.2, U1.9 (LINEIN_L)
unnamed: R7.2, U1.8 (LINEIN_R)
unnamed: R8.2, R9.1, U1.7 (LINEOUT_L), U3.3 (+)
unnamed: C6.2, U1.11 (MIC_BIAS)
unnamed: C2.2, U1.5 (VAG)
unnamed: C13.2, C14.1, FB1.1, U1.3 (VDDA)
unnamed: C1.2, R6.1, U2.3 (+)
unnamed: R12.1, U2.1, U2.2 (-)
unnamed: C3.1, C4.1, R2.2, R3.1, U2.5 (+)
unnamed: R6.2, U2.6 (-), U2.7
unnamed: R10.1, R11.1, U3.2 (-)
unnamed: C22.1, FB2.1, U5.1 (IN), U5.3 (EN)
SCL: J2.13, J3.14, R14.1, U1.19 (CTRL_CLK)
SDA: J2.14, J3.15, R15.1, U1.18 (CTRL_DATA)



Board: 4 copper layers, 142.2 x 134.6 mm, 66 parts (3 on the bottom side), 45 nets.

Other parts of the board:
MPM3610: Conn_01x04_Pin; PinSocket_1x04_P2.54mm_Vertical

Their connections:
+5V: MPM3610.3; also elsewhere on the board
+9V: MPM3610.2; also elsewhere on the board
GND: MPM3610.4; also elsewhere on the board
unnamed 28: MPM3610.1; also elsewhere on the board

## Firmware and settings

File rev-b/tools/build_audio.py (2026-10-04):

#!/usr/bin/env python3
"""Generate hardware-strapped converters, SMD input buffer and analogue LDOs.

Run with the KiCad MCP venv. Datasheet-derived symbols are embedded; the local
reservoir footprint uses Panasonic's standard FK size-G recommended lands.
"""
import argparse
import math
import sys
import uuid
from pathlib import Path

ROOT = Path(__file__).resolve().parents[1]
GRID = 1.27


def uid(name):
    return str(uuid.uuid5(uuid.NAMESPACE_URL, "kestrel/rev-b/audio/"+name))


def adc_library():
    """PCM1808 pin table from TI SLES177B p3; no inherited approximated part."""
    pins = [
        (1,"VREF","passive",10,8,180),
        (2,"AGND","power_in",2,-14,90),
        (3,"VCC","power_in",-2,14,270),
        (4,"VDD","power_in",2,14,270),
        (5,"DGND","power_in",-2,-14,90),
        (6,"SCKI","input",-10,-2,0),
        (7,"LRCK","bidirectional",-10,2,0),
        (8,"BCK","bidirectional",-10,0,0),
        (9,"DOUT","output",10,4,180),
        (10,"MD0","input",-10,-8,0),
        (11,"MD1","input",-10,-10,0),
        (12,"FMT","input",-10,-6,0),
        (13,"VINL","input",-10,10,0),
        (14,"VINR","input",-10,8,0),
    ]
    effects = '(effects (font (size 1.27 1.27)))'
    body = ''.join(f'(pin {kind} line (at {x*GRID} {y*GRID} {angle}) (length 2.54) '
                   f'(name "{name}" {effects}) (number "{num}" {effects}))'
                   for num,name,kind,x,y,angle in pins)
    return ('(kicad_symbol_lib (version 20241209) (generator "kicad_symbol_editor") '
            '(symbol "PCM1808" (pin_names (offset 0.508)) (in_bom yes) (on_board yes) '
            f'(property "Reference" "U" (at -10.16 17.78 0) {effects}) '
            f'(property "Value" "PCM1808" (at 2.54 17.78 0) {effects}) '
            '(property "Footprint" "Package_SO:TSSOP-14_4.4x5mm_P0.65mm" (at 0 0 0) '
            f'{effects[:-1]} (hide yes))) '
            '(property "Datasheet" "https://www.ti.com/lit/ds/symlink/pcm1808.pdf" (at 0 0 0) '
            f'{effects[:-1]} (hide yes))) '
            '(symbol "PCM1808_0_1" (rectangle (start -10.16 15.24) (end 10.16 -15.24) '
            '(stroke (width 0.254) (type default)) (fill (type background)))) '
            f'(symbol "PCM1808_1_1" {body})))\n')


def build(mcp_dir):
    sys.path.insert(0,str(mcp_dir))
    import sexpdata as sx
    from commands.dynamic_symbol_loader import DynamicSymbolLoader
    from utils.sexpr_format import dumps
    folder = ROOT/"electrical"
    folder.mkdir(exist_ok=True)
    loader=DynamicSymbolLoader(folder)
    library=sx.loads(adc_library())
    # Same series-diode drawing as BAV99, with BAV199 pin names/specification.
    diode=sx.loads(loader.extract_symbol_from_library("Diode","BAV99"))
    diode[1]="BAV199"
    S=sx.Symbol
    # Derive the body/courtyard from KiCad's generic 10-mm capacitor; use
    # Panasonic FK standard size G lands (gap 4.6, length 4.1, width 2.0 mm).
    footprint=sx.loads(Path("/usr/share/kicad/footprints/Capacitor_SMD.pretty/CP_Elec_10x10.5.kicad_mod").read_text())
    footprint[1]="CP_Elec_Panasonic_FK_G_10x10.2"
    for item in footprint:
        if not isinstance(item,list) or not item: continue
        if item[0]==S("descr"):
            item[1]="Panasonic FK standard size G; 10.2 +/-0.3 mm height, 10 mm diameter; manufacturer 4.6 mm gap / 4.1x2 mm lands; KiCad generic body/model"
        if item[0]==S("property") and item[1]=="Value": item[2]=footprint[1]
        if item[0]==S("pad"):
            item[3]=S("rect")
            next(x for x in item if isinstance(x,list) and x and x[0]==S("at"))[1]=(-4.35 if item[1]=="1" else 4.35)
            next(x for x in item if isinstance(x,list) and x and x[0]==S("size"))[1:]=[4.1,2.0]
            item[:]=[x for x in item if not (isinstance(x,list) and x and x[0]==S("roundrect_rratio"))]
    pretty=folder/"KestrelAudio.pretty"
    pretty.mkdir(exist_ok=True)
    (pretty/(footprint[1]+".kicad_mod")).write_text(dumps(footprint)+"\n")
    (folder/"fp-lib-table").write_text('(fp_lib_table (version 7) (lib (name "KestrelAudio") '
        '(type "KiCad") (uri "${KIPRJMOD}/KestrelAudio.pretty") (options "") '
        '(descr "Manufacturer land patterns for Rev-B audio")))\n')
    for item in diode:
        if not isinstance(item,list) or not item: continue
        if item[0]==S("property"):
            values={"Value":"BAV199","Datasheet":"https://assets.nexperia.com/documents/data-sheet/BAV199.pdf",
                    "Description":"Nexperia low-leakage series double diode, SOT23"}
            if item[1] in values: item[2]=values[item[1]]
        if item[0]==S("symbol"):
            item[1]=str(item[1]).replace("BAV99_","BAV199_")
            for pin in item:
                if not isinstance(pin,list) or not pin or pin[0]!=S("pin"): continue
                number=next(v[1] for v in pin if isinstance(v,list) and v and v[0]==S("number"))
                next(v for v in pin if isinstance(v,list) and v and v[0]==S("name"))[1]={"1":"A1","2":"K2","3":"K1/A2"}[str(number)]
    library.append(diode)
    supervisor=sx.loads(loader.extract_symbol_from_library("Power_Supervisor","TPS3808DBV"))
    supervisor[1]="TPS3808G01"
    for item in supervisor:
        if not isinstance(item,list) or not item: continue
        if item[0]==S("property") and item[1]=="Value": item[2]="TPS3808G01"
        if item[0]==S("property") and item[1]=="Datasheet": item[2]="https://www.ti.com/lit/ds/symlink/tps3808.pdf"
        if item[0]==S("symbol"):
            item[1]=str(item[1]).replace("TPS3808DBV_","TPS3808G01_")
            for pin in item:
                if not isinstance(pin,list) or not pin or pin[0]!=S("pin"): continue
                number=next(v[1] for v in pin if isinstance(v,list) and v and v[0]==S("number"))
                if str(number)=="1": pin[1]=S("open_collector")
    library.append(supervisor)
    (folder/"KestrelAudio.kicad_sym").write_text(dumps(library)+"\n")
    (folder/"sym-lib-table").write_text('(sym_lib_table (version 7) '
        '(lib (name "KestrelAudio") (type "KiCad") '
        '(uri "${KIPRJMOD}/KestrelAudio.kicad_sym") (options "") '
        '(descr "Datasheet-checked audio converter, protection and supervisor symbols")))\n')
    out=folder/"kestrel-revb-audio.kicad_sch"
    out.write_text(f'(kicad_sch (version 20260101) (generator "eeschema") '
                   f'(generator_version "10.0") (uuid "{uid("sheet")}") '
                   '(paper "A2") (lib_symbols) (sheet_instances (path "/" (page "1"))))\n')
    cap = "Capacitor_SMD:C_0603_1608Metric"
    bulk = "Capacitor_SMD:C_0805_2012Metric"
    res = "Resistor_SMD:R_0603_1608Metric"
    # Each connection is a datasheet/design net, separate from its visual placement.
    parts = [
      ("U201","KestrelAudio:PCM1808","PCM1808PWR","Package_SO:TSSOP-14_4.4x5mm_P0.65mm",75,55,0,
       {"1":"ADC_VREF","2":"GND","3":"+5V_A","4":"+3V3_D","5":"GND",
        "6":"AUDIO_MCLK","7":"AUDIO_LRCLK","8":"AUDIO_BCLK","9":"ADC_DOUT",
        "10":"ADC_MD0","11":"ADC_MD1","12":"ADC_FMT","13":"ADC_IN_L","14":"ADC_IN_R"}),
      ("U202","Audio:PCM5102A","PCM5102APWR","Package_SO:TSSOP-20_4.4x6.5mm_P0.65mm",195,55,0,
       {"1":"+3V3_A","2":"DAC_CAPP","3":"GND","4":"DAC_CAPM","5":"DAC_VNEG",
        "6":"DAC_OUT_L","7":None,"8":"+3V3_A","9":"GND","10":"GND","11":"+3V3_A",
        "12":"GND","13":"AUDIO_BCLK","14":"DAC_DIN","15":"AUDIO_LRCLK","16":"GND",
        "17":"AUDIO_RUN","18":"DAC_LDOO","19":"GND","20":"+3V3_A"}),
      ("C201","Device:C","1uF",bulk,36,45,90,{"1":"AFE_OUT","2":"ADC_AC_L"}),
      ("R201","Device:R","100",res,49,45,90,{"1":"ADC_AC_L","2":"ADC_IN_L"}),
      ("C202","Device:C","10nF",cap,25,53,0,{"1":"ADC_IN_L","2":"GND"}),
      ("C203","Device:C","1uF",bulk,36,62,90,{"1":"GND","2":"ADC_IN_R"}),
      ("R202","Device:R","10k",res,46,86,0,{"1":"ADC_FMT","2":"GND"}),
      ("R203","Device:R","10k",res,60,86,0,{"1":"ADC_MD0","2":"GND"}),
      ("R204","Device:R","10k",res,74,86,0,{"1":"ADC_MD1","2":"GND"}),
      ("R205","Device:R","100k",res,175,86,0,{"1":"AUDIO_RUN","2":"GND"}),
      ("C204","Device:C","10uF",bulk,32,113,0,{"1":"+5V_A","2":"GND"}),
      ("C205","Device:C","100nF",cap,46,113,0,{"1":"+5V_A","2":"GND"}),
      ("C206","Device:C","10uF",bulk,64,113,0,{"1":"+3V3_D","2":"GND"}),
      ("C207","Device:C","100nF",cap,78,113,0,{"1":"+3V3_D","2":"GND"}),
      ("C208","Device:C","10uF",bulk,96,113,0,{"1":"ADC_VREF","2":"GND"}),
      ("C209","Device:C","100nF",cap,110,113,0,{"1":"ADC_VREF","2":"GND"}),
      ("C210","Device:C","10uF",bulk,152,113,0,{"1":"+3V3_A","2":"GND"}),
      ("C211","Device:C","100nF",cap,166,113,0,{"1":"+3V3_A","2":"GND"}),
      ("C212","Device:C","10uF",bulk,184,113,0,{"1":"+3V3_A","2":"GND"}),
      ("C213","Device:C","100nF",cap,198,113,0,{"1":"+3V3_A","2":"GND"}),
      ("C214","Device:C","10uF",bulk,216,113,0,{"1":"+3V3_A","2":"GND"}),
      ("C215","Device:C","100nF",cap,230,113,0,{"1":"+3V3_A","2":"GND"}),
      ("C216","Device:C","10uF",bulk,226,85,0,{"1":"DAC_LDOO","2":"GND"}),
      ("C217","Device:C","100nF",cap,240,85,0,{"1":"DAC_LDOO","2":"GND"}),
      ("C218","Device:C","2.2uF",bulk,228,52,0,{"1":"DAC_CAPP","2":"DAC_CAPM"}),
      ("C219","Device:C","2.2uF",bulk,250,72,0,{"1":"GND","2":"DAC_VNEG"}),
      ("R206","Device:R","470",res,240,37,90,{"1":"DAC_OUT_L","2":"AUDIO_OUT"}),
      ("C220","Device:C","2.2nF C0G",cap,256,45,0,{"1":"AUDIO_OUT","2":"GND"}),
      # FET input buffer and separate buffered bias; the ADC keeps its own bias.
      ("U203","Amplifier_Operational:OPA1656ID","OPA1656IDR","Package_SO:SOIC-8_3.9x4.9mm_P1.27mm",70,164,0,
       {"1":"INPUT_BUFFER","2":"INPUT_BUFFER","3":"INPUT_BIASED"},1),
      ("U203","Amplifier_Operational:OPA1656ID","OPA1656IDR","Package_SO:SOIC-8_3.9x4.9mm_P1.27mm",135,164,0,
       {"5":"BIAS_RAW","6":"VMID_BUF","7":"VMID_BUF"},2),
      ("U203","Amplifier_Operational:OPA1656ID","OPA1656IDR","Package_SO:SOIC-8_3.9x4.9mm_P1.27mm",135,194,0,
       {"4":"GND","8":"9V_PROTECTED"},3),
      ("R207","Device:R","10M",res,25,183,0,{"1":"AUDIO_IN","2":"GND"}),
      ("C221","Device:C","47nF C0G","Capacitor_SMD:C_1206_3216Metric",25,164,90,{"1":"AUDIO_IN","2":"INPUT_AC"}),
      ("R208","Device:R","4.7k","Resistor_SMD:R_1206_3216Metric",45,164,90,{"1":"INPUT_AC","2":"INPUT_BIASED"}),
      ("R209","Device:R","1M",res,52,183,0,{"1":"INPUT_BIASED","2":"VMID"}),
      ("R210","Device:R","1k",res,100,164,90,{"1":"INPUT_BUFFER","2":"AFE_OUT"}),
      ("R211","Device:R","1k",res,90,183,0,{"1":"AFE_OUT","2":"VMID"}),
      ("R212","Device:R","17.4k",res,112,151,0,{"1":"9V_PROTECTED","2":"BIAS_RAW"}),
      ("R213","Device:R","10k",res,112,177,0,{"1":"BIAS_RAW","2":"GND"}),
      ("C222","Device:C","10uF",bulk,112,199,0,{"1":"BIAS_RAW","2":"GND"}),
      # Isolation from capacitive load on the unity-gain bias buffer.
      ("R214","Device:R","47",res,172,164,90,{"1":"VMID_BUF","2":"VMID"}),
      ("C223","Device:C","10uF",bulk,178,183,0,{"1":"VMID","2":"GND"}),
      ("C224","Device:C","100nF",cap,153,194,0,{"1":"9V_PROTECTED","2":"GND"}),
      ("C225","Device:C","10uF",bulk,168,194,0,{"1":"9V_PROTECTED","2":"GND"}),
      # ADC analogue rail is linear from 9 V: a 5 V buck cannot feed a 5 V LDO.
      ("U204","Regulator_Linear:TLV76750DRVx","TLV76750DRVR","Package_SON:WSON-6-1EP_2x2mm_P0.65mm_EP1x1.6mm_ThermalVias",221,158,0,
       {"1":"+5V_A","2":"+5V_A","3":"GND","4":"9V_PROTECTED","5":"GND","6":"9V_PROTECTED","7":"GND"}),
      ("C226","Device:C","2.2uF",bulk,196,158,0,{"1":"9V_PROTECTED","2":"GND"}),
      ("C227","Device:C","2.2uF",bulk,248,158,0,{"1":"+5V_A","2":"GND"}),
      ("U205","Regulator_Linear:TLV75533PDBV","TLV75533PDBVR","Package_TO_SOT_SMD:SOT-23-5",221,188,0,
       {"1":"+5V_DAC_HOLD","2":"GND","3":"+5V_DAC_HOLD","4":None,"5":"+3V3_A"}),
      ("C228","Device:C","2.2uF",bulk,196,188,0,{"1":"+5V_DAC_HOLD","2":"GND"}),
      ("C229","Device:C","2.2uF",bulk,248,188,0,{"1":"+3V3_A","2":"GND"}),
      # Switched mono sockets: actual footprint pads are T/TN/S/SN, not T/R/S/G.
      # Input TN grounds the tip while unplugged; output TN must not short the DAC.
      ("J201","Connector_Audio:AudioJack2_Switch","NMJ4HCD2 INPUT",
       "Connector_Audio:Jack_6.35mm_Neutrik_NMJ4HCD2_Horizontal",290,45,0,
       {"T":"AUDIO_IN","TN":"GND","S":"GND","SN":None}),
      ("J202","Connector_Audio:AudioJack2_Switch","NMJ4HCD2 OUTPUT",
       "Connector_Audio:Jack_6.35mm_Neutrik_NMJ4HCD2_Horizontal",290,85,0,
       {"T":"AUDIO_OUT","TN":None,"S":"GND","SN":None}),
      # First-stage jack ESD clamps are bipolar; they do not certify IC immunity.
      ("D201","Device:D_TVS","PESD5V0U1BA,115","Diode_SMD:D_SOD-323",290,115,90,
       {"1":"AUDIO_IN","2":"GND"}),
      ("D202","KestrelAudio:BAV199","BAV199,215","Package_TO_SOT_SMD:SOT-23",45,199,0,
       {"1":"GND","2":"9V_PROTECTED","3":"INPUT_BIASED"}),
      ("D203","Device:D_TVS","PESD5V0U1BA,115","Diode_SMD:D_SOD-323",290,160,90,
       {"1":"AUDIO_OUT","2":"GND"}),
      # Isolate DAC energy storage from the buck and all main digital loads.
      ("D204","Diode:SS14","SS14-E3/61T","Diode_SMD:D_SMA",220,250,180,
       {"1":"+5V_DAC_HOLD","2":"+5V_DIG"}),
      ("C230","Device:C_Polarized","1000uF EEEFK1A102P","KestrelAudio:CP_Elec_Panasonic_FK_G_10x10.2",246,270,0,
       {"1":"+5V_DAC_HOLD","2":"GND"}),
      ("C235","Device:C_Polarized","1000uF EEEFK1A102P","KestrelAudio:CP_Elec_Panasonic_FK_G_10x10.2",276,270,0,
       {"1":"+5V_DAC_HOLD","2":"GND"}),
      ("U206","KestrelAudio:TPS3808G01","TPS3808G01DBVR","Package_TO_SOT_SMD:SOT-23-6",70,280,0,
       {"1":"AUDIO_RUN","2":"GND","3":"AUDIO_ENABLE","4":None,"5":"SENSE_ADC_5V","6":"+3V3_A"}),
      ("U207","KestrelAudio:TPS3808G01","TPS3808G01DBVR","Package_TO_SOT_SMD:SOT-23-6",165,280,0,
       {"1":"AUDIO_RUN","2":"GND","3":"AUDIO_ENABLE","4":None,"5":"SENSE_BUCK_5V","6":"+3V3_A"}),
      ("R215","Device:R","105k 0.1%",res,40,269,0,{"1":"+5V_A","2":"SENSE_ADC_5V"}),
      ("R216","Device:R","10k 0.1%",res,40,294,0,{"1":"SENSE_ADC_5V","2":"GND"}),
      ("R217","Device:R","105k 0.1%",res,135,269,0,{"1":"+5V_DIG","2":"SENSE_BUCK_5V"}),
      ("R218","Device:R","10k 0.1%",res,135,294,0,{"1":"SENSE_BUCK_5V","2":"GND"}),
      ("R219","Device:R","1k",res,110,280,0,{"1":"AUDIO_ENABLE","2":"GND"}),
      ("R220","Device:R","10k",res,205,280,0,{"1":"+3V3_A","2":"AUDIO_RUN"}),
      ("C231","Device:C","1nF C0G",cap,55,305,0,{"1":"SENSE_ADC_5V","2":"GND"}),
      ("C232","Device:C","1nF C0G",cap,150,305,0,{"1":"SENSE_BUCK_5V","2":"GND"}),
      ("C233","Device:C","100nF",cap,85,305,0,{"1":"+3V3_A","2":"GND"}),
      ("C234","Device:C","100nF",cap,180,305,0,{"1":"+3V3_A","2":"GND"}),
      ("#FLG0205","power:PWR_FLAG","PWR_FLAG","",246,245,0,{"1":"+5V_DAC_HOLD"}),
    ]
    shorter={"INPUT_BUFFER":"IN_BUF","INPUT_BIASED":"IN_BIAS","VMID_BUF":"BIAS_BUF"}
    parts=[(*p[:7],{pin:shorter.get(net,net) for pin,net in p[7].items()},p[8] if len(p)==9 else 1) for p in parts]
    for ref,lib,value,foot,x,y,angle,nets,unit in parts:
        library,name=lib.split(":")
        loader.inject_symbol_into_schematic(out,library,name)
        if not loader.create_component_instance(out,library,name,ref,value,foot,x*GRID,y*GRID,angle=angle,unit=unit):
            raise RuntimeError(ref)
    tree=sx.loads(out.read_text()); S=sx.Symbol
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

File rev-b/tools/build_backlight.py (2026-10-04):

#!/usr/bin/env python3
"""Generate onboard backlight boost and LCD logic supply. Run before project."""
import math
import sys
import uuid
from pathlib import Path
ROOT=Path(__file__).resolve().parents[1]
GRID=1.27
sys.path.insert(0,str(Path.home()/'.local/share/kicad-mcp/python'))
import sexpdata as sx
from commands.dynamic_symbol_loader import DynamicSymbolLoader
from utils.sexpr_format import dumps
S=sx.Symbol
def node(text):return sx.loads(text)
def child(e,key):return next(x for x in e if isinstance(x,list) and x and x[0]==S(key))
def uid(text):return str(uuid.uuid5(uuid.NAMESPACE_URL,'kestrel/rev-b/backlight/'+text))

def library(folder):
    name='TPS61169DCK'
    effect='(effects (font (size 0.8 0.8)))'
    sym=node(f'(symbol "{name}" (pin_names (offset 0.508)) (in_bom yes) (on_board yes) '
        f'(property "Reference" "U" (at 0 0 0) {effect}) (property "Value" "{name}" (at 0 0 0) {effect}) '
        f'(property "Footprint" "Package_TO_SOT_SMD:Texas_R-PDSO-G5_DCK-5" (at 0 0 0) {effect}) '
        f'(property "Datasheet" "https://www.ti.com/lit/ds/symlink/tps61169.pdf" (at 0 0 0) {effect}))')
    body=node(f'(symbol "{name}_1_1" (rectangle (start -8.89 8.89) (end 8.89 -8.89) (stroke (width 0.254) (type default)) (fill (type background))))')
    for n,name,kind in ((1,'SW','passive'),(2,'GND','power_in'),(3,'FB','input'),(4,'CTRL','input'),(5,'VIN','power_in')):
        body.append(node(f'(pin {kind} line (at -11.43 {round(8.89-n*2.54,2)} 0) (length 2.54) (name "{name}" {effect}) (number "{n}" {effect}))'))
    sym.append(body);library=node('(kicad_symbol_lib (version 20241209) (generator "kicad_symbol_editor"))');library.append(sym)
    (folder/'KestrelDisplay.kicad_sym').write_text(dumps(library)+'\n')
    table=sx.loads((folder/'sym-lib-table').read_text())
    table[:]=[e for e in table if not (isinstance(e,list) and any(isinstance(p,list) and p[:2]==[S('name'),'KestrelDisplay'] for p in e))]
    table.append(node('(lib (name "KestrelDisplay") (type "KiCad") (uri "${KIPRJMOD}/KestrelDisplay.kicad_sym") (options "") (descr "Backlight primary DCK5 pin table"))'))
    (folder/'sym-lib-table').write_text(dumps(table)+'\n')

def build():
    folder=ROOT/'electrical';library(folder)
    path=folder/'kestrel-revb-backlight.kicad_sch'
    path.write_text(f'(kicad_sch (version 20260101) (generator "eeschema") (generator_version "10.0") (uuid "{uid("sheet")}") (paper "A2") (lib_symbols) (sheet_instances (path "/" (page "1"))))')
    res='Resistor_SMD:R_0603_1608Metric';cap='Capacitor_SMD:C_0603_1608Metric'
    parts=[]
    def add(ref,lib,value,foot,x,y,nets,angle=0,unit=1):
        parts.append((ref,lib,value,foot,round(x/GRID),round(y/GRID),angle,nets,unit))
    add('U901','KestrelDisplay:TPS61169DCK','TPS61169DCKR','Package_TO_SOT_SMD:Texas_R-PDSO-G5_DCK-5',80,65,
        {'1':'BL_SW','2':'GND','3':'BL_LED_K','4':'BL_CTRL','5':'+5V_DIG'})
    add('L901','Device:L','10uH / shielded / Isat >=3A / MPN and lands pending','Inductor_SMD:L_Sunlord_MWSA0603S',170,55,{'1':'+5V_DIG','2':'BL_SW'},angle=90)
    add('D901','Diode:SS16','SS16-E3/61T','Diode_SMD:D_SMA',265,55,{'1':'BL_LED_A','2':'BL_SW'},angle=180)
    add('U902','74xGxx:SN74LVC1G125DCK','SN74LVC1G125DCKR','Package_TO_SOT_SMD:Texas_R-PDSO-G5_DCK-5',320,110,
        {'1':'GND','2':'MCU_BL_PWM','3':'GND','4':'BL_CTRL_BUFFER','5':'+5V_DIG'})
    add('R901','Device:R','5.62ohm / 1% / >=0.125W / Kelvin sense','Resistor_SMD:R_0805_2012Metric',70,125,{'1':'BL_LED_K','2':'GND'})
    add('R902','Device:R','10k / 1% / MCU PWM default off',res,170,125,{'1':'MCU_BL_PWM','2':'GND'})
    add('R903','Device:R','1k / 1% / control series',res,265,165,{'1':'BL_CTRL_BUFFER','2':'BL_CTRL'},angle=90)
    add('R904','Device:R','1M / 1% / 1206 / output bleed','Resistor_SMD:R_1206_3216Metric',170,180,{'1':'BL_LED_A','2':'GND'})
    add('R905','Device:R','100k / 1% / CTRL default off',res,70,180,{'1':'BL_CTRL','2':'GND'})
    add('C901','Device:C','4.7uF / 25V X7R / input local','Capacitor_SMD:C_0805_2012Metric',70,230,{'1':'+5V_DIG','2':'GND'})
    add('C902','Device:C','100nF / 16V X7R / VIN bypass',cap,150,230,{'1':'+5V_DIG','2':'GND'})
    add('C903','Device:C','2.2uF / 50V X7R / effective >=1uF at 39V','Capacitor_SMD:C_1210_3225Metric',240,230,{'1':'BL_LED_A','2':'GND'})
    add('C904','Device:C','100nF / 16V X7R / buffer bypass',cap,330,230,{'1':'+5V_DIG','2':'GND'})
    for ref,net,x in [('TP901','BL_LED_A',265),('TP902','BL_LED_K',330)]:
        add(ref,'Connector:TestPoint',net,'TestPoint:TestPoint_Pad_D1.0mm',x,180,{'1':net})
    add('U903','Regulator_Linear:TLV76701DRVx','TLV76701DRVR',
        'Package_SON:WSON-6-1EP_2x2mm_P0.65mm_EP1x1.6mm_ThermalVias',465,65,
        {'1':'LCD_VDD','2':'LCD_FB','3':'GND','4':'+5V_DIG','5':'GND','6':'+5V_DIG','7':'GND'})
    add('R906','Device:R','33.2k / 0.1% / LCD upper feedback',res,435,230,{'1':'LCD_VDD','2':'LCD_FB'})
    add('R907','Device:R','10k / 0.1% / LCD lower feedback',res,515,230,{'1':'LCD_FB','2':'GND'})
    add('C905','Device:C','4.7uF / 16V X7R / effective >=1uF / LCD input','Capacitor_SMD:C_0805_2012Metric',435,170,{'1':'+5V_DIG','2':'GND'})
    add('C906','Device:C','4.7uF / 16V X7R / effective >=1uF / LCD output','Capacitor_SMD:C_0805_2012Metric',515,170,{'1':'LCD_VDD','2':'GND'})
    add('C907','Device:C','10pF / 25V C0G / LCD feedforward',cap,475,280,{'1':'LCD_VDD','2':'LCD_FB'},angle=90)
    add('TP903','Connector:TestPoint','LCD_VDD','TestPoint:TestPoint_Pad_D1.0mm',515,120,{'1':'LCD_VDD'})
    add('U904','Regulator_Linear:TLV76701DRVx','TLV76701DRVR',
        'Package_SON:WSON-6-1EP_2x2mm_P0.65mm_EP1x1.6mm_ThermalVias',465,355,
        {'1':'TOUCH_VDD','2':'TOUCH_FB','3':'GND','4':'+5V_DIG','5':'GND','6':'+5V_DIG','7':'GND'})
    add('R908','Device:R','30k / 0.1% / touch upper feedback',res,350,355,{'1':'TOUCH_VDD','2':'TOUCH_FB'})
    add('R909','Device:R','10k / 0.1% / touch lower feedback',res,390,355,{'1':'TOUCH_FB','2':'GND'})
    add('C908','Device:C','4.7uF / 16V X7R / effective >=1uF / touch input','Capacitor_SMD:C_0805_2012Metric',35,355,{'1':'+5V_DIG','2':'GND'})
    add('C909','Device:C','4.7uF / 16V X7R / effective >=1uF / touch output','Capacitor_SMD:C_0805_2012Metric',125,355,{'1':'TOUCH_VDD','2':'GND'})
    add('C910','Device:C','10pF / 25V C0G / touch feedforward',cap,225,355,{'1':'TOUCH_VDD','2':'TOUCH_FB'},angle=90)
    add('TP904','Connector:TestPoint','TOUCH_VDD','TestPoint:TestPoint_Pad_D1.0mm',540,355,{'1':'TOUCH_VDD'})
    loader=DynamicSymbolLoader(folder)
    for ref,lib,val,foot,x,y,angle,nets,unit in parts:
        family,name=lib.split(':'); loader.inject_symbol_into_schematic(path,family,name)
        assert loader.create_component_instance(path,family,name,ref,val,foot,x*GRID,y*GRID,unit=unit,angle=angle),ref
    tree=sx.loads(path.read_text()); symbols={e[1]:e for e in child(tree,'lib_symbols')[1:]}
    boundary={'+5V_DIG':'input','GND':'bidirectional','MCU_BL_PWM':'input','LCD_VDD':'output',
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

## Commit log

2026-03-13 Update board, readme, image
    [m_pcb.kicad_pcb]
2026-03-20 Fix files, new image, add 3d models, fix board-sides
    [3PDT_Footswitch.step, NMJ nut washer.f3d, NMJ nut washer.step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]
2026-10-04 Add integrated Rev-B PCB draft and checked local routing
    [1590xx-pcb-candidate.step, 1590xx-reference-fit.step, base.step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]
2026-10-04 Route local backlight boost and PWM support
    [kestrel-revb.kicad_pcb]
2026-10-04 Route display source feeds, backlight PWM and LED endpoints
    [kestrel-revb.kicad_pcb]
2026-10-04 Place display connector supports and route supply and default groups
    [kestrel-revb.kicad_pcb]
2026-10-04 Place sixteen RGB source damping resistors on the underside
    [kestrel-revb-display.kicad_sch, kestrel-revb.kicad_pcb]
2026-10-04 Route all sixteen RGB source signals with guarded via-in-pad
    [kestrel-revb-display.kicad_sch, kestrel-revb-mcu.kicad_sch, kestrel-revb.kicad_pcb]
2026-10-04 Complete all sixteen RGB resistor-to-FPC routes
    Coordinate R4/R6 source GPIOs and underside poses with guarded source replacement. Add independently checked output topology, native clearance and preservation evidence, and current schematic/PCB review artifacts.
    [kestrel-revb-display.kicad_sch, kestrel-revb-mcu.kicad_sch, kestrel-revb.kicad_pcb]
2026-10-04 Reserve MCU fanout space with guarded HP and SPI routing changes
    [kestrel-revb.kicad_pcb]
2026-10-04 Preserve native-checked partial timing fanout and finer route search
    [display-timing.kicad_pcb]
2026-10-04 Preserve native-clear PCLK source and guarded trial courtyards
    [display-timing.kicad_pcb]
2026-10-04 Preserve native-clear dual clocks with restored complete RGB routing
    [display-clock-rgb.kicad_pcb]
2026-10-04 Route touch SCL and guard all timing outputs in coordinated trial
    [display-clock-rgb.kicad_pcb]
2026-10-04 Route LCD DE and record checked touch source reservation limits
    [display-clock-rgb.kicad_pcb]
2026-10-04 Route LCD DISP using existing via and enforce drill spacing in proposals
    [display-clock-rgb.kicad_pcb]
2026-10-04 Route touch SDA with coordinated VSYNC and SDA resistor poses
    [display-clock-rgb.kicad_pcb]
2026-10-04 Complete touch reset source and output in guarded display trial
    [display-clock-rgb.kicad_pcb]
2026-10-04 Complete original-pin touch INT source and via-in-pad output trial
    [display-clock-rgb.kicad_pcb]
2026-10-04 Complete guarded timing and touch fanout with northern VSYNC damping
    [display-clock-rgb.kicad_pcb]
2026-10-04 Bring C702 trial bypass allocation within maintained bound
    [display-clock-rgb.kicad_pcb]
2026-10-04 Reserve native-clear MCU reset and chip-select transfers
    [board.kicad_pcb]
